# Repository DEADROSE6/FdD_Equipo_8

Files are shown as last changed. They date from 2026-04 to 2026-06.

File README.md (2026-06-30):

# Equipo 8 - SafeWalk AI (Zonas de Construcción)
### Carrera de Ingeniería Ambiental / Informática / Industrial  
**Universidad Peruana Cayetano Heredia**

---

## Descripción del Equipo 

Somos el Equipo 8 del curso Fundamentos de Diseño 2026-1, conformado por estudiantes de la carrera de Ingeniería Ambiental / Informática / Industrial.  

Nuestro objetivo es aplicar la metodología de diseño para generar soluciones innovadoras con impacto social, tecnológico y ambiental.

---

# DESCRIPCIÓN DEL PROYECTO

El equipo 8 desarrollará SafeWalk AI, este sistema emplea un módulo de captura visual conectado a una plataforma de procesamiento embebido para la adquisición y análisis de imágenes en tiempo real, sin conexión a internet. Estas imágenes son procesadas mediante un modelo de visión artificial encargado de detectar la presencia de personas con discapacidad visual a partir de elementos característicos como el bastón blanco y las gafas oscuras. Al identificar estos elementos, el sistema activa automáticamente una alerta sonora mediante un altavoz, con el fin de advertir sobre la proximidad de una zona de obra o peligro.

Este proyecto surge como respuesta a la vulnerabilidad de las personas con discapacidad visual en entornos urbanos dinámicos como las zonas de construcción, y contribuye a los Objetivos de Desarrollo Sostenible 3, 9, 10 y 11, promoviendo la seguridad, la innovación tecnológica y la construcción de ciudades más inclusivas.

---

# CONTEXTO

El crecimiento de las ciudades peruanas conlleva una ejecución constante de obras de construcción, mantenimiento vial e instalación de servicios públicos que modifican de forma temporal el espacio urbano.En el Perú, la Contraloría General de la República ha identificado que a diciembre de 2025 existen 2,416 obras públicas paralizadas a nivel nacional, siendo Lima uno de los departamentos con mayor número de obras detenidas con 167 proyectos paralizados [1].

Esta situación representa un riesgo especialmente grave para las personas con discapacidad visual. A diferencia del resto de peatones, estas personas se orientan en la ciudad mediante rutas memorizadas, apoyándose en referencias como la cantidad de pasos, la textura del suelo y los sonidos del entorno. Cuando una obra clausura o modifica una vereda, esa ruta memorizada deja de coincidir con la realidad, exponiéndose a caídas. Un estudio del Banco Interamericano de Desarrollo concluyó que las personas con discapacidad visual son las más afectadas por las barreras presentes en el entorno urbano, especialmente en espacios donde la infraestructura cambia de forma temporal e imprevista [2]. 

---

# EVIDENCIA DEL PROBLEMA

En el Perú, las obras de construcción en espacios urbanos representan un riesgo concreto para los peatones. Según la Organización Internacional del Trabajo, el sector construcción concentra un alto porcentaje de accidentes a nivel mundial, en parte por las condiciones dinámicas y cambiantes de las obras, y por la señalización frecuentemente insuficiente o inadecuada en estos espacios [3].

Esta problemática se vuelve crítica para las personas con discapacidad visual. Los Censos Nacionales 2017 del INEI revelaron que aproximadamente 1,966,766 personas en el Perú experimentan limitaciones permanentes en la visión, de las cuales el 52.6% reside en zonas urbanas [4]. Estas personas se desplazan guiándose por referencias espaciales memorizadas (cantidad de pasos, texturas del suelo, sonidos del entorno) que les permiten construir rutas mentales conocidas. Cuando una obra clausura o modifica temporalmente una vereda, esa ruta memorizada deja de coincidir con la realidad física, exponiéndolas a caídas, colisiones con materiales de construcción o desvíos involuntarios hacia la calzada vehicular.  

Esta realidad no es abstracta. Roxana, una mujer de 56 años con discapacidad visual residente en Arequipa que utiliza el bastón blanco desde hace más de una década, describe con precisión el impacto que tienen las obras en su desplazamiento diario: "Cada vez que se realizan obras en Arequipa, abren el pavimento y lo dejan amontonado: escombros, arena, tierra, ladrillos y cascajos ocupan las veredas. Todo eso representa un obstáculo para desplazarnos. El bastón se nos atasca en esos huecos". Este testimonio refleja una problemática extendida en las ciudades peruanas, donde las intervenciones en la infraestructura urbana no contemplan mecanismos de aviso accesibles para personas invidentes [5]. 

# JUSTIFICACIÓN DEL PROYECTO

Frente a esta problemática, surge la necesidad de desarrollar soluciones tecnológicas que protejan a las personas con discapacidad visual en zonas de obra. En el Perú, la Norma Técnica A.120 de Accesibilidad Universal del Reglamento Nacional de Edificaciones establece la obligatoriedad de señalización accesible en espacios de construcción, incluyendo señalización podotáctil y auditiva en zonas de riesgo [6]. Sin embargo, su implementación es deficiente: en 2026, el 85% de las inspecciones de CONADIS reportaron incumplimientos en señalética, evidenciando que las normas existentes no se traducen en acciones concretas en los espacios de obra [6]. 

Las medidas tradicionales de seguridad en zonas de obra  (cintas de advertencia, conos de señalización, carteles informativos y barreras físicas) dependen exclusivamente de la percepción visual y no ofrecen ningún tipo de alerta para quienes no pueden verlas. Esta brecha evidencia la necesidad de incorporar soluciones complementarias que utilicen el canal auditivo para transmitir información de riesgo de manera efectiva a las personas invidentes que se aproximan a una zona de obra.

---

# ¿Cómo funciona el proyecto?

## Captura de imágenes
El sistema utiliza un módulo de captura visual integrado en la plataforma de procesamiento embebido, el cual adquiere imágenes del entorno en tiempo real para su análisis inmediato.

## Procesamiento e inferencia
La plataforma embebida recibe y procesa las imágenes mediante un modelo de visión artificial ligero, capaz de detectar elementos característicos de personas con discapacidad visual como el bastón blanco, operando de forma local sin depender de conexión a internet.

## Control del sistema
Una vez procesada la imagen, la plataforma envía señales a una unidad de control que gestiona los dispositivos de salida del sistema, garantizando una respuesta rápida y coordinada.

## Activación de alerta
Al confirmar la detección, se activa automáticamente una alerta sonora que advierte sobre la proximidad de zonas de riesgo.

## Función del sistema
SafeWalk AI busca prevenir accidentes y mejorar la seguridad del peatón con discapacidad visual mediante alertas oportunas, contribuyendo a entornos urbanos más inclusivos y accesibles.

---

# OBJETIVOS DE DESARROLLO SOSTENIBLE

Los Objetivos de Desarrollo Sostenible (ODS) son un conjunto de metas globales establecidas por la Organización de las Naciones Unidas como parte de la Agenda 2030 para el Desarrollo Sostenible, adoptada en el año 2015 por los Estados miembros [7]. Estos objetivos buscan orientar los esfuerzos de los países hacia un desarrollo que permita mejorar la calidad de vida de las personas, reducir las desigualdades y proteger el planeta.

# Nos interesa trabajar en los siguientes Objetivos de Desarrollo Sostenible (ODS):

**ODS 3: Salud y bienestar**

Una de las metas de este objetivo, específicamente la meta 3.6, establece la necesidad de reducir el número de muertes y lesiones causadas por accidentes en entornos de riesgo para el año 2030 [7]. En el contexto urbano, esto implica desarrollar medidas que protejan a los grupos más vulnerables, especialmente en espacios como zonas de construcción, donde existen múltiples peligros asociados a maquinaria, excavaciones y cambios constantes en la infraestructura [8].

Nuestro proyecto se relaciona con este objetivo porque busca reducir el riesgo de accidentes en zonas de construcción para personas con discapacidad visual, contribuyendo a preservar su integridad física y promover su bienestar. 

---

**ODS 9: Industria, innovación e infraestructura**

Una de las metas de este objetivo plantea la necesidad de modernizar la infraestructura e incorporar tecnologías que permitan hacerla más segura, eficiente e inclusiva (9). En el contexto urbano, esto incluye la implementación de sistemas inteligentes capaces de adaptarse a entornos dinámicos como las zonas de construcción.

Nuestro proyecto se vincula con este objetivo porque propone el uso de herramientas tecnológicas como cámaras, inteligencia artificial y algoritmos de detección de objetos en tiempo real para mejorar la seguridad en estos espacios.

---

**ODS 10: Reducción de las desigualdades**

En muchos casos, las personas con discapacidad enfrentan dificultades para desplazarse en el entorno urbano debido a la falta de infraestructura accesible, especialmente en espacios temporales como zonas de obra. Estas limitaciones generan una brecha en el acceso seguro al espacio público.

De acuerdo con la Organización Mundial de la Salud, una gran proporción de la población mundial presenta algún tipo de discapacidad, lo que evidencia la necesidad de desarrollar soluciones inclusivas que mejoren su calidad de vida [7].
Nuestro proyecto se relaciona con este objetivo porque busca reducir estas barreras mediante el uso de tecnología. A través de la detección en tiempo real de personas con discapacidad visual y la generación de alertas auditivas en zonas de construcción.

---

**ODS 11: Ciudades y comunidades sostenibles**

Una de las metas de este objetivo está relacionada con mejorar la seguridad y accesibilidad de los espacios urbanos, garantizando que estos sean inclusivos para todos los ciudadanos, especialmente los grupos más vulnerables [7].

El proyecto propuesto se relaciona con este objetivo porque busca contribuir al desarrollo de ciudades más seguras mediante la incorporación de tecnología en infraestructura temporal. Al implementar un sistema que detecte en tiempo real a personas con discapacidad visual y emita alertas sonoras en zonas de construcción, se promueve una mayor accesibilidad y seguridad en el entorno urbano.

---

## Fotografía del Equipo 
<p align="center">
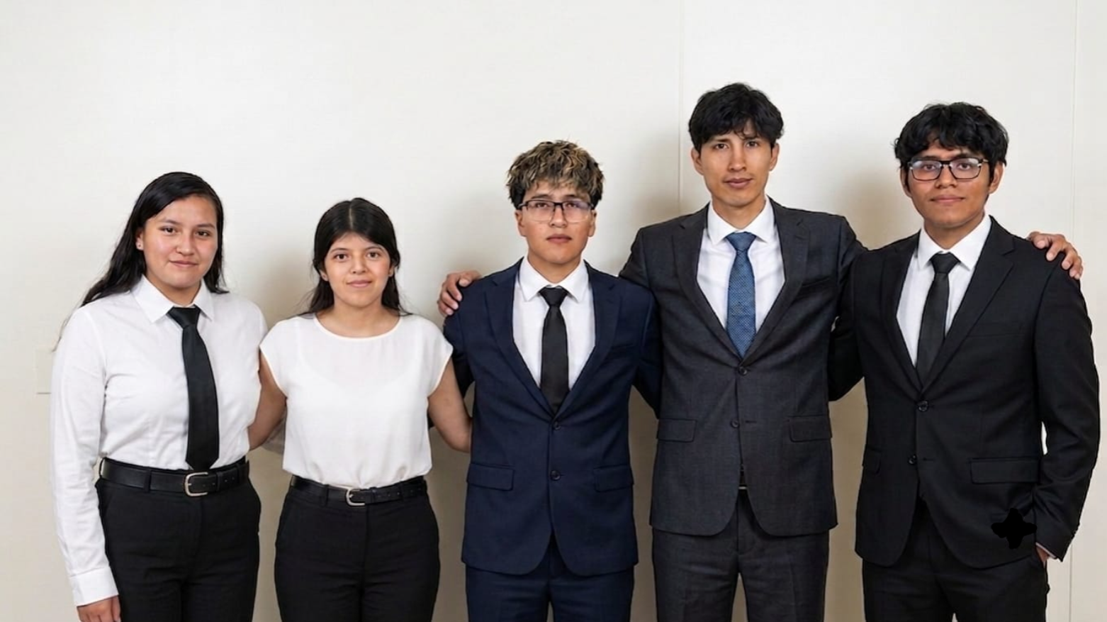
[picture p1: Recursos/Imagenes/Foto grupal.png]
imagen_alumnos_IA

  <em>Figura 1. Fotografía del equipo 8</em>
</p>

---

## Integrantes del Equipo  

| Foto | Nombre | Rol | Intereses |
|---|---|-----|---|
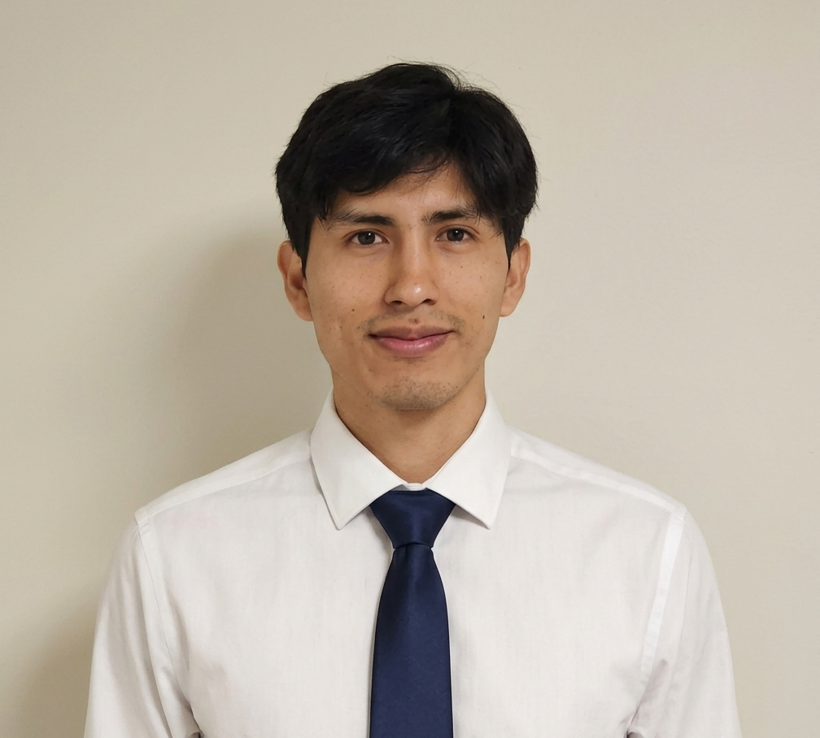
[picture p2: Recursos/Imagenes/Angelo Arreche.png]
|  | **Angello Areche Espeza** | Técnico de Hardware y Prototipos | Diseña, integra y ensambla el prototipo físico del sistema. Se encarga de la selección, conexión y validación de los componentes electrónicos, realizando pruebas de funcionamiento para garantizar la correcta operación del dispositivo. |
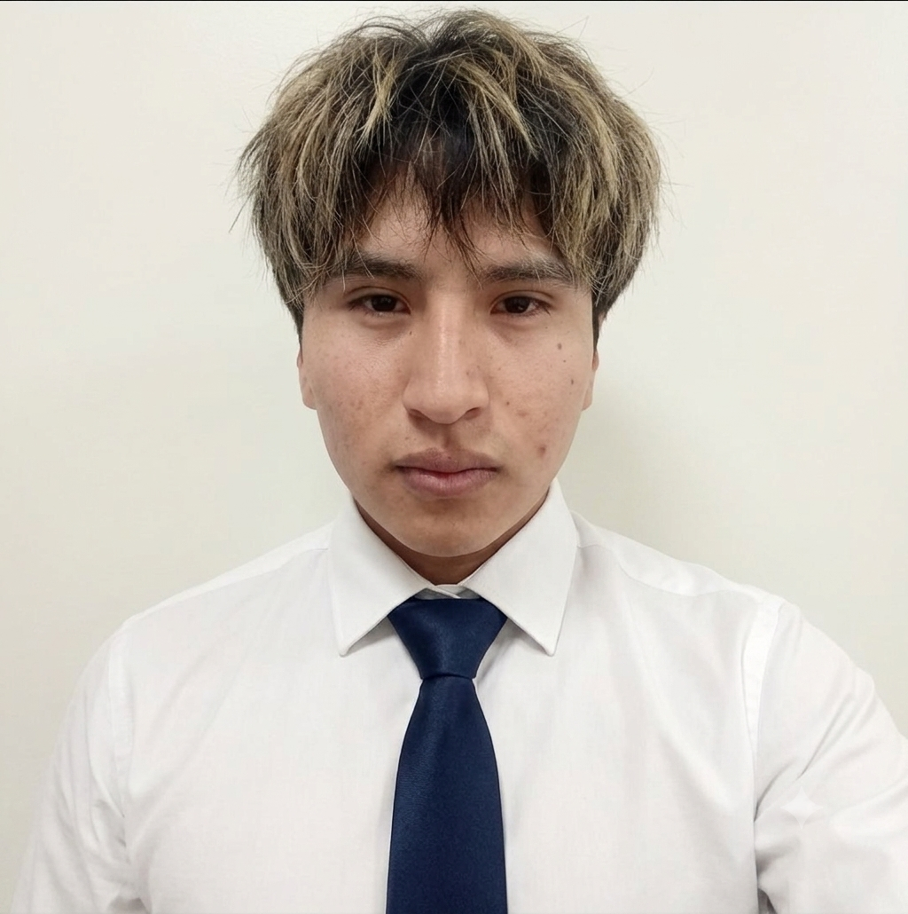
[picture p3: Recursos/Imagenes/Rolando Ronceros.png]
|  | **Rolando Ronceros Huaynapomas** | Diseñador de Arquitectura del Sistema | Define la arquitectura general del proyecto, estableciendo la interacción entre los módulos de hardware y software. Diseña el flujo de funcionamiento del sistema y asegura una integración eficiente entre todos los componentes. |
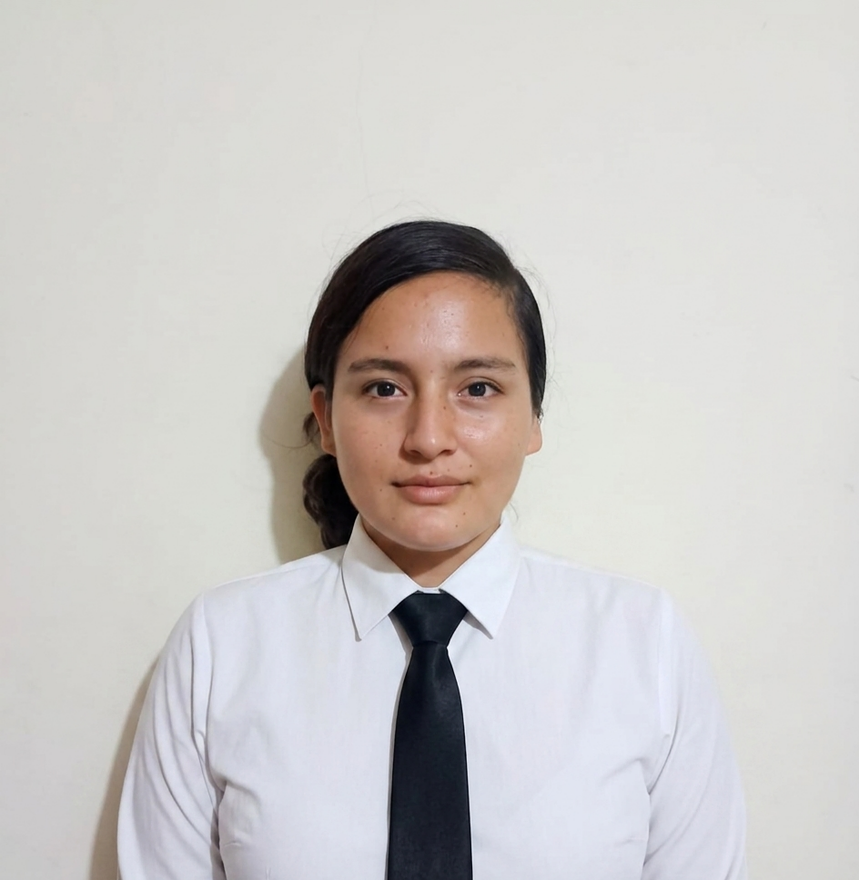
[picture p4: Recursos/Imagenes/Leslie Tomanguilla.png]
|  | **Leslie Stephany Tomanguilla Huaman** | Analista Funcional del Sistema | Analiza la problemática y define los requerimientos funcionales del sistema. Establece las funcionalidades principales y verifica que la solución propuesta responda a las necesidades de las personas con discapacidad visual. |
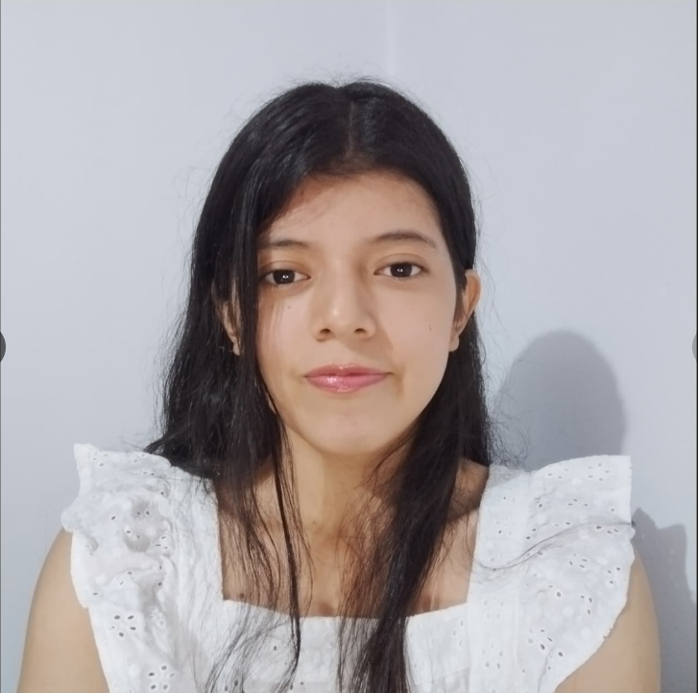
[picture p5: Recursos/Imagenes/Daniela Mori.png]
|  | **Daniela Mori Mendoza** |  Gestora de Documentación | Organiza, redacta y mantiene actualizada toda la documentación del proyecto. Gestiona los informes, la documentación técnica, el repositorio GitHub y el registro de avances para garantizar claridad y organización de la información. |
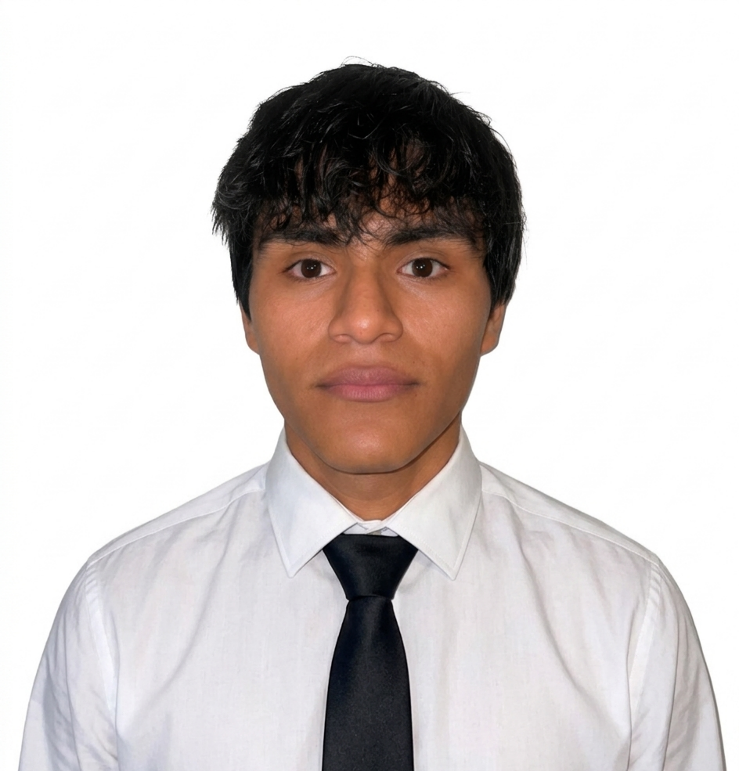
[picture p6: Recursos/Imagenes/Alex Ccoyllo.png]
|  | **Alex Jhosep Ccoyllo Sotelo** | Desarrollador de Sistemas Embebidos | Implementa la lógica de funcionamiento del sistema, integrando el procesamiento de datos provenientes de los sensores y la cámara. Desarrolla las funciones necesarias para la detección del entorno y la generación de alertas por voz, asegurando la comunicación entre los módulos del sistema. |

---

## Resumen Final  
El Equipo 8 está conformado por estudiantes comprometidos con generar un impacto positivo en la sociedad mediante soluciones tecnológicas innovadoras. En esta nueva propuesta, se ha decidido trabajar con los ODS 3, 9, 10 y 11 ,los cuales abordan problemáticas relacionadas con la seguridad ciudadana, el desarrollo de ciudades seguras y la implementación de tecnología para mejorar la calidad de vida.

---

# Referencias Bibliográficas

**1.** Contraloría General de la República del Perú. Informe de obras públicas paralizadas en el territorio nacional a diciembre 2025. https://cdn.www.gob.pe/uploads/document/file/9416533/7715417-informe-de-obras-publicas-paralizadas-en-el-territorio-nacional-a-diciembre-2025f.PDF  

**2.** Rodríguez Porcel M, Lee S, Sandoval D, Tascón Valencia J, Jaramillo PJ, Pedraza L. Auditoría georreferenciada y diagnóstico de accesibilidad peatonal de personas con discapacidad en la primera y última milla de un viaje. https://publications.iadb.org/es/auditoria-georreferenciada-y-diagnostico-de-accesibilidad-peatonal-de-personas-con-discapacidad-en  

**3.** Organización Internacional del Trabajo. Seguridad y salud en la construcción. https://www.ilo.org/es/resource/otros/seguridad-y-salud-en-la-construccion-edicion-revisada  

**4.** Instituto Nacional de Estadística e Informática. Perfiles sociodemográficos de la población con discapacidad https://www.inei.gob.pe/media/MenuRecursivo/publicaciones_digitales/Est/Lib1675/libro.pdf  

**5.** Radio Yaráví Arequipa. Personas con discapacidad visual enfrentan desafíos en calles de Arequipa. https://radioyaravi.org.pe/noticia/informes-especiales/personas-con-discapacidad-visual-enfrentan-desafios-en-calles-de-arequipa/  

**6.** Seminario-Hurtado N, Alfaro Torres HM. Accesibilidad en entornos urbanos para personas con discapacidad visual en el Perú: un análisis normativo. https://revistas.javeriana.edu.co/index.php/cvyu/article/view/41190/ 

**7.** World Health Organization. World Report on Disability. 2011. https://www.who.int/publications/i/item/9789241564182 

**8.** International Labour Organization. Safety and Health in Construction. 2022. https://www.ilo.org/global/publications/books/WCMS_159358/lang--en/index.htm 

**9.** OSHA. Construction Industry Standards. 2024. https://www.osha.gov/laws-regs/regulations/standardnumber/1926

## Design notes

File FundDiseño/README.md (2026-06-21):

# Fundamentos de Diseño

Esta carpeta debe contener todo lo relacionado al avance del proyecto, incluyendo:

* Documentación técnica y de entregables
* Presentaciones
* Informes de Talleres

Aquí se centraliza la información y los archivos necesarios para el desarrollo, seguimiento y presentación del proyecto, facilitando la organización y el acceso a los materiales relevantes.

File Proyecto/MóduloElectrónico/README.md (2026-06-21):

# Esquemáticos

Contiene los esquemáticos electrónicos del proyecto SafeWalk AI, elaborados por el Grupo 08 de Fundamentos de Diseño (UPCH).

* **Esquematico\_VFinal\_DISEÑO.pdf** — Esquemático versión final. Incluye todos los módulos del sistema: sensor de distancia (VL53L1X), módulo principal (XIAO ESP32-S3), sensor de presencia (LD2410C), alerta sonora (PAM8403 + altavoz), reproductor de audio (DFPlayer Mini), LED indicador y módulo de carga (TP4056 + LiPo + XL6009 boost converter).
* **Esquema\_electronico\_E08.pdf** — Esquemático versión E08. Contiene los mismos módulos funcionales que la versión final, sin el módulo de carga ni el reproductor de audio.

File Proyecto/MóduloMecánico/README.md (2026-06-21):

Este apartado contiene los archivos de diseño y modelado 3D (en formato `.stl`) necesarios para la fabricación, impresión y ensamblaje de la estructura física de la estación meteorológica.

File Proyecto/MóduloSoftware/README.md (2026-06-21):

El sistema recopila variables ambientales en tiempo real, procesa los datos localmente y los transmite para su visualización remota.

\---

\## 🛠️ Hardware y Pinout

\### Componentes Principales

\* \*\*Microcontrolador\*\* compatible con Arduino IoT Cloud.

\* \*\*SparkFun Weather Meter Kit\*\* (Anemómetro, Veleta y Pluviómetro).

\* \*\*Sensor BME280\*\* (Temperatura, Humedad y Presión).

\* \*\*Sensor VEML6075\*\* (Luz UVA, UVB e Índice UV).

\* \*\*Sensor AS3935\*\* (Detección de Rayos y Tormentas).

\* \*\*Sensor Higrómetro\*\* (Humedad del Suelo).

\### Asignación de Pines

| Componente / Función | Pin Digital/Analógico |

| :--- | :--- |

| \*\*Dirección del Viento (Veleta)\*\* | Pin 35 |

| \*\*Velocidad del Viento (Anemómetro)\*\* | Pin 14 |

| \*\*Pluviómetro (Lluvia)\*\* | Pin 27 |

| \*\*Interrupción AS3935 (Rayos)\*\* | Pin 17 |

| \*\*Chip Select (CS) AS3935\*\* | Pin 25 |

| \*\*Señal de Humedad de Suelo\*\* | Pin 34 |

| \*\*Alimentación Humedad de Suelo\*\* | Pin 15 |

\---

\## 💻 Configuración del Software

\### Librerías Requeridas

\* `Wire.h` y `SPI.h` (Comunicación nativa).

\* `SparkFun\_Weather\_Meter\_Kit\_Arduino\_Library.h`.

\* `SparkFunBME280.h`.

\* `SparkFun\_VEML6075\_Arduino\_Library.h`.

\* `SparkFun\_AS3935.h`.

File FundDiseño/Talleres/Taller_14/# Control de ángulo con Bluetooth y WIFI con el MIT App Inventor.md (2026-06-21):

# Informe Técnico de Proyecto: Control de Servomotor mediante Bluetooth con ESP32

---

## 1. Introducción
El presente informe detalla el procedimiento de diseño, configuración e implementación de un sistema de control inalámbrico para un servomotor de rango extendido (0° a 270°) utilizando el microcontrolador ESP32 y una aplicación móvil personalizada desarrollada en la plataforma MIT App Inventor. La comunicación entre ambos dispositivos se realiza mediante el protocolo Bluetooth Clásico.

---

## 2. Componentes Utilizados
* **Microcontrolador:** ESP32 (NodeMCU-32S o equivalente).
* **Actuador:** Servomotor de rango extendido (0° - 270°).
* **Software de Desarrollo:** Arduino IDE.
* **Plataforma de Aplicación Móvil:** MIT App Inventor.
* **Conectividad:** Bluetooth Clásico integrado en el chip ESP32.
* **Cableado:** Cables jumper (Macho-Hembra / Macho-Macho) y cable de datos Micro-USB.

---

## 3. Conexiones Físicas (Hardware)
El circuito se estructuró conectando el servomotor directamente a la placa ESP32, alimentándose a través del voltaje provisto por el puerto USB (5V) de la siguiente manera:

| Cable del Servomotor | Función | Pin en el ESP32 |
| :--- | :--- | :--- |
| **Negro** | Tierra (GND) | GND |
| **Rojo** | Alimentación (VCC) | VIN / 5V |
| **Blanco** | Señal de Control (PWM) | GPIO 18 (D18) |

---

## 4. Desarrollo de la Aplicación Móvil (MIT App Inventor)

### 4.1 Componentes de la Interfaz
Se dispuso una interfaz minimalista y funcional compuesta por:
1.  **ListPicker (Selector de Lista):** Renombrado como `Conectar_Bluetooth`. Filtra y muestra los dispositivos Bluetooth vinculados en el smartphone.
2.  **Label (Etiqueta):** Renombrada como `Ángulo`. Muestra en pantalla el valor entero del ángulo actual seleccionado.
3.  **Slider (Deslizador):** Configurado con un valor mínimo (`MinValue`) de **0** y un valor máximo (`MaxValue`) de **270** para ajustarse al límite físico del motor.
4.  **BluetoothClient1:** Componente no visible encargado de la gestión del canal de comunicación inalámbrica.

### 4.2 Lógica de Bloques Utilizada
* **Antes de la Selección (`BeforePicking`):** Se cargan en el `ListPicker` las direcciones y nombres de los dispositivos emparejados en el sistema del celular.
* **Después de la Selección (`AfterPicking`):** Se efectúa la llamada de conexión hacia la dirección MAC del dispositivo seleccionado a través de un bloque puente `evaluate but ignore result` para mitigar restricciones de tipo de datos de algunas versiones de la plataforma.
* **Cambio de Posición del Slider (`PositionChanged`):** Al desplazar el control, el valor flotante se procesa mediante la función matemática `round` para obtener un número entero. Este entero es visualizado en la etiqueta de texto y se envía mediante `.SendText` concatenado con un caracter de escape de nueva línea (`\n`) para actuar como delimitador de mensajes.

---

## 5. Código Fuente Definitivo (Firmware ESP32)

El código implementado en el lenguaje de Arduino utiliza la librería nativa para la emulación del puerto serie por Bluetooth y la librería especializada `ESP32Servo` para la gestión precisa de los pulsos PWM sobre la arquitectura del procesador.

```cpp
#include "BluetoothSerial.h"
#include <ESP32Servo.h>

// Instancia para el control del Bluetooth y del Servomotor
BluetoothSerial ESP_BT;
Servo miServo;

// Definición de constantes del hardware
const int pinServo = 18; 

void setup() {
  // Inicialización del puerto serie físico para depuración técnica
  Serial.begin(115200);
  
  // Inicialización del módulo Bluetooth con el identificador de red
  ESP_BT.begin("Prueba_ESP32"); 
  Serial.println("Dispositivo listo con control de Servo (Rango: 0-270).");

  // Configuración de temporizadores internos de la librería ESP32Servo
  ESP32PWM::allocateTimer(0);          
  miServo.setPeriodHertz(50); // Frecuencia de actualización estándar para servos (50Hz)
  
  // Acoplamiento del pin con los anchos de pulso en microsegundos mínimos y máximos
  // Ajustados para cubrir el espectro angular completo de 270 grados
  miServo.attach(pinServo, 500, 2500); 
  
  // Posicionamiento inicial de seguridad
  miServo.write(0); 
}

void loop() {
  // Verificación de bytes disponibles en el buffer del módulo Bluetooth
  if (ESP_BT.available()) {
    
    // Lectura de la cadena de texto entrante hasta encontrar el delimitador '\n'
    String datosRecibidos = ESP_BT.readStringUntil('\n');
    datosRecibidos.trim(); // Eliminación de espacios en blanco o caracteres basura

    // Validación de consistencia del dato extraído
    if (datosRecibidos.length() > 0) {
      int angulo = datosRecibidos.toInt(); // Conversión de la cadena de texto a entero

      // Control de límites lógicos para proteger los engranajes del motor
      if (angulo >= 0 && angulo <= 270) {
        miServo.write(angulo); // Escritura de la posición angular en el actuador
        
        // Retroalimentación visual en el terminal de la computadora
        Serial.print("Moviendo servo a: ");
        Serial.print(angulo);
        Serial.println(" grados.");
      }
    }
  }
  delay(10); // Retraso de cortesía para estabilizar las tareas de fondo del procesador
}
```
---

## 6. Procedimiento de Carga y Pruebas
1. **Instalación de Librerías:** Desde el gestor de tarjetas del Arduino IDE se integró la librería `ESP32Servo` de Kevin Harrington, solventando el error de compilación por falta de dependencias.
2. **Carga del Firmware (Bootloader):** Durante el proceso de compilación y subida, ante la secuencia de conexión (`Connecting......`), se hizo uso del bypass de hardware presionando el botón físico **BOOT** integrado en el ESP32 para permitir la escritura en la memoria Flash.
3. **Sincronización:** Se habilitó el servicio de Bluetooth y Localización en el terminal Android, vinculando exitosamente el dispositivo bajo el nombre de `Prueba_ESP32`.
4. **Prueba de la Aplicación:** Se desplegó la interfaz mediante *MIT AI2 Companion*, efectuando la conexión y verificando la transmisión asíncrona de datos tanto en la pantalla del móvil (actualización del Label) como en el Monitor Serie a una tasa de transferencia de `115200` baudios.

---

## 7. Conclusiones
El proyecto cumple exitosamente con los objetivos planteados. El uso del delimitador `\n` garantiza que el ESP32 segmente de manera asíncrona y exacta las cadenas de caracteres entrantes por el flujo serie inalámbrico, evitando el encolamiento de datos erróneos. El ajuste de los tiempos de ancho de pulso en microsegundos (`500` a `2500` µs) en la función `attach` permitió aprovechar el torque y el recorrido completo de los 270° del servomotor de manera lineal y fluida con respecto al deslizador de la aplicación móvil.

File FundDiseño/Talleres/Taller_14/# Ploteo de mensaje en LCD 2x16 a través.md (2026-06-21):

# Informe de desarrollo: Comunicación Bluetooth entre ESP32 y pantalla LCD I2C mediante MIT App Inventor

## 1. Título del proyecto

**Visualización de mensajes en una pantalla LCD I2C mediante comunicación Bluetooth con ESP32 y MIT App Inventor**

---

## 2. Objetivo

El objetivo de la actividad fue implementar un sistema que permita enviar un mensaje escrito desde una aplicación móvil creada en MIT App Inventor hacia un microcontrolador ESP32 mediante comunicación Bluetooth.

El mensaje recibido por el ESP32 debía mostrarse en una pantalla LCD 16x2 con módulo I2C.

---

## 3. Materiales utilizados

Para el desarrollo de la actividad se utilizaron los siguientes materiales:

- ESP32 DevKit V1.
- Pantalla LCD 16x2 con módulo I2C.
- Cables Dupont.
- Cable USB para programar el ESP32.
- Celular Android.
- Plataforma MIT App Inventor.
- Arduino IDE.

### Librerías

- BluetoothSerial
- Wire
- LiquidCrystal_I2C

---

## 4. Descripción general del funcionamiento

El sistema funciona de la siguiente manera:

1. El usuario escribe un mensaje en una aplicación móvil creada en MIT App Inventor.
2. Al presionar un botón, la aplicación envía el mensaje por Bluetooth al ESP32.
3. El ESP32 recibe el texto enviado desde el celular.
4. Finalmente, el mensaje se muestra en la pantalla LCD I2C.

La pantalla LCD utilizada cuenta con un módulo I2C en la parte posterior, por lo que solo se emplearon cuatro pines de conexión:

- GND
- VCC
- SDA
- SCL

No fue necesario utilizar potenciómetro externo ni resistencia, ya que el módulo I2C de la pantalla incluye un potenciómetro integrado para regular el contraste.

---

## 5. Conexiones realizadas

Las conexiones entre el ESP32 y la pantalla LCD I2C fueron las siguientes:

| Pantalla LCD I2C | ESP32 DevKit V1 |
|---|---|
| GND | GND |
| VCC | 5V / VIN |
| SDA | GPIO 21 |
| SCL | GPIO 22 |

Se utilizó el pin GPIO 21 del ESP32 para la línea SDA y el pin GPIO 22 para la línea SCL, que son los pines comúnmente usados para comunicación I2C en el ESP32.

---

## 6. Programación del ESP32

Para programar el ESP32 se utilizó Arduino IDE. Primero se instalaron las librerías necesarias para controlar la pantalla LCD I2C y utilizar la comunicación Bluetooth.

La librería principal para la pantalla fue:

```cpp
#include <LiquidCrystal_I2C.h>
```

También se utilizaron las librerías:

```cpp
#include <BluetoothSerial.h>
#include <Wire.h>
```

El código cargado en el ESP32 permite:

- Iniciar el Bluetooth con el nombre `ESP32_LCD_BT`.
- Inicializar la pantalla LCD.
- Esperar mensajes enviados desde la aplicación móvil.
- Mostrar el mensaje recibido en la pantalla LCD.
- Dividir el mensaje en dos líneas si supera los 16 caracteres.

---

## 7. Código utilizado en el ESP32

```cpp
#include <BluetoothSerial.h>
#include <Wire.h>
#include <LiquidCrystal_I2C.h>

// Bluetooth del ESP32
BluetoothSerial SerialBT;

// LCD I2C 16x2
// Direccion comun: 0x27
// Si no funciona, cambiar 0x27 por 0x3F
LiquidCrystal_I2C lcd(0x27, 16, 2);

String mensaje = "";

void setup() {

  Serial.begin(115200);

  // Iniciar I2C en ESP32
  // SDA = GPIO 21, SCL = GPIO 22
  Wire.begin(21, 22);

  // Iniciar LCD
  lcd.init();
  lcd.backlight();
  lcd.clear();

  lcd.setCursor(0, 0);
  lcd.print("Esperando BT");

  lcd.setCursor(0, 1);
  lcd.print("ESP32_LCD_BT");

  // Iniciar Bluetooth
  SerialBT.begin("ESP32_LCD_BT");

  Serial.println("Bluetooth iniciado");
  Serial.println("Nombre: ESP32_LCD_BT");
}

void loop() {

  // Si llega un mensaje desde App Inventor por Bluetooth
  if (SerialBT.available()) {

    mensaje = SerialBT.readStringUntil('\n');
    mensaje.trim();

    Serial.print("Mensaje recibido: ");
    Serial.println(mensaje);

    lcd.clear();

    // Si el mensaje tiene 16 caracteres o menos
    if (mensaje.length() <= 16) {
      lcd.setCursor(0, 0);
      lcd.print(mensaje);
    }

    // Si el mensaje tiene más de 16 caracteres
    else {
      lcd.setCursor(0, 0);
      lcd.print(mensaje.substring(0, 16));

      lcd.setCursor(0, 1);
      lcd.print(mensaje.substring(16, 32));
    }
  }
}
```

---

## 8. Desarrollo de la aplicación en MIT App Inventor

En MIT App Inventor se creó una aplicación sencilla con los siguientes componentes:

| Componente | Función |
|---|---|
| Label | Mostrar el título de la aplicación |
| ListPicker | Seleccionar el dispositivo Bluetooth |
| TextBox | Escribir el mensaje que se desea enviar |
| Button | Enviar el mensaje al ESP32 |
| Label | Mostrar el estado de conexión |
| BluetoothClient | Permitir la comunicación Bluetooth |

La aplicación permite seleccionar el dispositivo Bluetooth previamente emparejado, conectarse al ESP32 y enviar el texto escrito en el cuadro de texto.

---

## 9. Componentes usados en MIT App Inventor

Los componentes usados fueron:

- Label1: título de la aplicación.
- ListPicker1: botón para seleccionar el Bluetooth.
- TextBox1: cuadro donde se escribe el mensaje.
- Button1: botón para enviar el mensaje.
- Label2: muestra el estado de la conexión.
- BluetoothClient1: componente no visible para la comunicación Bluetooth.

---

## 10. Bloques implementados en MIT App Inventor

### 10.1. Bloque para mostrar dispositivos Bluetooth

Este bloque permite que, antes de seleccionar un dispositivo, se cargue la lista de dispositivos Bluetooth disponibles y emparejados en el celular.

```text
when ListPicker1.BeforePicking
    set ListPicker1.Elements to BluetoothClient1.AddressesAndNames
```

### 10.2. Bloque para conectar con el ESP32

Este bloque permite conectarse al dispositivo Bluetooth seleccionado. Si la conexión es exitosa, se muestra el mensaje "Estado: conectado". Si no se logra conectar, se muestra un mensaje de error.

```text
when ListPicker1.AfterPicking
    if call BluetoothClient1.Connect address ListPicker1.Selection
    then
        set Label2.Text to "Estado: conectado"
    else
        set Label2.Text to "No se pudo conectar"
```

### 10.3. Bloque para enviar el mensaje

Este bloque permite enviar el texto escrito en el TextBox hacia el ESP32. Se agregó el salto de línea `\n` al final del mensaje, ya que el código del ESP32 lee el texto hasta encontrar ese carácter.

```text
when Button1.Click
    if BluetoothClient1.IsConnected
    then
        call BluetoothClient1.SendText text join TextBox1.Text "\n"
        set Label2.Text to "Mensaje enviado"
    else
        set Label2.Text to "Primero conecta Bluetooth"
```

---

## 11. Pruebas realizadas

Después de cargar el programa en el ESP32, se abrió el Monitor Serial a 115200 baudios.

Se verificó que el ESP32 iniciara correctamente mostrando el mensaje:

```text
Bluetooth iniciado
Nombre: ESP32_LCD_BT
```

Luego se revisó que la pantalla LCD encendiera y mostrara el mensaje inicial:

```text
Esperando BT
ESP32_LCD_BT
```

Después, se probó la aplicación móvil siguiendo estos pasos:

1. Se encendió el ESP32.
2. Se abrió la aplicación creada en MIT App Inventor.
3. Se presionó el botón para conectar Bluetooth.
4. Se seleccionó el dispositivo correspondiente al ESP32.
5. Se escribió un mensaje en el cuadro de texto.
6. Se presionó el botón de enviar.
7. El mensaje enviado se mostró en la pantalla LCD.

---

## 12. Observaciones

Durante el desarrollo se identificó que la pantalla LCD tenía un módulo I2C integrado, por lo que no era necesario realizar la conexión tradicional usando los pines:

- RS
- RW
- E
- D4
- D5
- D6
- D7

Esto permitió simplificar el circuito, utilizando únicamente cuatro cables.

También se observó que el contraste de la pantalla puede regularse usando el pequeño potenciómetro integrado en el módulo I2C de la parte posterior de la pantalla.

En caso de que la pantalla no muestre texto, se puede probar cambiando la dirección I2C de:

```cpp
LiquidCrystal_I2C lcd(0x27, 16, 2);
```

por:

```cpp
LiquidCrystal_I2C lcd(0x3F, 16, 2);
```

---

## 13. Problemas encontrados

Durante las pruebas se observó que el ESP32 mostraba en el Monitor Serial un mensaje relacionado con el arranque del sistema:

```text
Core dump data check failed
```

Sin embargo, el programa continuó ejecutándose correctamente, ya que luego apareció el mensaje:

```text
Bluetooth iniciado
Nombre: ESP32_LCD_BT
```

Por lo tanto, se concluyó que el ESP32 estaba funcionando correctamente y que el Bluetooth se había iniciado.

También se consideró que, si el celular no detecta el dispositivo Bluetooth, se debe verificar lo siguiente:

- Que el ESP32 esté encendido.
- Que el programa esté cargado correctamente.
- Que el celular sea Android.
- Que se esté usando un ESP32 compatible con Bluetooth clásico.
- Que el Bluetooth del celular esté activado.
- Que el ESP32 se busque desde los ajustes Bluetooth del celular antes de usar la app.

---

## 14. Conclusión

Se logró implementar un sistema de comunicación Bluetooth entre una aplicación móvil creada en MIT App Inventor y un ESP32.

El mensaje escrito desde el celular fue enviado correctamente al microcontrolador y mostrado en una pantalla LCD 16x2 con módulo I2C.

Esta actividad permitió comprender el uso de la comunicación Bluetooth en el ESP32, el manejo de pantallas LCD mediante I2C y la integración entre hardware y una aplicación móvil desarrollada de manera visual en MIT App Inventor.

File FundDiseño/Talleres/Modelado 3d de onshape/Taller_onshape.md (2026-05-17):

\[Visitar página](https://cad.onshape.com/documents/761ca72c0d35637bf1310327/w/2c1eae061603c23732c825c3/e/0067304d9aebd7f837c99007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\&uiState=6a09e681478a19db214c9cd3)

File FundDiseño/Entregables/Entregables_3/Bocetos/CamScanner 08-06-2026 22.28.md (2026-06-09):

z Amplificador de audio = (PAM8403) 

| 

. ae Vista lateral derecha Vista isometrica 

| 

**==> picture [565 x 170] intentionally omitted <==**

**----- Start of picture text -----**<br>
mp3 — A<br>or | o— . =-<br>a r Sensor de — (RN ws =<br>P mm | oiistancia «=, NY 7<br>**----- End of picture text -----**<br>

O05 or 

con _ XIAO SEEED 

Escaneado con CamScanner

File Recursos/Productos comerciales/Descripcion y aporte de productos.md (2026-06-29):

# Productos Comerciales

## Descripción general
Esta sección presenta productos comerciales relacionados con la asistencia a personas con discapacidad visual. Estos dispositivos incorporan tecnologías como inteligencia artificial, sensores y sistemas de detección para mejorar la movilidad, orientación y seguridad de los usuarios.

---

## 1. OrCam MyEye

**Descripción:** Dispositivo portátil basado en inteligencia artificial que se acopla a unas gafas y permite reconocer textos, rostros, objetos y productos, proporcionando la información mediante audio en tiempo real.

**Aporte:** Constituye una referencia para el desarrollo de sistemas de asistencia visual, demostrando la aplicación de visión por computadora e inteligencia artificial para mejorar la autonomía de las personas con discapacidad visual.

---

## 2. WeWALK Smart Cane

**Descripción:** Bastón inteligente equipado con sensores para la detección de obstáculos, navegación por voz y funciones de asistencia que facilitan el desplazamiento seguro de personas con discapacidad visual.

**Aporte:** Sirve como referencia en la integración de sensores y tecnologías de asistencia para mejorar la movilidad, la orientación y la seguridad durante el desplazamiento.

---

## 3. Sunu Band

**Descripción:** Pulsera inteligente que utiliza sensores ultrasónicos para detectar obstáculos cercanos y comunicar la información al usuario mediante vibraciones hápticas.

**Aporte:** Demuestra el uso de tecnologías de detección y retroalimentación sensorial como complemento a los sistemas de asistencia, contribuyendo a una navegación más segura para personas con discapacidad visual.

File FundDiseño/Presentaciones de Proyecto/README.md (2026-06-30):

# SafeWalk AI

**Curso:** Fundamentos de Diseño  
**Grupo:** 08

---

> *"Imagina que memorizaste cada paso de tu camino al trabajo. Sabes exactamente cuántos pasos hay hasta la esquina, la textura del piso, los sonidos del entorno. Un día, una obra de construcción cambia todo eso... y nadie te avisa."*

---

## Problema

En el Perú, más de 1.9 millones de personas tienen limitaciones permanentes en la visión, y más de la mitad vive en zonas urbanas [1]. Cuando una obra altera una vereda, sus rutas memorizadas dejan de coincidir con la realidad, exponiéndolas a accidentes. La señalización actual es insuficiente y poco accesible [2]. Nadie las avisa sobre los riesgos en su camino.

**¿Cómo podemos advertir de manera oportuna a una persona con discapacidad visual cuando se aproxima a una zona de construcción que representa un riesgo para su seguridad?**

---

## Solución

SafeWalk AI detecta en tiempo real a personas con bastón blanco en zonas de construcción y les emite una alerta sonora automática antes de que lleguen al peligro.

| Característica | Descripción |
|---|---|
| **Accesible** | Utiliza alertas sonoras, un medio de comunicación adecuado para usuarios con limitaciones visuales. |
| **Autónomo** | Funciona de manera automática sin requerir intervención de operadores o personal de la obra. |
| **Eficiente** | Detecta en tiempo real la presencia de personas con discapacidad visual y genera alertas oportunas. |
| **Asequible** | Emplea hardware embebido de bajo costo, facilitando su implementación en diferentes zonas de construcción. |

---

## Propuesta de Valor

### ¿Por qué SafeWalk AI es mejor que los competidores existentes?

No existe un sistema equivalente en el mercado peruano para obras urbanas.

Los sistemas de asistencia para invidentes que existen (apps como BlindSquare, bastones inteligentes) están orientados al usuario individual, no al entorno.

**¿Cómo se está abordando el problema ahora?**
- Conos y cachacos
- Cintas de advertencia
- Vigilantes humanos

**¿Qué ofrecemos nosotros?**

SafeWalk AI les da a las empresas constructoras una herramienta concreta, portátil y de bajo costo para cumplir con su obligación legal de garantizar entornos accesibles [5], protegiendo al mismo tiempo al más de un millón de personas con discapacidad visual que viven en zonas urbanas del Perú.

### Análisis de la competencia

| Competidor | Geografía | Orientado al público | Precios | Usabilidad |
|---|---|---|---|---|
| *(Competidor 1)* | Países de Asia, Medio Oriente y Europa | Alto | — | 4/5 |
| *(Competidor 2)* | Nivel mundial | Medio | — | 4.5/5 |

---

## Modelo de Negocio

### ¿Cómo generamos ingresos?

Nuestro modelo se basa en el **alquiler por obra**. SafeWalk AI se instala directamente sobre el cachaco existente y se cobra por el tiempo que dura la construcción. Esto lo hace accesible para cualquier obra, grande o pequeña, y nos permite escalar rápidamente.

### Monetización, precio y canales

- **Precio:** S/. 300 a S/. 500 mensuales por dispositivo, incluyendo inversión, mano de obra, traslado y mantenimiento.
- **Validación:** Buscaremos el respaldo de CONADIS para abrir puertas con empresas constructoras.
- **Sostenibilidad:** El dispositivo se reutilizará en cada obra, haciendo el modelo sostenible y escalable.

---

## Estrategia

### ¿Quiénes son nuestros clientes?

- **Corto plazo:** Empresas constructoras
- **Largo plazo:** Municipalidades / Empresas de señalización vial

### ¿Cómo llegaríamos a ellos?

1. Llegamos a la empresa constructora mediante una **prueba piloto gratuita** en una obra real de Lima a cambio de retroalimentación, validando el sistema en el campo.
2. Presentamos SafeWalk AI a **CONADIS** para obtener su aval como herramienta de accesibilidad.

---

## Tracción

### ¿Qué hemos logrado?

- **Carcasa en PLA** diseñada e impresa en 3D con sistema de montaje para cachacos.
- **Modelo entrenado** con 500 imágenes con 2 clases de detección.
- **Prototipo funcional** del sistema de detección con XIAO ESP32S3 y Roboflow.

---

## Equipo

Un equipo con habilidades complementarias: desde el componente físico hasta el software, pasando por el análisis y la documentación. Todo cubierto internamente.

| Integrante | Rol |
|---|---|
| Areche Espeza, Angello | Construye y ensambla el hardware del sistema |
| Ronceros Huaynapomas, Rolando | Diseña cómo se conecta todo: hardware, software y flujo de datos |
| Tomanguilla Huaman, Leslie | Asegura que las soluciones respondan al problema real |
| Mori Mendoza, Daniela | Mantiene toda la documentación clara y organizada |
| Ccoyllo Sotelo, Alex | Programa la lógica e inteligencia del sistema |

---

## Pedido

### ¿Qué necesitamos para dar el siguiente paso?

1. **Acceso a una obra real en Lima** para validar el sistema en el campo.
2. **Apoyo para ampliar nuestro dataset** a 2,000 imágenes y superar el 80% de precisión.
3. **Alianzas con empresas de señalización vial o municipalidades** para una prueba piloto oficial.

---

## Referencias

1. Instituto Nacional de Estadística e Informática. Perfiles sociodemográficos de la población con discapacidad [Internet]. Lima: INEI; 2019 [citado 2026]. Disponible en: https://www.inei.gob.pe/media/MenuRecursivo/publicaciones_digitales/Est/Lib1675/libro.pdf

2. Organización Internacional del Trabajo. Seguridad y salud en la construcción. Edición revisada [Internet]. Ginebra: OIT; 2022 [citado 2026]. Disponible en: https://www.ilo.org/es/resource/otros/seguridad-y-salud-en-la-construccion-edicion-revisada

3. Congreso de la República del Perú. Ley N° 29973: Ley General de la Persona con Discapacidad [Internet]. Lima: Congreso de la República; 2012 [citado 2026 jun 26]. Disponible en: https://www.gob.pe/institucion/conadis/informes-publicaciones/223512-ley-general-de-la-persona-con-discapacidad-y-su-reglamento

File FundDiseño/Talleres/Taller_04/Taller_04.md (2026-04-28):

# PATENTES RELACIONADAS CON NUESTRO PROYECTO

---

## PATENTE 1

| CAMPO | INFORMACIÓN |
|---|---|
| **TÍTULO** | MÓDULO ÓPTICO PARA SEMÁFOROS PEATONALES CON INDICACIÓN ACÚSTICA PARA PERSONAS CON DISCAPACIDAD VISUAL |
| **N° PUBLICACIÓN** | [ES1073627U](https://worldwide.espacenet.com/patent/search?q=pn%3DES1073627U) |
| **CIP** | G08G1/005 |

| RESUMEN | IMÁGENES |
|---|---|
| La patente describe un módulo óptico para semáforos peatonales que incorpora iluminación LED y señales acústicas para ayudar a personas con discapacidad visual. El sistema integra un módulo electrónico que controla simultáneamente las luces y el sonido, permitiendo indicar de forma clara cuándo es seguro cruzar. Incluye una carcasa compatible con semáforos convencionales y un altavoz integrado para emitir las alertas. Su objetivo es mejorar la accesibilidad en cruces peatonales. | <br> |

🔗 [Ver patente](https://worldwide.espacenet.com/patent/search/family/043447627/publication/ES1073627U?q=pn%3DES1073627U)

---

## PATENTE 2

| CAMPO | INFORMACIÓN |
|---|---|
| **TÍTULO** | SISTEMA Y MÉTODO PARA LA DETECCIÓN DE PEATONES MEDIANTE PROCESAMIENTO DE IMÁGENES |
| **N° PUBLICACIÓN** | [US10719707B2](https://worldwide.espacenet.com/patent/search?q=pn%3DUS2021369545A1) |
| **CIP** | A61H3/06 ; G01S15/08 ; G01S15/52 ; G01S15/89 ; G01S7/292 ; G06K9/62 ; G10L13/027 |

| RESUMEN | IMÁGENES |
|---|---|
| La patente describe un dispositivo portátil de navegación que guía al usuario mediante vibraciones (sistema háptico) en lugar de señales visuales o auditivas. Utiliza GPS para determinar la posición y genera patrones táctiles que indican la dirección. Incluye placa electrónica, batería y actuadores en formato pulsera, y puede conectarse a un móvil. | <br> |

🔗 [Ver patente](https://worldwide.espacenet.com/patent/search/family/078706485/publication/US2021369545A1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)

---

## PATENTE 3

| CAMPO | INFORMACIÓN |
|---|---|
| **TÍTULO** | DISPOSITIVO HÁPTICO VIBRATORIO PARA CIEGOS |
| **N° PUBLICACIÓN** | [US10371544B2](https://patents.google.com/patent/US10719707B2/en) |
| **CIP** | A61H3/06 ; G01C21/36 ; G06F3/01 ; A61F9/08 ; G09B21/00 |

| RESUMEN | IMÁGENES |
|---|---|
| La patente describe un sistema de detección de peatones mediante procesamiento de imágenes en tiempo real. Analiza el entorno, identifica la presencia de personas y valida la detección con características del cuerpo humano, logrando alta precisión incluso en condiciones complejas. | <br> |

🔗 [Ver patente](https://patents.google.com/patent/US10719707B2/en)

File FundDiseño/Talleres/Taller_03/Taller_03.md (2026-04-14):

**UNIVERSIDAD PERUANA CAYETANO HEREDIA**

**FACULTAD DE CIENCIAS E INGENIERÍA**

                	

**Proyecto de Fundamentos de Diseño**

**SafeWalk IA**

**Docentes:**

●       Mugaburu Celi, Marco Antonio  
●       Chan Rios, Renzo Jose  
●       Jacinto Calderon, Cristhian Gustavo  
●       Rivera Tito, Harry Anderson

**Nombres y apellidos del estudiante:**

●  	Areche Espeza, Angello  
●  	Mori Mendoza, Daniela  
●  	Tomanguilla Huaman, Leslie Stephany  
●  	Ronceros Huaynapomas, Rolando Smith  
●  	Ccoyllo Sotelo, Alex

2026

## **Planteamiento del problema**

### **Contexto**

La movilidad urbana es un aspecto fundamental para el desarrollo de las ciudades, ya que permite el desplazamiento seguro de las personas dentro del espacio público. Sin embargo, en muchos países, incluyendo el Perú, la seguridad vial continúa siendo un desafío importante, especialmente para los peatones, quienes representan uno de los grupos más vulnerables dentro del sistema de tránsito. La interacción constante entre vehículos y peatones en las vías urbanas, sumada a factores como el alto flujo vehicular, la falta de infraestructura adecuada y el incumplimiento de normas de tránsito, incrementa el riesgo de accidentes. Estudios realizados en Lima evidencian que los peatones tienden a elegir rutas más cortas para cruzar, influenciados por la ubicación de elementos urbanos, y que la congestión vehicular puede inducir comportamientos más arriesgados que aumentan el riesgo de accidentes (1).

Esta situación se vuelve aún más crítica para las personas con discapacidad visual, quienes enfrentan mayores dificultades al momento de desplazarse de forma autónoma por el espacio público. Un estudio del Banco Interamericano de Desarrollo que evaluó la accesibilidad peatonal en rutas urbanas con participación de personas con distintos tipos de discapacidad concluyó que las personas con discapacidad visual son las más afectadas por las barreras presentes en el entorno urbano, especialmente en los recorridos asociados a cruces peatonales y paradas de transporte público (2). En muchos casos, los sistemas de señalización existentes no están diseñados considerando plenamente las necesidades de accesibilidad de estas personas, lo que limita su capacidad de desplazarse con seguridad ante situaciones de riesgo vial.

### **Evidencia del problema**

En el Perú, los accidentes de tránsito representan un problema significativo de seguridad pública. De acuerdo con información del Ministerio de Transportes y Comunicaciones del Perú, entre enero y julio de 2022 se registraron más de 47,000 siniestros de tránsito, los cuales ocasionaron 1,853 fallecidos y más de 30,000 personas lesionadas (3). Dentro de estas cifras, los peatones constituyen uno de los grupos más afectados, representando aproximadamente el 25.7% de las personas fallecidas en accidentes de tránsito. A nivel local, según el Observatorio Nacional de Seguridad Vial, solo en el departamento de Lima se registraron aproximadamente 1,303 accidentes de tránsito en 2023, atribuidos principalmente a las malas condiciones de las carreteras y la inadecuada señalización vial (3).

Esta situación se agrava para las personas con discapacidad visual. Los Censos Nacionales 2017 del INEI revelaron que aproximadamente 1,966,766 personas en el Perú experimentan dificultades o limitaciones permanentes en la visión, siendo Lima Metropolitana la zona con mayor concentración de esta población, representando el 65.8% del total (4). Estas personas enfrentan barreras concretas al desplazarse por la ciudad: la ausencia de semáforos sonoros, la falta de pisos podotáctiles y la inadecuada señalización en los cruces peatonales limitan su capacidad de circular de forma segura e independiente (5).

Estos datos evidencian que el entorno vial presenta riesgos importantes para quienes se desplazan a pie, especialmente en intersecciones y cruces peatonales. Para las personas con discapacidad visual, este riesgo es aún mayor. Como señalan Seminario-Hurtado y Alfaro Torres (5), las barreras físicas en el entorno urbano no solo limitan la movilidad de estas personas, sino que también restringen su acceso a servicios esenciales, afectando directamente su calidad de vida y autonomía.

La magnitud de esta población contrasta con la precariedad de las condiciones de accesibilidad que enfrentan en el espacio público. Según el BID, las rutas peatonales asociadas al transporte urbano presentan deficiencias críticas para las personas con discapacidad visual, siendo este grupo el más perjudicado por la falta de infraestructura adaptada (2). Esta brecha entre las necesidades reales de la población y la oferta de infraestructura urbana refleja una problemática sistémica que afecta directamente la seguridad y autonomía de las personas con discapacidad visual en los espacios públicos.

### **Justificación del proyecto**

Frente a esta problemática, surge la necesidad de desarrollar soluciones que contribuyan a mejorar la seguridad de los peatones en los espacios urbanos. Si bien el Estado peruano ha establecido un marco legal orientado a garantizar la accesibilidad, la implementación de estas normativas no ha sido efectiva, ya que persisten barreras físicas, sociales e institucionales, entre ellas la falta de asignación de un presupuesto público razonable y la ausencia de mecanismos de fiscalización adecuados (5).

En este sentido, entre las medidas recomendadas para mejorar la accesibilidad en entornos urbanos para personas con discapacidad visual se encuentran los semáforos sonoros, los pisos podotáctiles y los carteles con información en braille; sin embargo, su aplicación no es generalizada ni adecuada en el Perú (5). Esto evidencia que las soluciones tradicionales son insuficientes y que se requiere innovar en la forma en que las alertas de riesgo llegan específicamente a las personas invidentes en los cruces peatonales.

Por ello, nuestro proyecto propone el desarrollo de SafeWalk AI, un sistema inteligente que, mediante el uso de visión artificial con YOLO implementado en un NVIDIA Jetson Nano y una cámara, detecta en tiempo real objetos asociados a personas con discapacidad visual —específicamente el bastón blanco y las gafas oscuras— en cruces peatonales, y genera una alerta sonora a través de un altavoz instalado en el semáforo. Este aviso busca beneficiar tanto a la persona invidente como a los demás peatones presentes, quienes al escuchar la alerta pueden brindar apoyo. Investigaciones previas han demostrado la viabilidad de sistemas similares basados en Raspberry Pi con redes neuronales convolucionales para la detección de objetos en tiempo real (6, 7, 8). Dado que la brecha de accesibilidad peatonal para personas con discapacidad visual en espacios urbanos persiste pese a la normativa existente (2), este sistema busca contribuir a una movilidad urbana más segura e inclusiva, alineándose con los Objetivos de Desarrollo Sostenible, especialmente los ODS 3, 9, 10 y 11 (9).

**Estado del arte**

**Sistemas de asistencia personal para personas con discapacidad visual**

La línea de investigación más desarrollada en la literatura propone soluciones que el propio usuario porta consigo. 

Leong y Kanesaraj Ramasamy (7) propusieron un sistema de detección de obstáculos y estimación de distancia para personas con discapacidad visual implementado en gafas inteligentes con Raspberry Pi, cámara y algoritmos de machine learning, que genera retroalimentación auditiva o háptica en tiempo real según la proximidad de los objetos detectados. Este sistema está diseñado para identificar objetos y estimar sus distancias, proporcionando retroalimentación auditiva o háptica en tiempo real al usuario. 

Ferreira et al. (8) diseñaron un sistema modular de gafas inteligentes para detección de obstáculos en navegación de personas invidentes, validando la viabilidad de integrar procesamiento de visión artificial en objetos cotidianos del usuario con alertas sonoras como salida principal.

Okolo et al. propusieron un sistema de navegación asistida inteligente que combina YOLOv8 implementado sobre Raspberry Pi con sensores ultrasónicos, cámara, altavoz y sensor de humedad, alcanzando una precisión promedio del 91.70% en la detección de nueve tipos de obstáculos en entornos interiores y exteriores, con tiempos de detección de apenas 0.001 segundos para personas y vehículos.Este resultado confirma que YOLO es un algoritmo maduro y eficiente para aplicaciones de detección en tiempo real orientadas a personas con discapacidad visual.

Sin embargo, todas estas propuestas comparten una limitación estructural: dependen de que el usuario adquiera, configure y porte un dispositivo adicional, lo que representa una barrera de acceso económico y tecnológico que excluye precisamente a quienes más necesitan la solución.

**Sistemas de detección en cruces peatonales para personas con discapacidad visual**

Una segunda línea de investigación se enfoca específicamente en el desafío del cruce de calles, que representa uno de los mayores riesgos para las personas invidentes en el espacio urbano. 

Chang et al. propusieron un sistema wearable basado en edge computing con inteligencia artificial que combina gafas inteligentes, un dispositivo de cintura y un bastón inteligente para asistir a personas con discapacidad visual en el uso seguro de cruces cebra, adoptando deep learning para el reconocimiento en tiempo real de la señalización peatonal y alcanzando una precisión del 90% en la detección del cruce cebra. Este trabajo evidencia que la combinación de bastón y gafas como objetos de referencia es un enfoque válido para identificar al usuario invidente en el contexto del cruce peatonal, lo que directamente sustenta la estrategia de detección de SafeWalk AI.

Ji H et al. (6) desarrollaron un dataset multi-escena y un detector de objetos específicamente diseñado para identificar a personas invidentes en espacios públicos exteriores, demostrando que los sistemas de videovigilancia existentes pueden adaptarse para reconocer a este grupo de usuarios mediante visión artificial. Su trabajo es especialmente relevante para SafeWalk AI porque establece la viabilidad técnica de detectar personas invidentes desde cámaras fijas instaladas en infraestructura pública, no desde dispositivos portados por el usuario.

Investigaciones de IEEE señalan que más de 250 millones de personas con discapacidad visual enfrentan el cruce de calles como uno de sus mayores desafíos de movilidad autónoma, y que la mayoría de semáforos peatonales en países en desarrollo no ofrecen ayudas sonoras, constituyendo un problema abierto con muy escasos estudios que lo aborden desde la infraestructura mediante redes neuronales profundas.

**Modelos de detección de objetos para personas con discapacidad visual**

Investigaciones recientes en IEEE Access han realizado evaluaciones comparativas entre YOLOv8, Faster R-CNN y DETR para sistemas de detección de obstáculos orientados a personas con discapacidad visual, encontrando que DETR logra una puntuación de confianza del 99%, precisión del 98% y velocidad de procesamiento de 40 ms por fotograma, mientras que YOLOv8 ofrece resultados competitivos con mayor eficiencia computacional, representando un balance adecuado entre precisión y velocidad para dispositivos de borde. Estos resultados son directamente aplicables a SafeWalk AI, donde la velocidad de inferencia en la Jetson Nano es un factor crítico.

**Sistema de navegación guiada desde la infraestructura**

La línea más cercana al enfoque de SafeWalk AI es la que propone colaborar con infraestructura existente en lugar de depender exclusivamente del dispositivo personal del usuario. Investigaciones recientes en IEEE Transactions on Intelligent Transportation Systems han presentado sistemas de navegación asistida que colaboran con infraestructura para mejorar la localización y orientación de personas con discapacidad visual en exteriores, usando cámaras RGB-D, sensores GPS y plataformas de procesamiento embebido como Jetson, logrando 50 fotogramas por segundo en dispositivos de bajo consumo.Este trabajo valida que la Jetson Nano es una plataforma adecuada para ejecutar modelos de visión artificial orientados a accesibilidad urbana en tiempo real.

**Brecha que justifica SafeWalk AI**

Del análisis del estado del arte se identifican claramente dos grupos de soluciones: las que asisten al usuario desde un dispositivo personal que él porta, y las que procesan información desde la infraestructura urbana. SafeWalk AI se ubica en el segundo grupo, que es el menos desarrollado. Su aporte diferencial es que, en lugar de ayudar al usuario a detectar el entorno, **detecta al usuario para alertar al entorno**. Al identificar simultáneamente el bastón blanco y las gafas oscuras mediante YOLO en una Jetson Nano instalada en el semáforo, el sistema emite una alerta sonora que beneficia tanto a la persona invidente como a los demás peatones y conductores presentes. Esta aproximación no requiere que el usuario porte ningún dispositivo adicional, eliminando la principal barrera de acceso identificada en todas las soluciones existentes.

## **Qué son los Objetivos de Desarrollo Sostenible**

Los Objetivos de Desarrollo Sostenible (ODS) son un conjunto de metas globales establecidas por la Organización de las Naciones Unidas como parte de la Agenda 2030 para el Desarrollo Sostenible, adoptada en el año 2015 por los Estados miembros (9). Estos objetivos buscan orientar los esfuerzos de los países hacia un desarrollo que permita mejorar la calidad de vida de las personas, reducir las desigualdades y proteger el planeta.

En total existen 17 objetivos, cada uno acompañado de metas específicas que abordan distintos problemas que afectan a la sociedad a nivel mundial, como la pobreza, el acceso a la salud, la educación, la innovación, el desarrollo de ciudades más seguras y la protección del medio ambiente. La idea principal de los ODS es promover un desarrollo que no solo considere el crecimiento económico, sino también el bienestar social y la sostenibilidad ambiental. Además, estos objetivos están interrelacionados, lo que significa que el avance en uno de ellos puede contribuir al progreso de otros. Por ello, su cumplimiento requiere la participación de distintos actores, como gobiernos, instituciones, empresas y la sociedad en general (9).

En el caso de nuestro proyecto, se pueden identificar tres ODS que se relacionan directamente con la propuesta planteada.

### **Objetivos de Desarrollo Sostenible relacionados con nuestro de proyecto**

**ODS 3: Salud y bienestar**

Una de las metas de este objetivo, específicamente la meta 3.6, establece la necesidad de reducir a la mitad el número de muertes y lesiones causadas por accidentes de tráfico en el mundo para el año 2030 (10). En el contexto urbano, esto implica desarrollar medidas que protejan a los grupos más expuestos a estos riesgos, entre ellos los peatones con discapacidad, cuya seguridad física al desplazarse por la vía pública está directamente vinculada con su bienestar y su capacidad de acceder a servicios de salud y rehabilitación.

En el Perú, esta problemática tiene una dimensión concreta. Entre enero y julio de 2022, los accidentes de tránsito ocasionaron 1,853 fallecidos y más de 30,000 personas lesionadas (3), cifras que evidencian el impacto que la inseguridad vial tiene sobre la salud pública. Para las personas con discapacidad visual, este riesgo se agrava debido a la ausencia de infraestructura accesible en los cruces peatonales. Como señalan Seminario-Hurtado y Alfaro Torres (5), las barreras físicas en el entorno urbano no solo limitan la movilidad de estas personas, sino que también restringen su acceso a servicios esenciales, afectando directamente su calidad de vida.

Nuestro proyecto se relaciona con este objetivo porque busca reducir el riesgo de accidentes en cruces peatonales para personas con discapacidad visual, contribuyendo así a preservar su integridad física y promover su bienestar. A través de un sistema que detecta objetos asociados a peatones invidentes —el bastón blanco y las gafas oscuras— mediante YOLO en una NVIDIA Jetson Nano instalada en semáforos, y emite una alerta sonora para avisar a los demás peatones presentes, se busca que estas personas puedan desplazarse con mayor seguridad y autonomía, lo cual representa una mejora directa en su salud y calidad de vida.

**ODS 9: Industria, innovación e infraestructura**

Una de las metas de este objetivo plantea la necesidad de modernizar la infraestructura existente e incorporar nuevas tecnologías que permitan hacerla más eficiente y segura (9). En el caso de las ciudades, esto se relaciona con el desarrollo de sistemas inteligentes que ayuden a mejorar la movilidad urbana y la seguridad vial.

Nuestro proyecto se vincula con este objetivo porque propone el uso de herramientas tecnológicas como cámaras, inteligencia artificial y algoritmos de detección de objetos en tiempo real para mejorar la seguridad de las personas invidentes en los cruces peatonales. La implementación de un sistema que detecte el bastón blanco y las gafas oscuras mediante YOLO en una NVIDIA Jetson Nano, y que emita una alerta sonora desde el semáforo, representa una forma concreta de innovación aplicada a la infraestructura urbana (6, 7, 8).

**ODS 10: Reducción de las desigualdades**

En muchos casos, las personas con discapacidad enfrentan dificultades para desplazarse en el entorno urbano debido a la falta de infraestructura accesible o a la ausencia de sistemas que les brinden apoyo en situaciones de riesgo. De acuerdo con datos del Instituto Nacional de Estadística e Informática, en el Perú más de tres millones de personas presentan algún tipo de discapacidad (10), lo que representa una parte importante de la población. Esto evidencia la necesidad de desarrollar soluciones que contribuyan a mejorar su acceso y movilidad en los espacios públicos.

Nuestro proyecto se relaciona con este objetivo porque busca contribuir a la reducción de estas barreras mediante el uso de tecnología. A través del desarrollo de un sistema que pueda detectar en tiempo real objetos asociados a personas invidentes en cruces peatonales y emitir alertas sonoras, se busca brindar una herramienta que facilite el desplazamiento de estas personas y mejore su seguridad al momento de cruzar la vía pública. En ese sentido, investigaciones recientes demuestran que la detección automática del bastón blanco mediante sistemas de visión artificial instalados en infraestructura pública constituye una solución viable y escalable para identificar a personas invidentes en espacios exteriores (6), lo que refuerza la urgencia de propuestas tecnológicas que cierren esta brecha.

**ODS 11: Ciudades y comunidades sostenibles**

Una de las metas de este objetivo está relacionada con mejorar la seguridad de los sistemas de transporte y garantizar que estos sean accesibles, especialmente para los grupos más vulnerables de la población, como niños, adultos mayores y personas con discapacidad (9).

En el Perú, los accidentes de tránsito continúan siendo un problema importante. Según información del Ministerio de Transportes y Comunicaciones del Perú, entre enero y julio del año 2022 se registraron más de 47,000 siniestros de tránsito en el país, lo que ocasionó miles de personas fallecidas y lesionadas (3). Dentro de estas cifras, los peatones se encuentran entre los grupos más afectados.

El proyecto propuesto se relaciona con este objetivo porque busca aportar a la construcción de ciudades más seguras mediante el uso de tecnología. Al desarrollar un sistema que permita detectar en tiempo real a personas con discapacidad visual a través de sus objetos distintivos —el bastón blanco y las gafas oscuras— y emitir una alerta sonora en el semáforo, se busca contribuir a mejorar la seguridad vial y la accesibilidad en los espacios urbanos, con especial énfasis en los cruces peatonales.

**Viabilidad de implementación: marco institucional y camino hacia la integración en semáforos**

**Gestión de semáforos en Lima: autoridades responsables**

Para que el sistema SafeWalk AI pueda ser instalado en los semáforos de Lima, es indispensable identificar qué entidades tienen competencia sobre la infraestructura semáforica. En Lima Metropolitana, la gestión de los semáforos recae principalmente en PROTRÁNSITO, el Proyecto Especial para la Gestión de Tránsito de la Municipalidad Metropolitana de Lima, creado en 2016 y adscrito a la Gerencia Municipal. Esta entidad administra y planifica integralmente la red semáforica centralizada de la capital a través del Centro de Control y Gestión de Tránsito (CCGT), desde donde se monitorea, programa y sincroniza en tiempo real más de 800 intersecciones semáforicas interconectadas mediante fibra óptica (10).

Sin embargo, la gestión semáforica en Lima no es centralizada en una sola entidad. Existen competencias distribuidas entre la Municipalidad Metropolitana de Lima a través de PROTRÁNSITO y la Gerencia de Transporte Urbano (GTU), los municipios distritales, y PROTRANSPORTE, que opera los semáforos asociados al sistema del Metropolitano. Según ITS Perú  (Inspection & Testing Services), el ritmo de los semáforos en Lima está determinado por las autoridades municipales en coordinación con ingenieros de tráfico, quienes utilizan análisis de datos y tecnología para optimizar la circulación vehicular, aunque este proceso ha estado afectado históricamente por la selección de personal por criterios políticos antes que técnicos (11). En ciudades distintas a Lima, la competencia recae en las municipalidades provinciales, que son las entidades responsables de la infraestructura vial y semáforica dentro de su jurisdicción, de acuerdo con la Ley Orgánica de Municipalidades.

### **Ruta de implementación del sistema**

Dado que SafeWalk AI propone integrar una cámara y un altavoz en la infraestructura de los semáforos existentes, la ruta de implementación requiere necesariamente pasar por las entidades competentes. En el caso de Lima Metropolitana, la entidad a la que se debería presentar la propuesta es PROTRÁNSITO, que cuenta con el CCGT como plataforma centralizada capaz de integrar nuevos dispositivos a la red semáforica. Es importante destacar que la propia Municipalidad de Lima ha contemplado en proyectos anteriores la instalación de elementos de accesibilidad en los semáforos, como placas con sistema braille y repetidores acústicos para personas invidentes, lo que indica que existe un precedente institucional favorable para este tipo de propuestas (10).

Para avanzar hacia la implementación real del sistema, se pueden identificar los siguientes pasos. En primer lugar, desarrollar y validar un prototipo funcional con NVIDIA Jetson Nano, cámara y modelo YOLO entrenado para detectar el bastón blanco y las gafas oscuras en condiciones urbanas reales. En segundo lugar, documentar los resultados del prototipo en un informe técnico que demuestre la precisión de detección y la latencia del sistema. En tercer lugar, presentar la propuesta formalmente ante PROTRÁNSITO en Lima, o ante la municipalidad provincial correspondiente en otras ciudades, adjuntando el informe técnico y una evaluación del impacto social para personas con discapacidad visual. En cuarto lugar, coordinar con la entidad competente una prueba piloto en dos o tres intersecciones peatonales de alta concurrencia con población invidente, para evaluar la respuesta del sistema en condiciones reales y recoger retroalimentación de los usuarios. Finalmente, en función de los resultados del piloto, escalar la implementación a más intersecciones en coordinación con la red semáforica centralizada.

En el caso de provincias fuera de Lima, la interlocución institucional es más directa, dado que no existe una entidad especializada equivalente a PROTRÁNSITO. En esos casos, la propuesta debería ser presentada directamente ante la Subgerencia de Transporte o Gestión Vial de la municipalidad provincial correspondiente, que es la entidad técnicamente competente para autorizar cualquier modificación o adición a la infraestructura semáforica dentro de su jurisdicción. Esta descentralización de la gestión semáforica en provincias representa, paradojalmente, una ventaja para un proyecto piloto, ya que los procesos de aprobación suelen ser más ágiles y la escala de las redes semáforicas es menor y más manejable para una primera implementación real.

## **Referencias Bibliográficas**

1. Huamaní Meza A, et al. Seguridad vial y peatones en Lima Metropolitana \[Internet\]. Lima: Editorial Innova; 2023 \[citado 2025\]. Disponible en: [https://www.editorialinnova.com/index.php/nrj/article/view/323](https://www.editorialinnova.com/index.php/nrj/article/view/323)

2. Rodríguez Porcel M, Lee S, Sandoval D, Tascón Valencia J, Jaramillo PJ, Pedraza L. Auditoría georreferenciada y diagnóstico de accesibilidad peatonal de personas con discapacidad en la primera y última milla de un viaje \[Internet\]. Washington D.C.: Banco Interamericano de Desarrollo; 2023 \[citado 2025\]. Disponible en: [https://publications.iadb.org/es/auditoria-georreferenciada-y-diagnostico-de-accesibilidad-peatonal-de-personas-con-discapacidad-en](https://publications.iadb.org/es/auditoria-georreferenciada-y-diagnostico-de-accesibilidad-peatonal-de-personas-con-discapacidad-en)

3. Ministerio de Transportes y Comunicaciones del Perú. De enero a julio del 2022 ocurrieron más de 47 mil siniestros de tránsito en el Perú \[Internet\]. Lima: MTC; 2022 \[citado 2025\]. Disponible en: [https://www.gob.pe/institucion/mtc/noticias/647689-de-enero-a-julio-del-2022-ocurrieron-mas-de-47-mil-siniestros-de-transito-en-el-peru/](https://www.gob.pe/institucion/mtc/noticias/647689-de-enero-a-julio-del-2022-ocurrieron-mas-de-47-mil-siniestros-de-transito-en-el-peru/)

4. Instituto Nacional de Estadística e Informática. Perfiles sociodemográficos de la población con discapacidad \[Internet\]. Lima: INEI; 2019 \[citado 2025\]. Disponible en: [https://www.inei.gob.pe/media/MenuRecursivo/publicaciones\_digitales/Est/Lib1675/libro.pdf](https://www.inei.gob.pe/media/MenuRecursivo/publicaciones_digitales/Est/Lib1675/libro.pdf)

5. Seminario-Hurtado N, Alfaro Torres HM. Accesibilidad en entornos urbanos para personas con discapacidad visual en el Perú: un análisis normativo. Cuadernos de Vivienda y Urbanismo \[Internet\]. 2025 \[citado 2025\]; 18\. Disponible en: [https://revistas.javeriana.edu.co/index.php/cvyu/article/view/41190/](https://revistas.javeriana.edu.co/index.php/cvyu/article/view/41190/)

6. Ji H, Mendonça I, Aritsugi M. Multi-Scene Dataset and Object Detector for Outside Blind Individual Identification. IEEE Access \[Internet\]. 2026 \[citado 2026\]; 14: 1423-1438. Disponible en: [https://ieeexplore.ieee.org/document/11317963](https://ieeexplore.ieee.org/document/11317963)      

7. Leong X, Kanesaraj Ramasamy R. Obstacle Detection and Distance Estimation for Visually Impaired People. IEEE Access \[Internet\]. 2023 \[citado 2025\]; 11: 136609-136629. Disponible en: [https://ieeexplore.ieee.org/document/10336791](https://ieeexplore.ieee.org/document/10336791)

8. Ferreira AA, Barros CAL, Pereira TEB, Santana MFA, Silva IDS, Oliveira FS. Modular Smart Glasses for Real-Time Obstacle Detection in Blind Navigation. IEEE \[Internet\]. 2025 \[citado 2025\]. Disponible en: [https://ieeexplore.ieee.org/document/11334173](https://ieeexplore.ieee.org/document/11334173)

9. Organización de las Naciones Unidas. Objetivos de Desarrollo Sostenible \[Internet\]. Nueva York: ONU; 2015 \[citado 2025\]. Disponible en: [https://www.un.org/sustainabledevelopment/es/sustainable-development-goals/](https://www.un.org/sustainabledevelopment/es/sustainable-development-goals/)

10. PROTRÁNSITO – Municipalidad Metropolitana de Lima. Centro de Control y Gestión de Tránsito (CCGT) \[Internet\]. Lima: PROTRÁNSITO; s.f. \[citado 2025\]. Disponible en: [http://protransito.munlima.gob.pe/index.php/es-es/monitoreo/ccgt](http://protransito.munlima.gob.pe/index.php/es-es/monitoreo/ccgt) 

11. ITS Perú. ¿Quién o qué decide el ritmo de los semáforos en Lima? \[Internet\]. Lima: ITS Perú; 2024 \[citado 2025\]. Disponible en: [https://itsperu.org/articulos/quien-o-que-decide-el-ritmo-de-los-semaforos-en-lima/](https://itsperu.org/articulos/quien-o-que-decide-el-ritmo-de-los-semaforos-en-lima/) 

12. Ji H, Mendonça I, Aritsugi M. Multi-Scene Dataset and Object Detector for Outside Blind Individual Identification. IEEE Access \[Internet\]. 2026 \[citado 2026 abr 10\]; 14: 1423-1438. Disponible en: [https://ieeexplore.ieee.org/document/11317963](https://ieeexplore.ieee.org/document/11317963)

13.  Okolo GI, Althobaiti T, Ramzan N. Smart Assistive Navigation System for Visually Impaired People. Journal of Disability Research \[Internet\]. 2025 \[citado 2026 abr 10\]; 4(1). Disponible en: [https://www.scienceopen.com/hosted-document?doi=10.57197/JDR-2024-0086](https://www.scienceopen.com/hosted-document?doi=10.57197/JDR-2024-0086)

14.  Ghilardi MC, et al. Real-Time Detection of Pedestrian Traffic Lights for Visually-Impaired People. IEEE \[Internet\]. 2018 \[citado 2026 abr 10\]. Disponible en: [https://ieeexplore.ieee.org/document/8489516](https://ieeexplore.ieee.org/document/8489516)

15. Chang WJ, Chen LB, Sie CY, Yang CH. An Artificial Intelligence Edge Computing-Based Assistive System for Visually Impaired Pedestrian Safety at Zebra Crossings. IEEE Transactions on Consumer Electronics \[Internet\]. 2021 \[citado 2026 abr 10\]; 67: 3-11. Disponible en: [https://ieeexplore.ieee.org/document/9253595](https://ieeexplore.ieee.org/document/9253595) 

16.  Calandri IL, et al. Embedded Real-Time Vehicle and Pedestrian Detection Using a Compressed Tiny YOLO v3 Architecture. IEEE Transactions on Intelligent Transportation Systems \[Internet\]. 2024 \[citado 2026 abr 10\]. Disponible en: [https://ieeexplore.ieee.org/document/10664928](https://ieeexplore.ieee.org/document/10664928)

17. Li X, et al. Enhancing Object Detection in Assistive Technology for the Visually Impaired: A DETR-Based Approach. IEEE Access \[Internet\]. 2025 \[citado 2026 abr 10\]. Disponible en: [https://ieeexplore.ieee.org/document/10950139](https://ieeexplore.ieee.org/document/10950139)

18. Zhao J, et al. Infrastructure Enabled Guided Navigation for Visually Impaired. IEEE Transactions on Intelligent Transportation Systems \[Internet\]. 2025 \[citado 2026 abr 10\]. Disponible en: [https://ieeexplore.ieee.org/document/10899381](https://ieeexplore.ieee.org/document/10899381) 

Presentacion de las Patentes: [https://canva.link/v273706ij0yled3](https://canva.link/v273706ij0yled3) 

[image1]: <>

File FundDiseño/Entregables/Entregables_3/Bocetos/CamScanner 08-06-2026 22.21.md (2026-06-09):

| : 

**==> picture [732 x 318] intentionally omitted <==**

**----- Start of picture text -----**<br>
; “ Ordo<br>| ! } S oe<br>io er de player iis vas A O \woun<br>L ae —=- Uy S\ AR \<br>' iN oO S=<br>See | Sensor de Al GP)<br>| . hislancé< ie ne<br>a sane (vi.551.4%) ,<br>genset Of PEgErcO<br>ae AlIavoz<br>|<br>(2024100)<br>**----- End of picture text -----**<br>

| 

**==> picture [2 x 13] intentionally omitted <==**

**----- Start of picture text -----**<br>
|<br>**----- End of picture text -----**<br>

Escaneado con CamScanner

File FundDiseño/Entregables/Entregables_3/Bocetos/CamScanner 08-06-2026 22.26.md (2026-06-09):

**==> picture [797 x 358] intentionally omitted <==**

**----- Start of picture text -----**<br>
Amplificador de audio<br>( PAM8403) Vista lateral derecho Vista ssométrica<br>KO A<br>é<br>PT = de exe<br>i  ; df. player —_ N camaro (0v3660)<br>|<br>ai f= _ — . Oo. SE\ \. xiao seed<br>| | Sel a ‘iil — Y)Yj yeoN KY\\ |<br>i | ~ \G.<br>| yf ere |<br>ry “ distancia = ey<br>PEN MSS)<br>**----- End of picture text -----**<br>

snrum ae presencia (LD2410C) 

Altavos 

Escaneado con CamScanner

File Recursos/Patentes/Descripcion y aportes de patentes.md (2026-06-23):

#  Patentes Relacionadas

##  Descripción general
Esta sección reúne patentes relacionadas con sistemas de asistencia para personas con discapacidad visual, incluyendo dispositivos ópticos, hápticos y sistemas de detección de peatones mediante visión por computadora. Estas tecnologías sirven como base para el desarrollo de soluciones de movilidad segura y accesible.

---

## 1. Módulo óptico para semáforos peatonales con indicación acústica
**Descripción:** Dispositivo diseñado para semáforos peatonales que incorpora señales acústicas para asistir a personas con discapacidad visual durante el cruce de calles.  
**Aporte:** Mejora la accesibilidad urbana al integrar señales auditivas que complementan la información visual del semáforo, facilitando la orientación segura de peatones con discapacidad visual.

🔗 https://worldwide.espacenet.com/patent/search/family/043447627/publication/ES1073627U

---

## 2. Sistema y método para la detección de peatones mediante procesamiento de imágenes
**Descripción:** Sistema basado en visión por computadora que detecta peatones en entornos urbanos mediante procesamiento de imágenes.  
**Aporte:** Proporciona una base tecnológica para sistemas inteligentes de asistencia y seguridad vial, permitiendo identificar peatones en tiempo real para evitar accidentes.

🔗 https://worldwide.espacenet.com/patent/search/family/078706485/publication/US2021369545A1

---

## 3. Dispositivo háptico vibratorio para personas con discapacidad visual
**Descripción:** Dispositivo portátil que utiliza vibraciones hápticas para comunicar información al usuario con discapacidad visual.  
**Aporte:** Ofrece una alternativa sensorial no visual para la comunicación de información espacial o de alerta, mejorando la autonomía del usuario en entornos desconocidos.

🔗 https://patents.google.com/patent/US10719707B2/en

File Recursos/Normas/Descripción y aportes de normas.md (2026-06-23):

#  Normas e Informes Institucionales

##  Descripción general
Esta sección incluye normas técnicas, informes oficiales y documentos institucionales relacionados con discapacidad, infraestructura y seguridad.

---

## 1. Seguridad y salud en la construcción - OIT
**Descripción:** Documento sobre estándares de seguridad en construcción.  
**Aporte:** Establece lineamientos aplicables a entornos urbanos seguros y accesibles.

---

## 2. Perfil sociodemográfico de personas con discapacidad - INEI
**Descripción:** Estadísticas sobre población con discapacidad en el Perú.  
**Aporte:** Permite sustentar la problemática con datos reales del país.

---

## 3. Informe de obras públicas paralizadas - Contraloría General de la República del Perú
**Descripción:** Reporte sobre obras públicas paralizadas en el Perú a diciembre de 2025.  
**Aporte:** Permite analizar el estado de la infraestructura pública y su impacto en la accesibilidad urbana.

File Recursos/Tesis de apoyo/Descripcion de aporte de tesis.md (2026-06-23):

#  Tesis de Apoyo

##  Descripción general
Reúne tesis relacionadas con visión por computadora y sistemas de asistencia para personas con discapacidad visual.

---

## 1. Sistema de asistencia basado en visión por computadora
**Descripción:** Desarrollo de un sistema de apoyo visual para personas con discapacidad visual.  
**Aporte:** Referencia directa para diseño de sistemas de asistencia tecnológica.

---

## 2. Aplicaciones de visión artificial para ayuda visual
**Descripción:** Estudia aplicaciones de visión artificial para personas con dificultades visuales.  
**Aporte:** Base teórica y comparativa de soluciones existentes.

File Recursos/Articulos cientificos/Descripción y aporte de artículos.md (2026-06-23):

#  Revisión Bibliográfica

##  Descripción general
Esta sección recopila fuentes académicas, institucionales y técnicas relacionadas con la accesibilidad urbana, discapacidad visual, visión por computadora y seguridad peatonal. Las referencias incluyen artículos científicos, tesis de investigación y reportes de organismos oficiales.

---

##  Artículos científicos

### 1. Accesibilidad urbana y discapacidad visual en Perú
**Descripción:** Analiza la accesibilidad en entornos urbanos para personas con discapacidad visual desde un enfoque normativo.  
**Aporte:** Proporciona bases legales y urbanísticas para comprender las limitaciones de accesibilidad en ciudades peruanas.

---

### 2. Auditoría georreferenciada de accesibilidad peatonal
**Descripción:** Estudia la accesibilidad en la primera y última milla de desplazamiento para personas con discapacidad.  
**Aporte:** Aporta metodologías de análisis espacial que pueden aplicarse a sistemas inteligentes de movilidad.

---

### 3. Detección de peatones mediante IoT y deep learning
**Descripción:** Propone un modelo ligero de detección de peatones en dispositivos edge.  
**Aporte:** Sirve como base tecnológica para sistemas de asistencia en tiempo real para personas con discapacidad visual.

---

### 4. Detección de obstáculos y estimación de distancia
**Descripción:** Desarrolla un sistema para ayudar a personas con discapacidad visual mediante visión por computadora.  
**Aporte:** Aporta algoritmos de detección de objetos útiles para sistemas de asistencia inteligente.

---

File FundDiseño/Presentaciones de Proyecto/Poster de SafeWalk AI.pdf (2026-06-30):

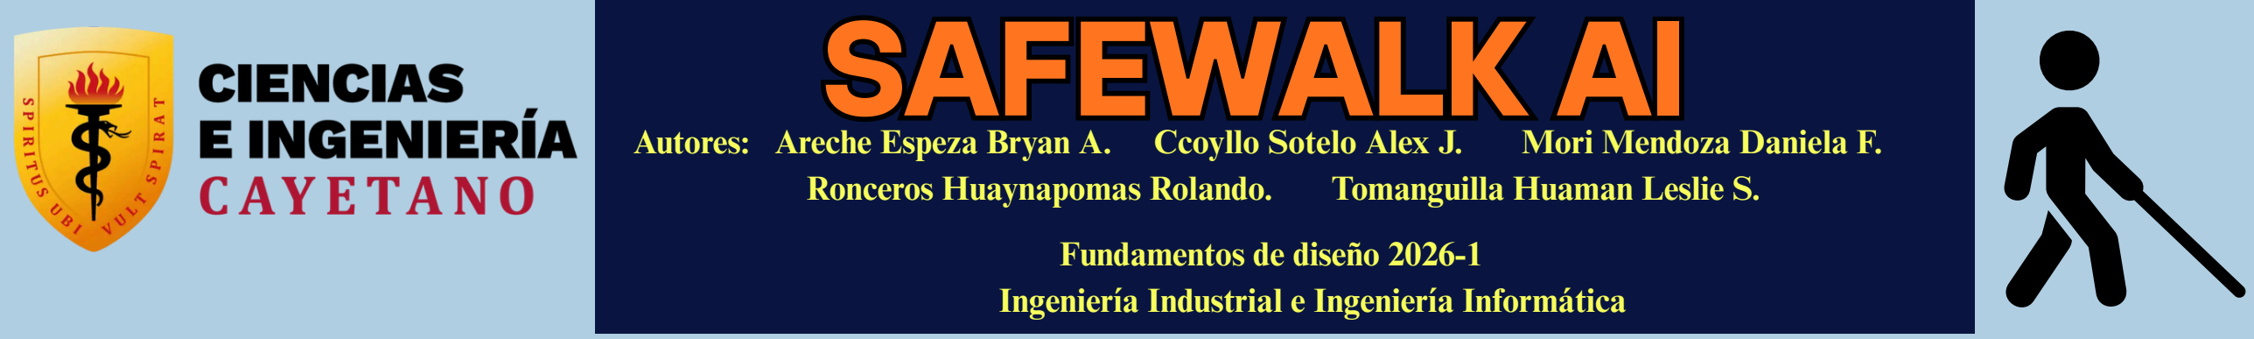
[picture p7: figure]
Autores: Areche Espeza Bryan A.; Ccoyllo Sotelo Alex J.; Mori Mendoza Daniela F.; Ronceros Huaynapomas Rolando.; Tomanguilla Huaman Leslie S.; Fundamentos de diseño 2026-1 Ingeniería Industrial e Ingeniería Informática; SSAAFFEEWWAALLKK AAII

En el 2025, se reportaron 2,416 obras públicas paralizadas en el Perú por la Contraloría General de la República, las cuales bloquean veredas e infraestructura peatonal sin contar con alertas accesibles. Esta condición altera críticamente las rutas espaciales memorizadas de las personas con discapacidad visual.

Figura 1: Obras de construcción que obstruyen la movilidad peatona. Fuente: Elaboración propia (2025)

# 💡Propuesta de innovación:

SafeWalk AI destaca por realizar un procesamiento bifásico local mediante inteligencia artificial de borde sin depender de internet ni de servidores externos, así mismo por su sistema embebido e independiente protegido por una carcasa rígida protectora compacta impresa en 3D (dimensiones: 19 cm alto x 18.5 cm ancho x 8 cm profundidad) apta para el polvo y la intemperie de la obra. Componentes Clave y Conectividad:

Figura 2: Prototipo de SafeWalk. Fuente: Elaboración propia del grupo (2025)

El proyecto tiene un enfoque tecnológico-experimental e implementa y valida un sistema embebido autónomo para la asistencia vial y accesibilidad urbana para personas con discapacidades visuales.
Fase 1: Recopilación y etiquetado en Roboflow de 400 imágenes exteriores mediante 2 pruebas de procesamiento, distribuidas en dos clases:
persona

_

baston y no
_persona

_

baston
Fase 2: Entrenamiento y optimización de una red neuronal de visión artificial ligera en la plataforma Roboflow para su ejecución local e independiente dentro de la placa compacta XIAO ESP32S3.
Fase 3: Pruebas de campo simuladas para evaluar tres variables: precisión diurna (≥80%), latencia de procesamiento (≤500 ms por fotograma) y nivel de presión sonora de la alerta (≥ 95 dB a 1m)

Figura 3: Imagenes de nuestro procesamiento Fuente: Elaboración propia (2025)

## ✅Conclusiones, recomendaciones y lecciones aprendidas:

CONCLUSIONES Y RESULTADOS:
Prototipo SafeWalk AI: Sistema de procesamiento autónomo (sin internet) con 80.00% de precisión, latencia de 500 ms y alerta acústica de 95 dB a 1m.
LECCIÓN APRENDIDA:
El sensor de presencia como interruptor redujo drásticamente el consumo de batería en reposo.
TRABAJOS FUTUROS:
Clasificación de patrones para gafas oscuras y ampliación de base de datos para técnicas de marcha complementarias.

# 📚Referencias:

1.Contraloría General de la República. Informe de obras públicas paralizadas en el territorio nacional a diciembre 2025. Lima: Contraloría General de la República; 2025. 2.Biblioteca Pública del Estado de Jalisco. Técnicas para el uso del bastón [Internet]. Jalisco: Biblioteca Pública del Estado de Jalisco; 2021 [citado 2026 Jun 21]. Disponible en: https://bpej.udg.mx/tecnicas-para-el-uso-del-baston
3.Presidencia del Consejo de Ministros. Decreto Supremo N.
° 085-2003-PCM: Reglamento de Estándares Nacionales de Calidad Ambiental del Ruido. Lima: El Peruano; 2003.

Eficiencia de la IA:
El modelo procesó fotogramas en tiempo real con una latencia máxima controlada de 500 ms y una precisión diurna del 80%. El filtro cinemático bifásico descartó exitosamente elementos distractores (muletas, paraguas) Alerta Sonora:
Las obras activas registran un ruido de fondo promedio de entre 85 dB, por ello SafeWalk AI emite una alerta de 95 dB a 1 metro de distancia, asegurando el umbral requerido de +10 dB para el peatón. Esto garantiza que el peatón reciba el aviso de peligro con total claridad sin violar los límites máximos permitidos para el horario diurno por el D.S. N° 085-2003-PCM.

# 📊Resultados :

OBJETIVO GENERAL:
Desarrollar un sistema embebido de detección automática que identifique en tiempo real la presencia de personas con discapacidad visual en zonas de construcción urbana, mediante visión artificial, y active una alerta sonora para advertir el riesgo.
OBJETIVOS ESPECÍFICOS:
Rango de detección: Cobertura en tiempo real para peatones entre los 2 y 8 metros de distancia.
Autonomía de hardware: Inferencia local continua en el dispositivo, sin internet ni servidores externos.
Precisión de la inferencia: Tasa de acierto mínimo del 80% en el reconocimiento de la técnica de Hoover.
Latencia de procesamiento: Tiempo de respuesta del sistema ≤500 ms por fotograma capturado.
Presión sonora focalizada: Potencia acústica de salida mínima de 95 dB a 1 metro de distancia.

# 🎯OBJETIVOS:

# ⚙️Metodología de investigación:

# 📍INTRODUCCIóN:

Figura 5. Comparación del nivel de presión sonora. Fuente: Elaboración propia IA (2025)

Figura 4. Filtro Cinematico. Fuente: Elaboración propia IA (2025)

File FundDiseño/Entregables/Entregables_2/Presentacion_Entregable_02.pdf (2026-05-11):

# PROYECTO DE FUNDAMENTOS DE DISEÑO ‘‘SAFEWALK AI’’

### SISTEMA DE ALERTA PARA CAMBIOS TEMPORALES EN EL ENTORNO URBANO

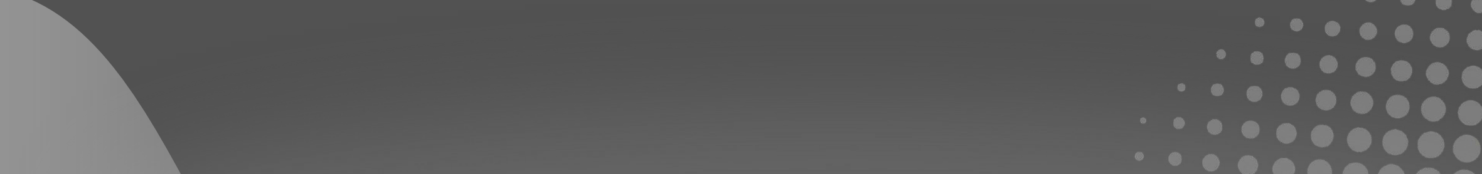
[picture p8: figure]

# INTEGRANTES:

Ronceros,
Rolando

Mori,Daniela

Tomanguilla,
Leslie

Ccoyllo,A
lex

Areche, Angello

# DATOS ESTADÍSTICOS

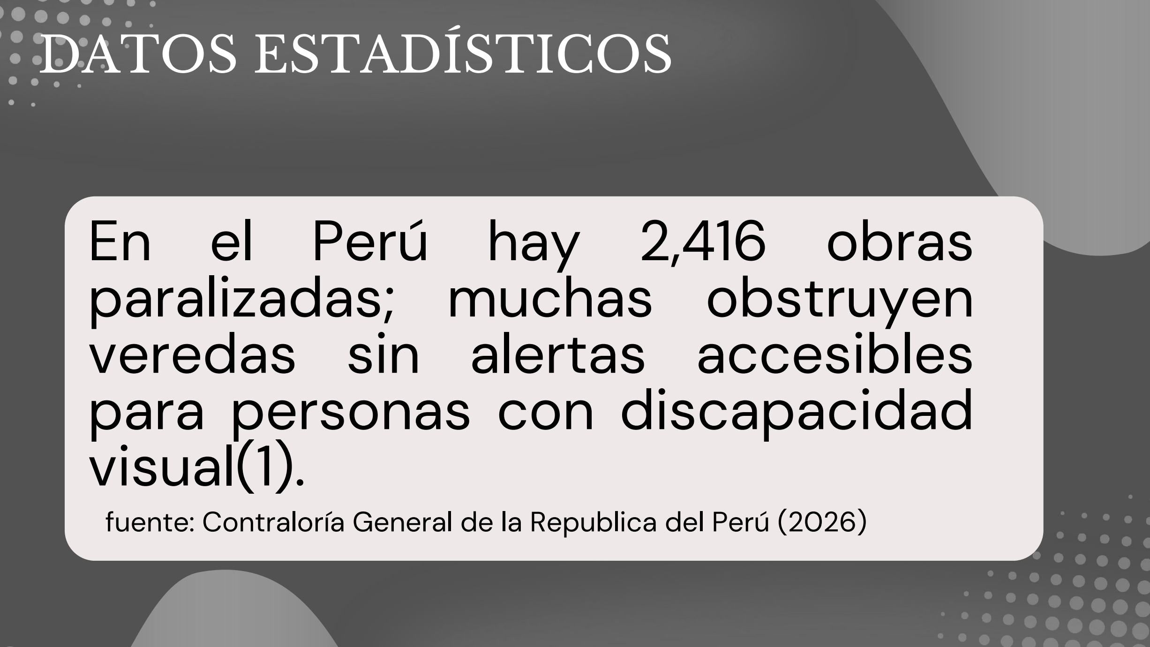
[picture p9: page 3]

# En el Perú hay 2,416 obras paralizadas; muchas obstruyen veredas sin alertas accesibles para personas con discapacidad

visual(1).

fuente: Contraloría General de la Republica del Perú (2026)

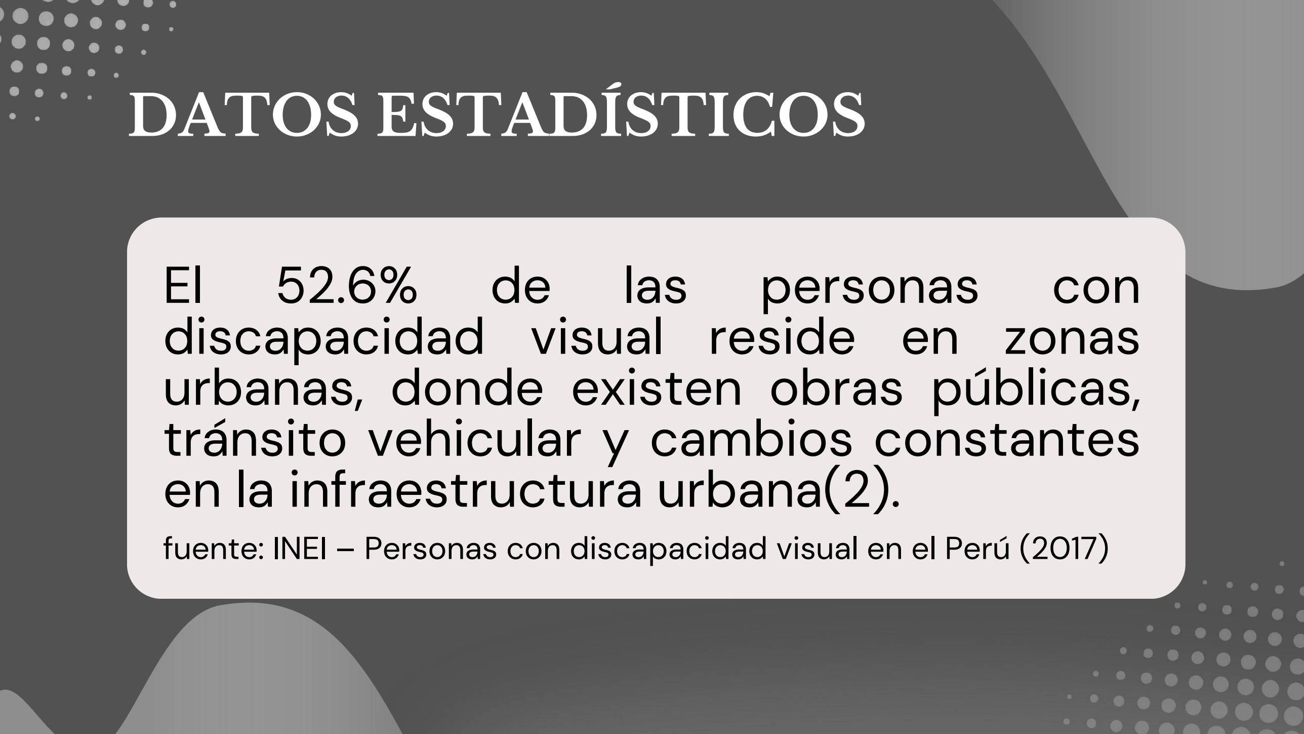
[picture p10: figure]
DATOS ESTADÍSTICOS; El 52.6% de las personas con discapacidad visual reside en zonas urbanas, donde existen obras públicas, tránsito vehicular y cambios constantes en la infraestructura urbana(2).

fuente: INEI – Personas con discapacidad visual en el Perú (2017)

# OBJETIVOS DEL PROYECTO:

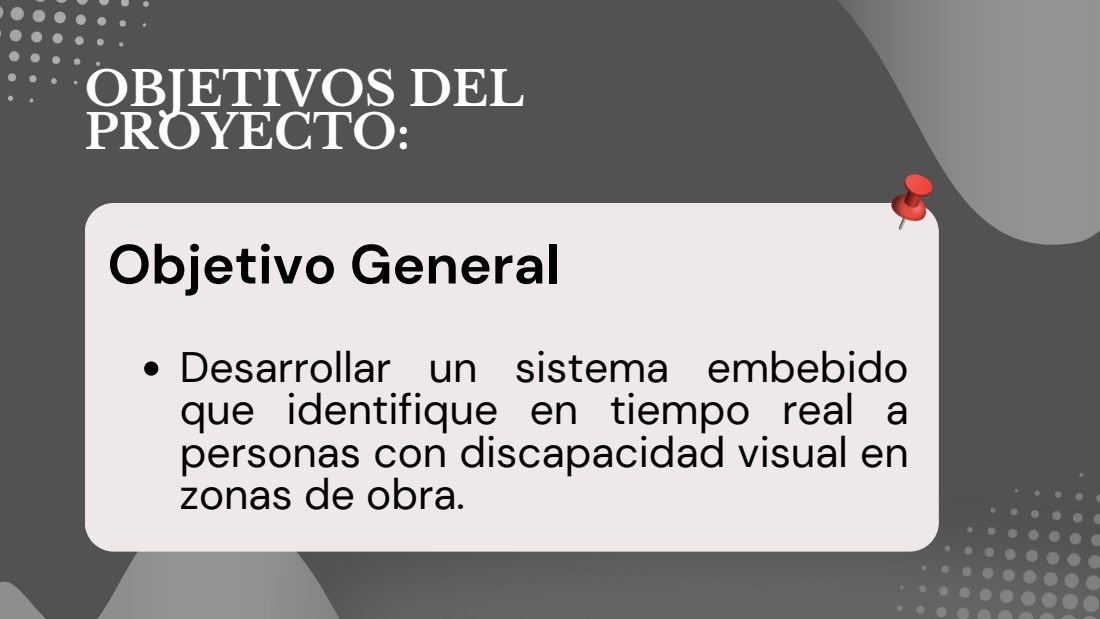
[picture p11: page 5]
Objetivo General

Desarrollar un sistema embebido
que identifique en tiempo real a
personas con discapacidad visual en
zonas de obra.

# ESTADO DE LA TECNOLOGÍA:

OrCam MyEye: Visión Artificial Portable

Tecnología existente en el ámbito comercial

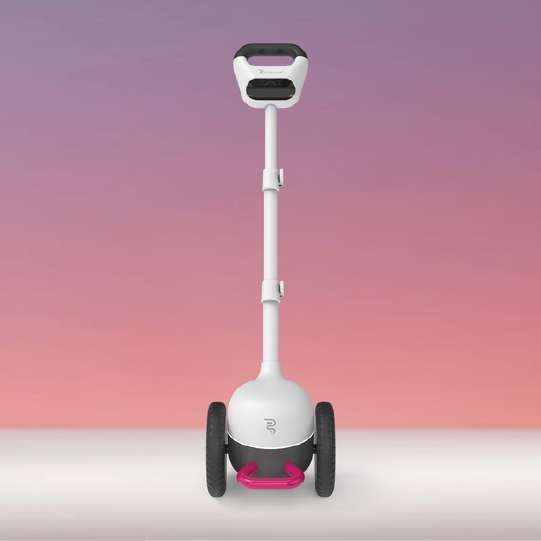
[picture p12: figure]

Glidance Glide | WeWALK: El Bastón Blanco Inteligente

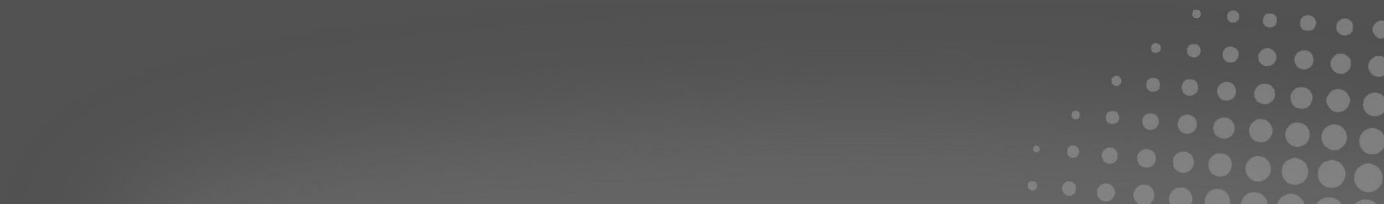
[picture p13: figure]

# PATENTES

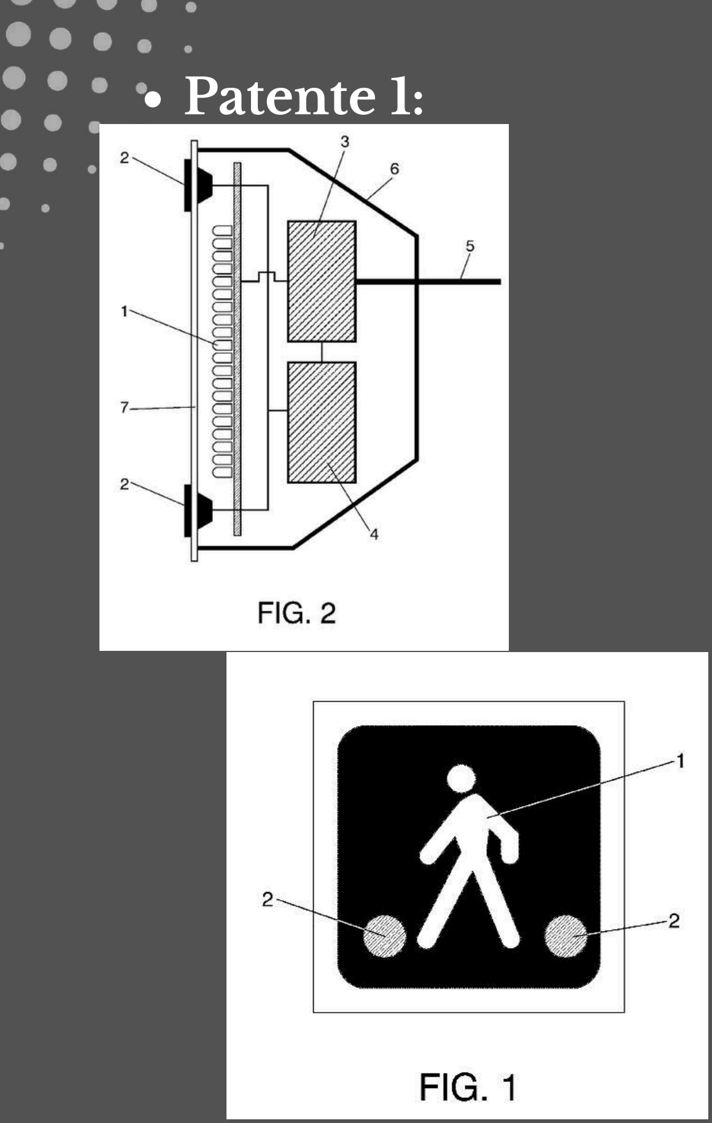
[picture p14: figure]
Patente 1:
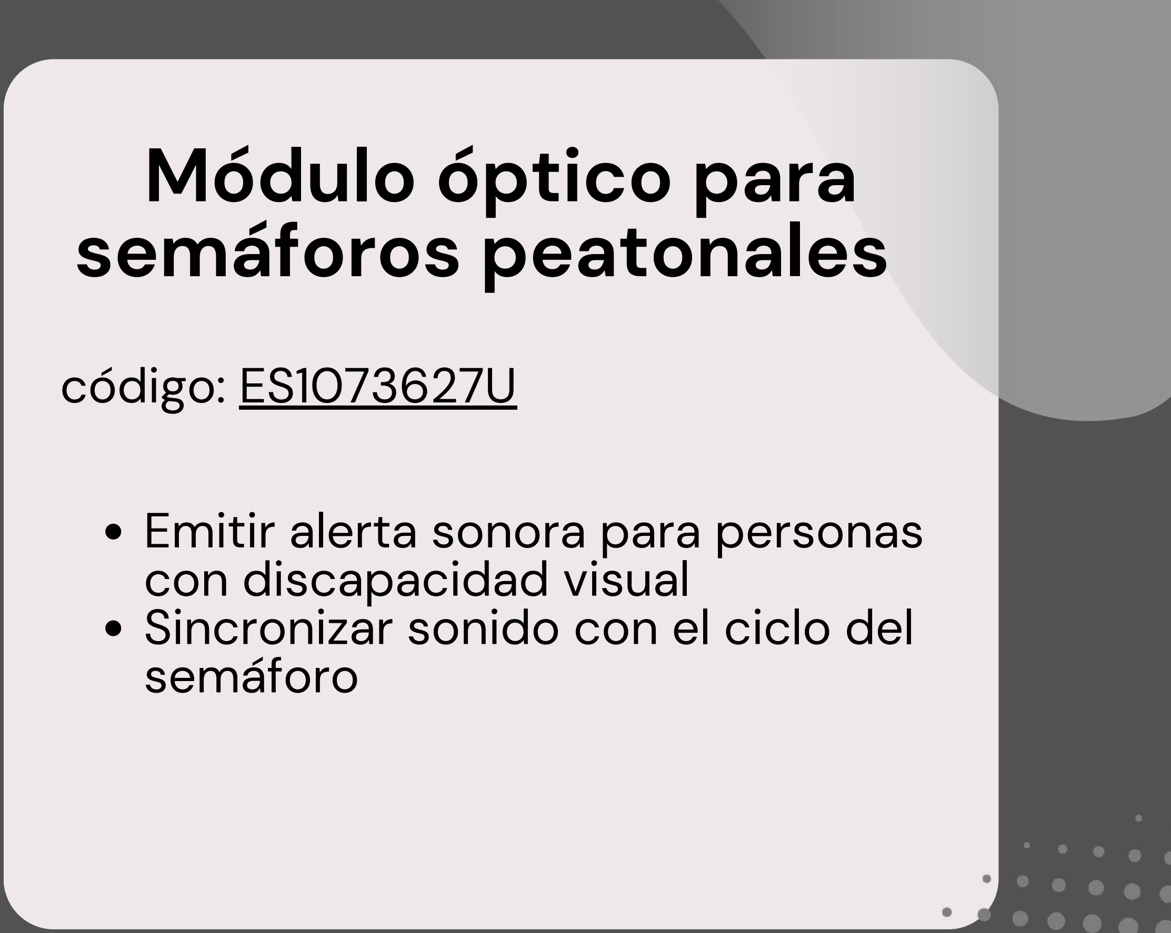
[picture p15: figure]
Módulo óptico para semáforos peatonales; código: ES1073627U; Emitir alerta sonora para personas con discapacidad visual Sincronizar sonido con el ciclo del semáforo

Urs Bal. A, Bravo Rendo JC. Optical module for pedestrian traffic lights with acoustic indication for visually impaired people. ES1073627U, 2011.

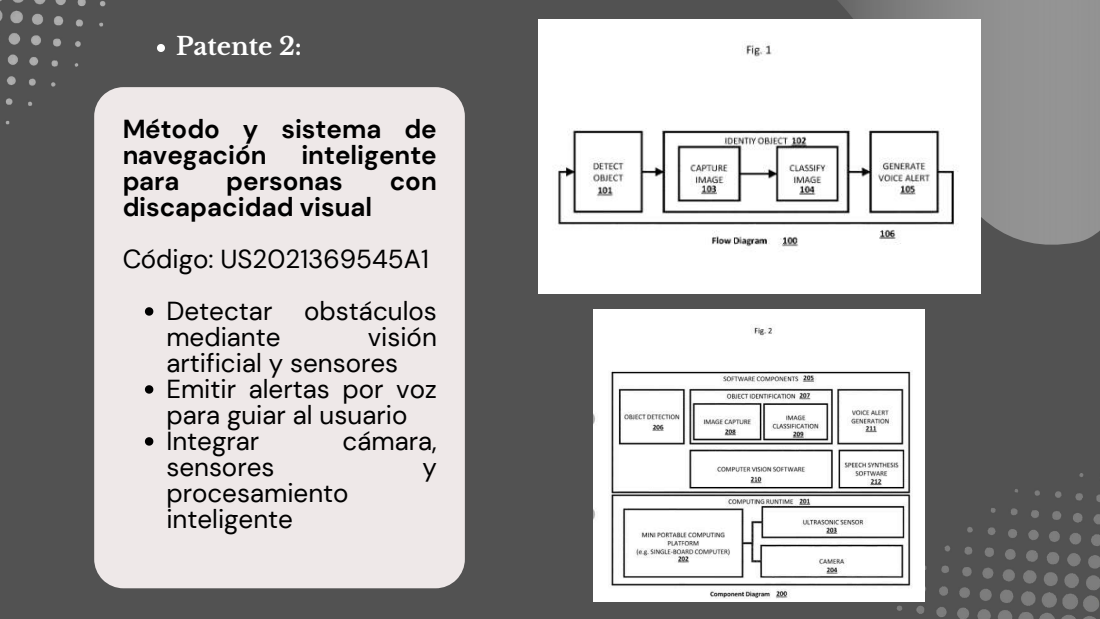
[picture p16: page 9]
Patente 2:; para; personas; con; mediante; visión; Integrar; cámara,; sensores

Método y sistema de
navegación inteligente
discapacidad visual
Código: US2021369545A1
Detectar obstáculos
artificial y sensores
Emitir alertas por voz
para guiar al usuario
procesamiento
inteligente

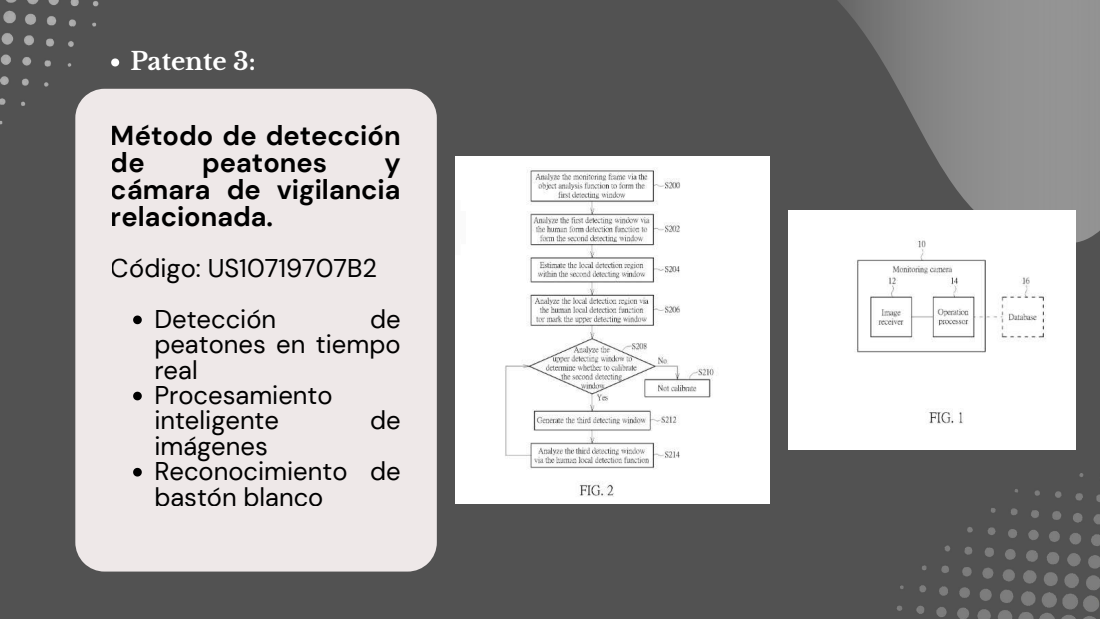
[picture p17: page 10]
peatones; Detección; inteligente; Patente 3:

Método de detección
cámara de vigilancia
relacionada.
Código: US10719707B2
peatones en tiempo
real
Procesamiento
imágenes
Reconocimiento de
bastón blanco

# ARTÍCULOS

# Articulo 1:

Multi-Scene Dataset and Object Detector for Outside Blind Individual Identification

Aporte principal:
Propone un sistema basado en YOLO para detectar personas con discapacidad visual en exteriores, mejorando la precisión incluso en ambientes oscuros y con obstáculos. Limitación
El sistema aún presenta dificultades en escenarios extremos, como oscuridad total, objetos muy pequeños o cuando el bastón está demasiado oculto (>70% de oclusión).

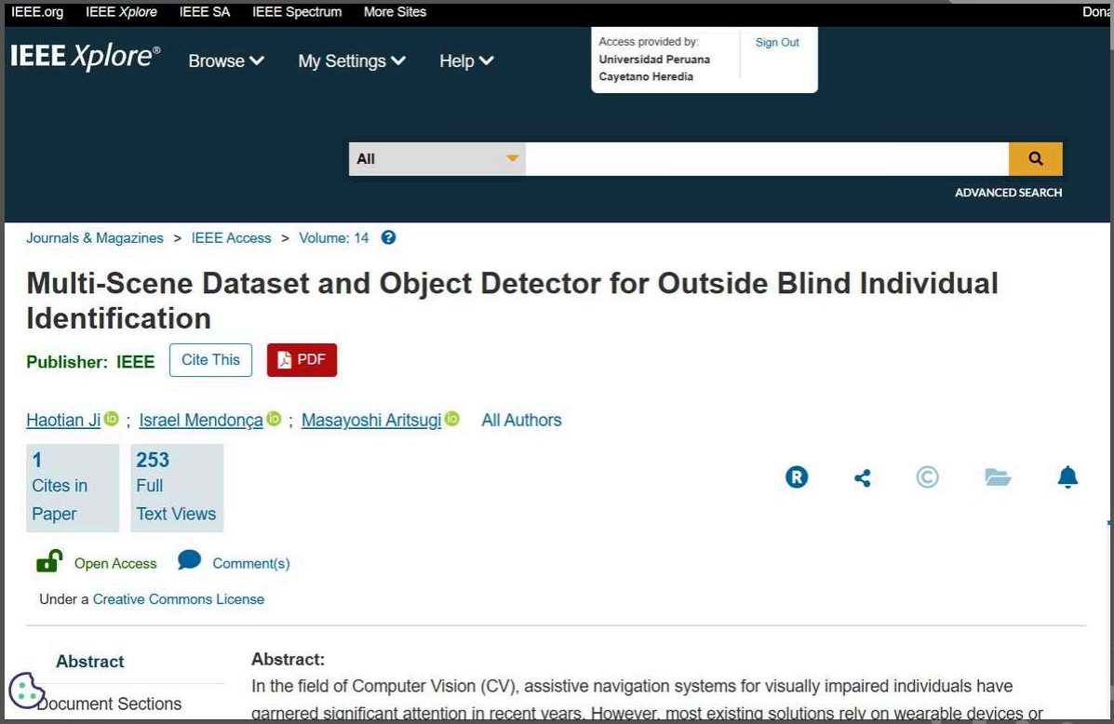
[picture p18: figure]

Ji H, Mendonça I, Aritsugi M. Multi-Scene Dataset and Object Detector for Outside Blind Individual Identification. IEEE Access, 2026.

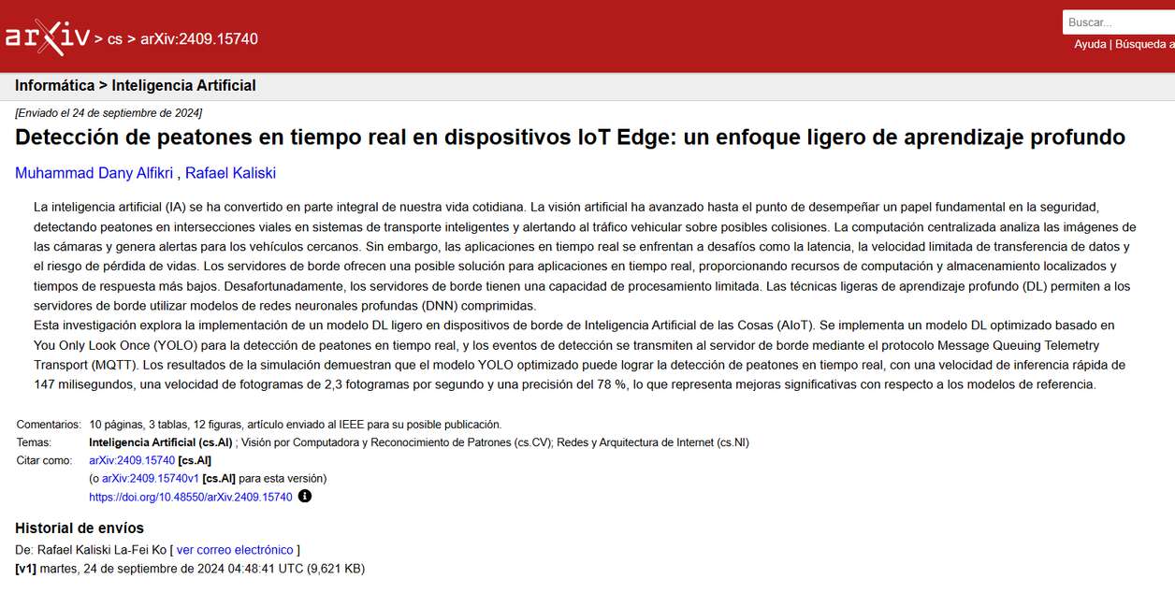
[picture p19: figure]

Aporte principal
Propone un modelo YOLO ligero optimizado para dispositivos IoT Edge, capaz de detectar peatones en tiempo real con bajo consumo de memoria y procesamiento, usando Jetson Nano. Limitación
Aunque | reduce | el | consumo
computacional, el modelo sacrifica parte de la precisión para lograr mayor velocidad de detección en tiempo real.

# Articulo 2:

Real-Time Pedestrian Detection on IoT Edge Devices: A Lightweight Deep Learning Approach

Alfikri MD, Kaliski R. Real-Time Pedestrian Detection on IoT Edge Devices: A Lightweight Deep Learning Approach. arXiv:2409.15740, 2024.

# TESIS

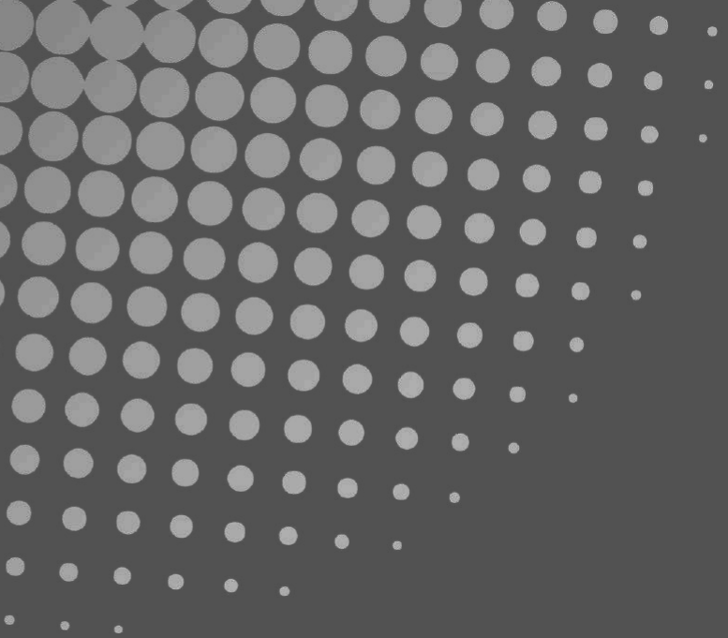
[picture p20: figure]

# Tesis 1:

## Cómputo vestible para asistir a personas con discapacidad visual

Balboa Trigo PA. Sistema de asistencia para personas con discapacidad visual basado en visión por computadora [tesis]. Centro de Investigación Científica y de Educación Superior de Ensenada [Internet]. 2020

# Tesis 1:

## Aplicaciones de visión artificial para ayuda a personas con dificultades visuales

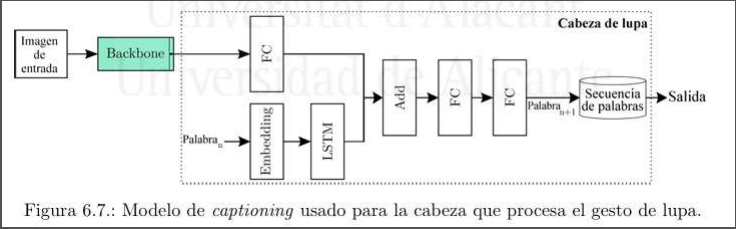
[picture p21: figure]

Hamzeh Alashhab SR. Aplicaciones de visión artificial para ayuda a personas con dificultades visuales [tesis doctoral]. Universidad de Alicante [Internet]. 2022

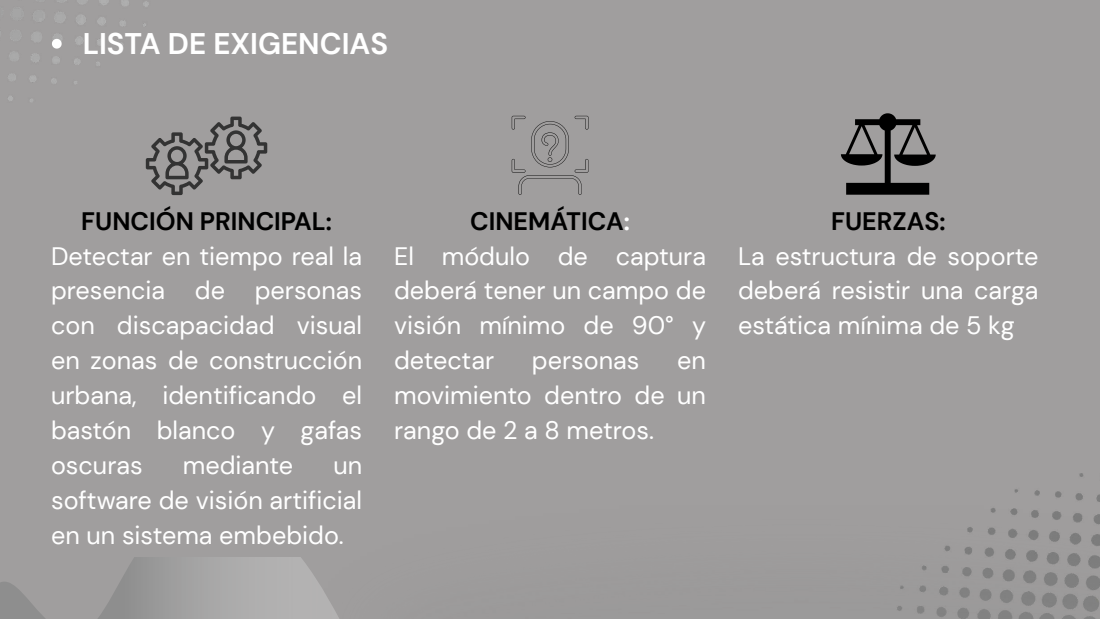
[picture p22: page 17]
oscuras; mediante; detectar; personas; FUERZAS:

LISTA DE EXIGENCIAS

FUNCIÓN PRINCIPAL:
Detectar en tiempo real la
presencia de personas
con discapacidad visual
en zonas de construcción
urbana, identificando el
bastón blanco y gafas
software de visión artificial
en un sistema embebido.

CINEMÁTICA:
El módulo de captura
deberá tener un campo de
visión mínimo de 90° y
movimiento dentro de un
rango de 2 a 8 metros.

La estructura de soporte
deberá resistir una carga
estática mínima de 5 kg

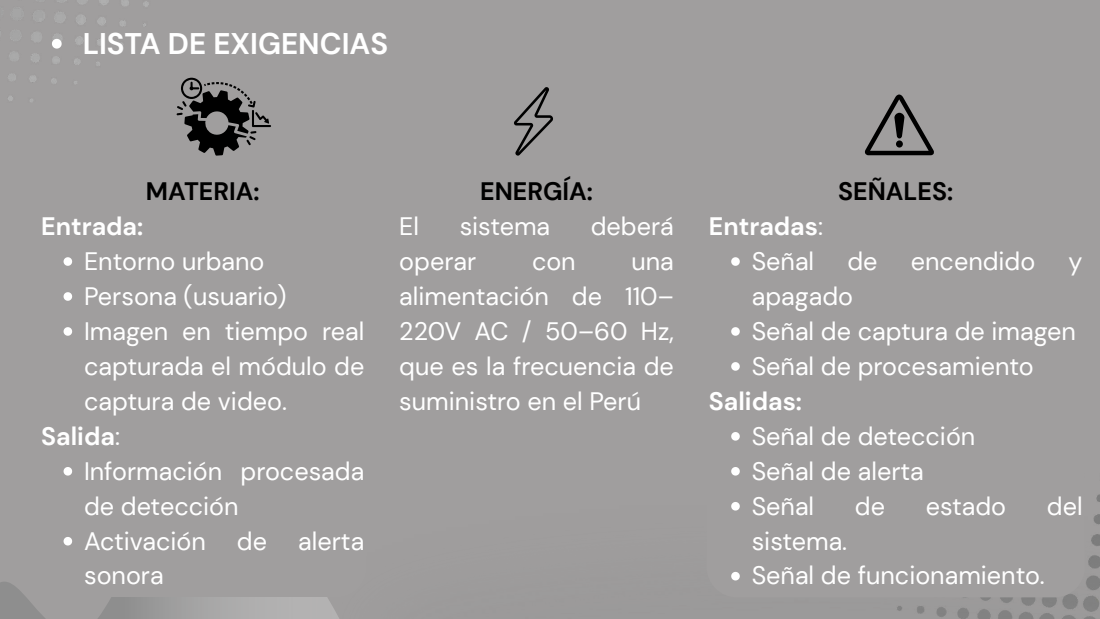
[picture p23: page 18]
MATERIA:; sistema; deberá; operar; con; una; SEÑALES:; Señal; estado; del

LISTA DE EXIGENCIAS

ENERGÍA:
alimentación de 110–
que es la frecuencia de
suministro en el Perú

Entrada:
Entorno urbano
Persona (usuario)
Imagen en tiempo real
capturada el módulo de
captura de video.
Salida:
Información procesada
de detección
Activación de alerta
sonora

Entradas:
Señal de encendido y
apagado
Señal de captura de imagen
Señal de procesamiento
Salidas:
Señal de detección
Señal de alerta
sistema.
Señal de funcionamiento.

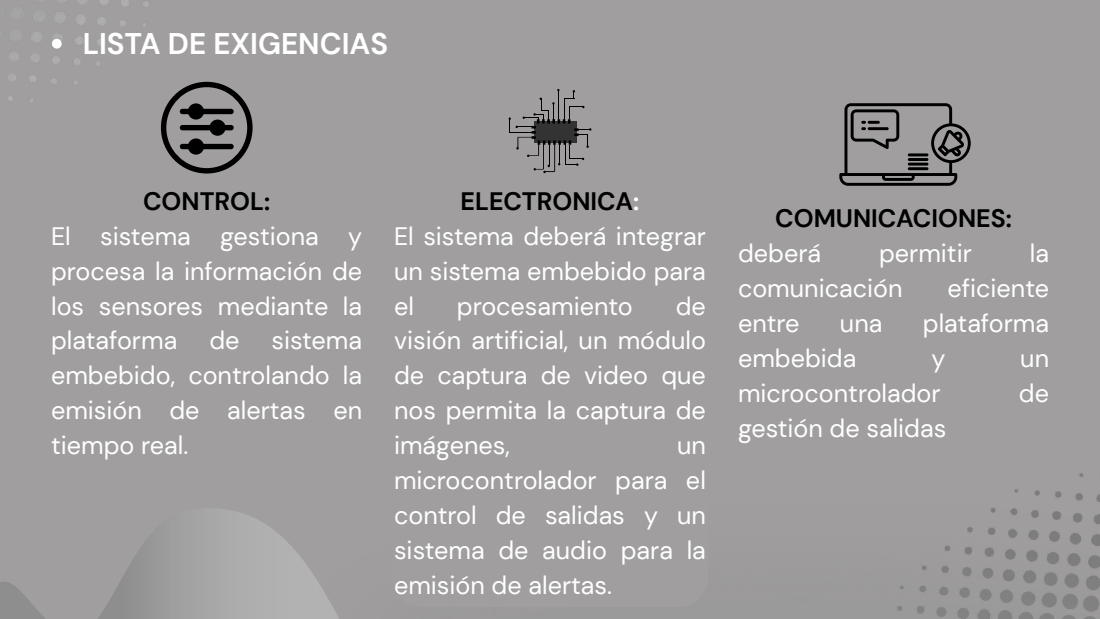
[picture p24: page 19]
procesamiento; imágenes,; deberá; permitir; comunicación; eficiente; entre; una; plataforma; embebida; microcontrolador

LISTA DE EXIGENCIAS

CONTROL:
El sistema gestiona y
procesa la información de
los sensores mediante la
plataforma de sistema
embebido, controlando la
emisión de alertas en
tiempo real.

ELECTRONICA:
El sistema deberá integrar
un sistema embebido para
visión artificial, un módulo
de captura de video que
nos permita la captura de
microcontrolador para el
control de salidas y un
sistema de audio para la
emisión de alertas.

COMUNICACIONES:
gestión de salidas

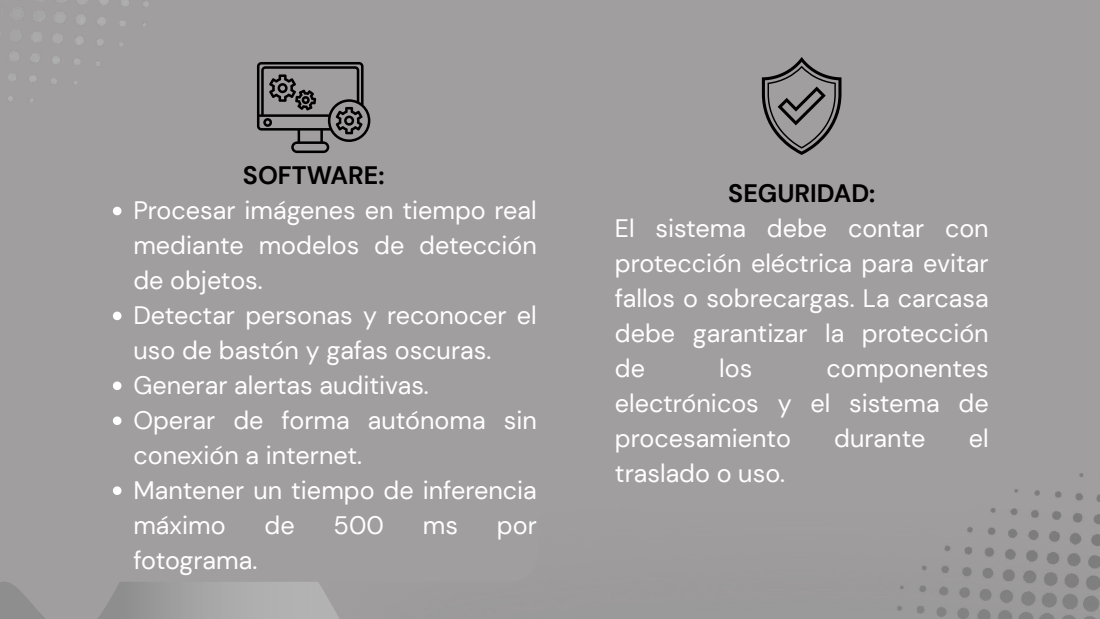
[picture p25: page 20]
SEGURIDAD:; los; componentes; procesamiento; durante; SOFTWARE:; máximo; por

Procesar imágenes en tiempo real
mediante modelos de detección
de objetos.
Detectar personas y reconocer el
uso de bastón y gafas oscuras.
Generar alertas auditivas.
Operar de forma autónoma sin
conexión a internet.
Mantener un tiempo de inferencia
fotograma.

El sistema debe contar con
protección eléctrica para evitar
fallos o sobrecargas. La carcasa
debe garantizar la protección
electrónicos y el sistema de
traslado o uso.

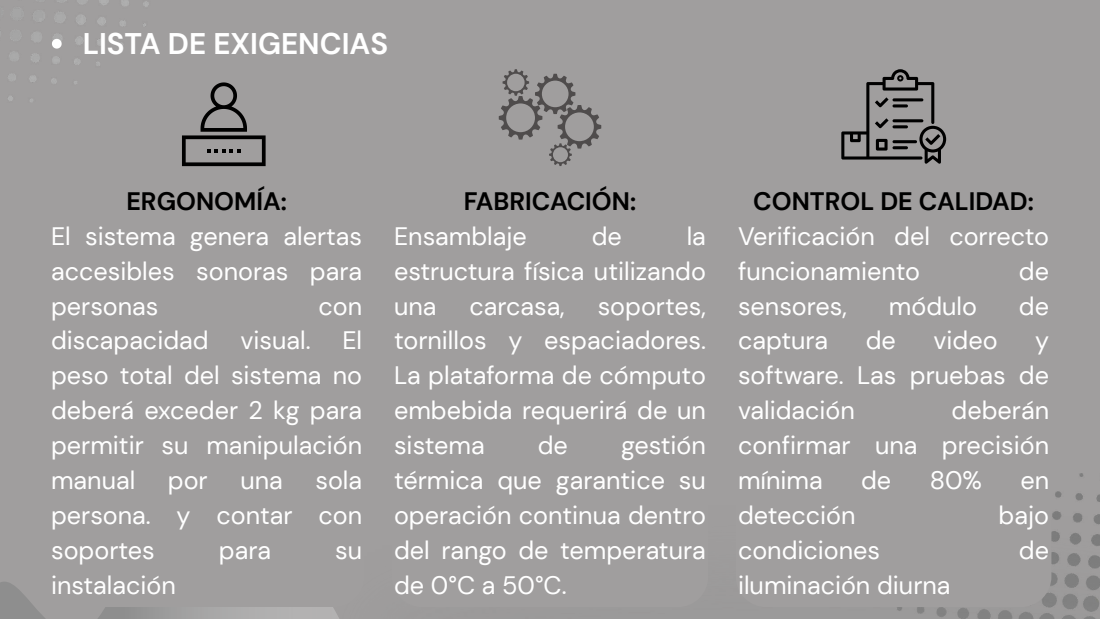
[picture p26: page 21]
personas; con; soportes; para; Ensamblaje; sistema; gestión; funcionamiento; sensores,; módulo; captura; video; validación; deberán; mínima; detección; bajo; condiciones

LISTA DE EXIGENCIAS

ERGONOMÍA:
El sistema genera alertas
accesibles sonoras para
discapacidad visual. El
peso total del sistema no
deberá exceder 2 kg para
permitir su manipulación
manual por una sola
persona. y contar con
instalación

FABRICACIÓN:
estructura física utilizando
una carcasa, soportes,
tornillos y espaciadores.
La plataforma de cómputo
embebida requerirá de un
térmica que garantice su
operación continua dentro
del rango de temperatura

CONTROL DE CALIDAD:
Verificación del correcto
software. Las pruebas de
confirmar una precisión
iluminación diurna

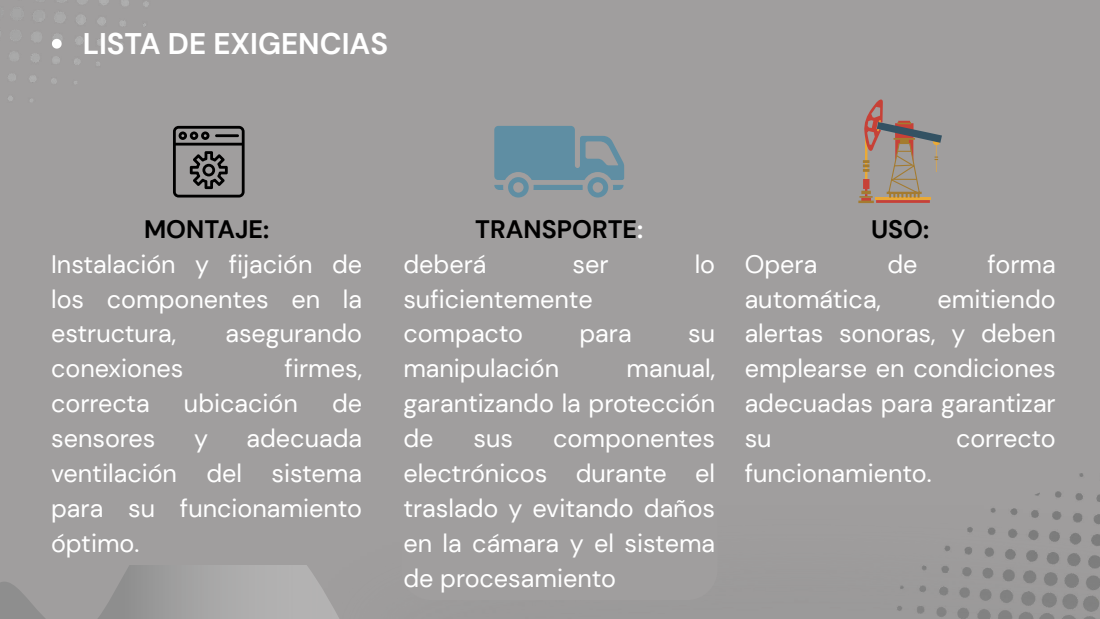
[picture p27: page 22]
MONTAJE:; estructura,; asegurando; conexiones; firmes,; sensores; adecuada; deberá; ser; compacto; para; manipulación; manual,; sus; componentes; traslado; y evitando daños; USO:; Opera; forma; automática,; emitiendo; correcto

LISTA DE EXIGENCIAS

TRANSPORTE:
suficientemente
garantizando la protección
electrónicos durante el
en la cámara y el sistema
de procesamiento

Instalación y fijación de
los componentes en la
correcta ubicación de
ventilación del sistema
para su funcionamiento
óptimo.

alertas sonoras, y deben
emplearse en condiciones
adecuadas para garantizar
funcionamiento.

MANTENIMIENTO:
Dado de que el sistema tiene como fin salvaguardar la vida y salud de las personas,
especialmente | con | discapacidad, | las
revisiones correspondientes al mantenimiento del equipo se darán de manera diaria (verificación de encendido y prueba del altavoz), semanal (limpieza del módulo de captura de video, rejilla y revisión de cables) y mensual (revisión completa de conexiones internas, disipador, sensores y actualización de software). Además, cada vez que culmine

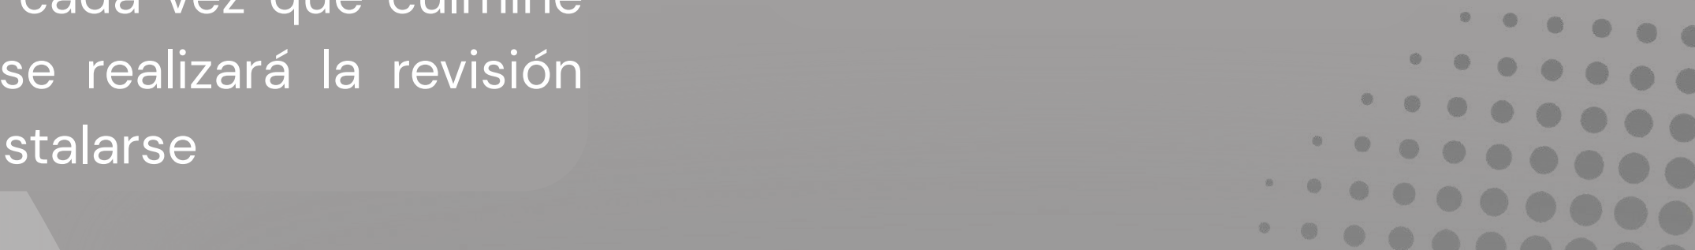
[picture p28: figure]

la obra e inicie otra, se realizará la revisión completa antes de reinstalarse

### LISTA DE EXIGENCIAS

COSTOS:
Costos de fabricación no
debe de exceder los
S/300.

PLAZOS:
El proyecto inició el lunes 16 de marzo y se espera
su finalización durante el fin de mes de junio.

### ESTRUCTURA DE FUNCIONES

Caja negra (Black Box)

### 7.1.1. Entradas

- Energía:
- Energía Eléctrica
- Señales:
- Señal de video en tiempo real
- Señal de control (encendido/ apagado)

### 7.1.2. Salidas

- Energía:
- Alerta sonora (altavoz).
- Señales:
- Señal de detección confirmada

## 7.2. Secuencia de operaciones 7.2.1. Nivel usuario

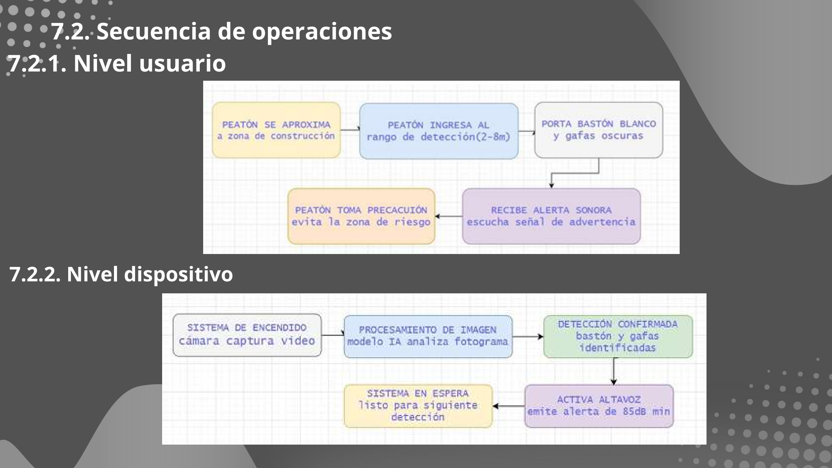
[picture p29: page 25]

### 7.2.2. Nivel dispositivo

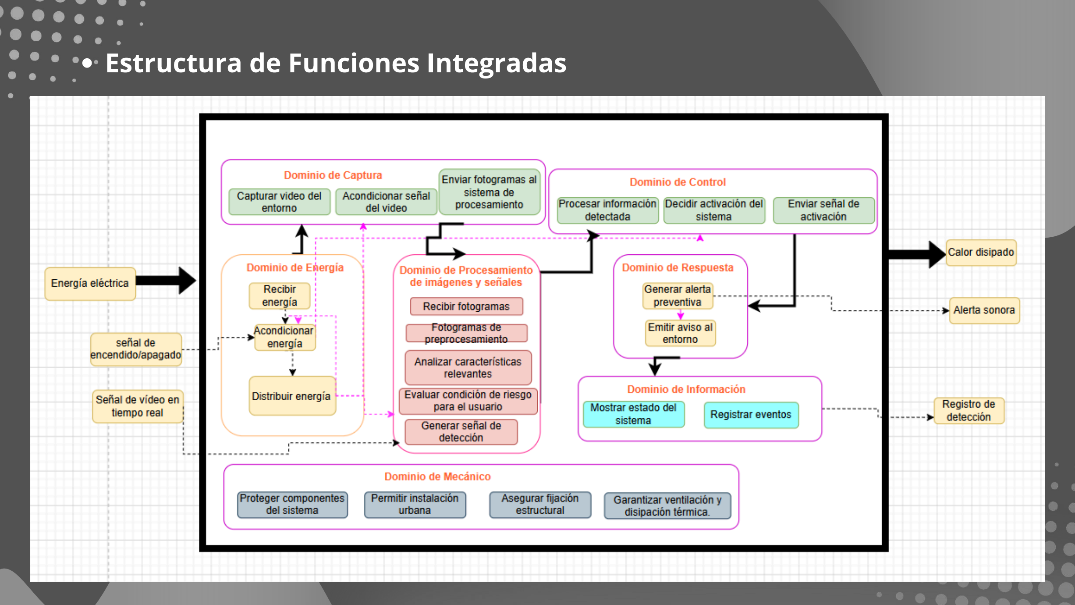
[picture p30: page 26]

Estructura de Funciones Integradas

DOMINIO | FUNCIONES PARCIALES | SOLUCIÓN 1 | SOLUCIÓN 2 | SOLUCIÓN 3
Electrónico | Captura visual · Acondicionamiento · Procesamiento · Gestión de salidas | Cámara RGB + Raspberry Pi + ESP32 | Sensor IR + Jetson Nano + control automático | Sensor ultrasónico + plataforma de bajo consumo
Mecánico | Proteger componentes · Instalación urbana | Carcasa 3D + soporte en poste | Encapsulado metálico + montaje mural | Protección impermeable + fijación estructural

### Matrices morfológicas por dominio

Energía

Alimentar el sistema ·
Regular y distribuir
energía

Fuente AC/DC +
regulador AC/DC

Panel solar + gestión
energética
Control | Tomar decisión de activación · Gestionar señales de salida | Lógica programada con ESP32 | Control automático basado en eventos | Sistema reactivo mediante señales digitales
| Analizar imagen · | Visión artificial + IA + | Procesamiento digital + plataforma IoT | Reconocimiento de patrones + registro microSD
| Software | Detectar riesgo · Registrar eventos
base de datos local

Batería recargable +
protección eléctrica

### Bocetos — Tres conceptos de solución

SOLUCIÓN 1 | SOLUCIÓN 2 | SOLUCIÓN 3

### Evaluación De Matriz PUGH


Referencias:
1.Contraloría General de la República del Perú. Informe de obras públicas paralizadas en el territorio nacional a diciembre 2025. Informe N° 001-2026-CG/SESNC [Internet]. Lima: Contraloría General
de | la | República; | febrero | 2026 | [citado | 2026]. | Disponible | en:
https://cdn.www.gob.pe/uploads/document/file/9416533/7715417-informe-de-obras-publicas-paralizadas-en-el-territorio-nacional-a-diciembre-2025f.PDF (https://cdn.www.gob.pe/uploads/document/file/9416533/7715417-informe-de-obras-publicas-paralizadas-en-el-territorio-nacional-a-diciembre-2025f.PDF)
2.Instituto Nacional de Estadística e Informática (INEI). En el Perú 1 millón 575 mil personas presentan algún tipo de discapacidad [Internet]. Lima: INEI; 2013 [citado el 11 de mayo de 2026].
Disponible | en: | https://m.inei.gob.pe/prensa/noticias/en-el-peru-1-millon-575-mil-personas-
presentan-alg/ (https://m.inei.gob.pe/prensa/noticias/en-el-peru-1-millon-575-mil-personas-presentan-alg/)
3.Organización Internacional del Trabajo. Seguridad y salud en la construcción (Edición revisada)
[Internet]. | Ginebra: | OIT; | 2022 | [citado | 2026]. | Disponible | en:
https://www.ilo.org/es/resource/otros/seguridad-y-salud-en-la-construccion-edicion-revisada 4.Instituto Nacional de Estadística e Informática. Perfiles sociodemográficos de la población con
discapacidad | [Internet]. | Lima: | INEI; | 2019 | [citado | 2025]. | Disponible | en:
https://www.inei.gob.pe/media/MenuRecursivo/publicaciones_digitales/Est/Lib1675/libro.pdf 5.Radio Yaráví Arequipa. Personas con discapacidad visual enfrentan desafíos en calles de Arequipa
[Internet]. | Arequipa: | Radio | Yaráví; | 2024 | [citado | 2025]. | Disponible | en:
https://radioyaravi.org.pe/noticia/informes-especiales/personas-con-discapacidad-visual-enfrentan-desafios-en-calles-de-arequipa/ (https://radioyaravi.org.pe/noticia/informes-especiales/personas-con-discapacidad-visual-enfrentan-desafios-en-calles-de-arequipa/)
6.Seminario-Hurtado N, Alfaro Torres HM. Accesibilidad en entornos urbanos para personas con discapacidad visual en el Perú: un análisis normativo. Cuadernos de Vivienda y Urbanismo
[Internet]. | 2025 | [citado | 2025]; | 18. | Disponible | en:
https://revistas.javeriana.edu.co/index.php/cvyu/article/view/41190/

Referencias:
7.Ji H, Mendonça I, Aritsugi M. Multi-Scene Dataset and Object Detector for Outside Blind Individual Identification. IEEE Access [Internet]. 2026 [citado 2026]; 14: 1423-1438. Disponible en: https://ieeexplore.ieee.org/document/11317963
8. Alfikri MD, Kaliski R. Real-Time Pedestrian Detection on IoT Edge Devices: A Lightweight Deep
Learning | Approach. | arXiv | [Internet]. | 2024 | [citado | 2025]. | Disponible | en:
https://arxiv.org/abs/2409.15740
9.Leong X, Kanesaraj Ramasamy R. Obstacle Detection and Distance Estimation for Visually Impaired People. IEEE Access [Internet]. 2023 [citado 2025]; 11: 136609-136629. Disponible en: https://ieeexplore.ieee.org/document/10336791
10.Balboa Trigo PA. Sistema de asistencia para personas con discapacidad visual basado en visión por computadora [tesis]. Centro de Investigación Científica y de Educación Superior de
Ensenada | [Internet]. | 2020 | [citado | 2026]. | Disponible | en:
https://cicese.repositorioinstitucional.mx/jspui/bitstream/1007/3362/1/Tesis_Pablo%20Alberto%20Balboa%20Trigo_20%20nov%202020.pdf (https://cicese.repositorioinstitucional.mx/jspui/bitstream/1007/3362/1/Tesis_Pablo%20Alberto%20Balboa%20Trigo_20%20nov%202020.pdf)
11.Hamzeh Alashhab SR. Aplicaciones de visión artificial para ayuda a personas con dificultades visuales [tesis doctoral]. Universidad de Alicante [Internet]. 2022 [citado 2026]. Disponible en: https://rua.ua.es/entities/publication/162679e1-c5dd-4986-ba1e-3bfc306f8c11
12.Instituto Nacional de Estadística e Informática (INEI). En el Perú 1 millón 575 mil personas presentan algún tipo de discapacidad [Internet]. Lima: INEI; [citado 2026 May 11]. Disponible en: https://m.inei.gob.pe/prensa/noticias/en-el-peru-1-millon-575-mil-personas-presentan-alg/

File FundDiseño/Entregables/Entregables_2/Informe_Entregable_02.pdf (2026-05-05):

## UNIVERSIDAD PERUANA CAYETANO HEREDIA

FACULTAD DE CIENCIAS E INGENIERÍA


### Proyecto de Fundamentos de Diseño

### SafeWalk AI

Docentes:
- Mugaburu Celi, Marco Antonio
- Chan Rios, Renzo Jose
- Jacinto Calderon, Cristhian Gustavo
- Rivera Tito, Harry Anderson

Nombres y apellidos del estudiante:

- Areche Espeza, Angello
- Mori Mendoza, Daniela
- Tomanguilla Huaman, Leslie Stephany
- Ronceros Huaynapomas, Rolando Smith
- Ccoyllo Sotelo, Alex
2026

## ÍNDICE:

### 1. INTRODUCCIÓN:

El crecimiento de las ciudades peruanas conlleva una ejecución constante de obras de construcción, mantenimiento vial e instalación de servicios públicos que modifican de forma temporal el espacio urbano. Estas intervenciones generan entornos dinámicos y cambiantes que pueden representar un riesgo para los peatones, en particular cuando la señalización de seguridad instalada está basada exclusivamente en elementos visuales como conos, cintas de advertencia y carteles informativos. En el Perú, la Contraloría General de la República ha identificado que a diciembre de 2025 existen 2,416 obras públicas paralizadas a nivel nacional, con una inversión comprometida superior a los S/ 67 mil millones, siendo Lima uno de los departamentos con mayor número de obras detenidas con 167 proyectos paralizados, muchos de los cuales afectan veredas y espacios peatonales sin contar con mecanismos de alerta accesibles para todos los ciudadanos [1].

Esta situación representa un riesgo especialmente grave para las personas con discapacidad visual. A diferencia del resto de peatones, estas personas se orientan en la ciudad mediante rutas memorizadas, apoyándose en referencias como la cantidad de pasos, la textura del suelo y los sonidos del entorno. Cuando una obra clausura o modifica una vereda, esa ruta memorizada deja de coincidir con la realidad, exponiéndose a caídas, colisiones con materiales de construcción o desvíos involuntarios hacia la calzada. Un estudio del Banco Interamericano de Desarrollo concluyó que las personas con discapacidad visual son las más afectadas por las barreras presentes en el entorno urbano, especialmente en espacios donde la infraestructura cambia de forma temporal e imprevista [2]. En estos casos, la ausencia de mecanismos de alerta sonora en las zonas de obra representa una brecha crítica de accesibilidad e inclusión.

### 2. PROBLEMÁTICA:

En el Perú, las obras de construcción en espacios urbanos representan un riesgo concreto para los peatones. Según la Organización Internacional del Trabajo, el sector construcción concentra un alto porcentaje de accidentes a nivel mundial, en parte por las condiciones dinámicas y cambiantes de las obras, y por la señalización frecuentemente insuficiente o inadecuada en estos espacios [3]. En el ámbito local, esta problemática se evidencia con regularidad: la Contraloría General reportó que a diciembre de 2025 existen 167 obras paralizadas en Lima, pertenecientes a un total de 2,416 a nivel nacional, muchas de las cuales ocupan veredas y espacios peatonales sin cumplir con estándares mínimos de señalización accesible [3, 1].

Esta problemática se vuelve crítica para las personas con discapacidad visual. Los Censos Nacionales 2017 del INEI revelaron que aproximadamente 1,966,766 personas en el Perú experimentan limitaciones permanentes en la visión, de las cuales el 52.6% reside en zonas urbanas [4]. Estas personas se desplazan guiándose por referencias espaciales memorizadas -- cantidad de pasos, texturas del suelo, sonidos del entorno-- que les permiten construir rutas mentales conocidas. Cuando una obra clausura o modifica temporalmente una vereda, esa ruta memorizada deja de coincidir con la realidad física, exponiéndolas a caídas, colisiones con materiales de construcción o desvíos involuntarios hacia la calzada vehicular.

Esta realidad no es abstracta. Roxana, una mujer de 56 años con discapacidad visual residente en Arequipa que utiliza el bastón blanco desde hace más de una década, describe con precisión el impacto que tienen las obras en su desplazamiento diario: "Cada vez que se realizan obras en Arequipa, abren el pavimento y lo dejan amontonado: escombros, arena, tierra, ladrillos y cascajos ocupan las veredas. Todo eso representa un obstáculo para desplazarnos. El bastón se nos atasca en esos huecos". Este testimonio refleja una problemática extendida en las ciudades peruanas, donde las intervenciones en la infraestructura urbana no contemplan mecanismos de aviso accesibles para personas invidentes [5].

### 3. JUSTIFICACIÓN DEL PROYECTO:

Frente a esta problemática, surge la necesidad de desarrollar soluciones tecnológicas que protejan a las personas con discapacidad visual en zonas de obra. En el Perú, la Norma Técnica A.120 de Accesibilidad Universal del Reglamento Nacional de Edificaciones establece la obligatoriedad de señalización accesible en espacios de construcción, incluyendo señalización podotáctil y auditiva en zonas de riesgo [6]. Sin embargo, su implementación es deficiente: en 2026, el 85% de las inspecciones de CONADIS reportaron incumplimientos en señalética, evidenciando que las normas existentes no se traducen en acciones concretas en los espacios de obra [6].

Las medidas tradicionales de seguridad en zonas de obra —cintas de advertencia, conos de señalización, carteles informativos y barreras físicas— dependen exclusivamente de la percepción visual y no ofrecen ningún tipo de alerta para quienes no pueden verlas. Esta brecha evidencia la necesidad de incorporar soluciones complementarias que utilicen el canal auditivo para transmitir información de riesgo de manera efectiva a las personas invidentes que se aproximan a una zona de obra.

### 4. OBJETIVOS DEL PROYECTO:

### 4.1. Objetivo general

Desarrollar un sistema embebido de detección automática que identifique en tiempo real la presencia de personas con discapacidad visual en zonas de construcción urbana, mediante visión artificial, y active una alerta sonora para advertir el riesgo.

### 4.2. Objetivos específicos

1. Identificar los requerimientos técnicos del sistema a partir del análisis del estado de la tecnología y las necesidades de accesibilidad en entornos urbanos peruanos.
2. Diseñar la arquitectura del sistema integrando un módulo de captura de video, una plataforma de procesamiento embebido con modelo de detección de objetos, y un subsistema de alerta sonora.
3. Seleccionar los componentes electrónicos y de software adecuados mediante una matriz morfológica y una evaluación técnico-económica (Matriz de Pugh).
4. Implementar un prototipo funcional capaz de detectar el bastón blanco y gafas oscuras como indicadores de discapacidad visual, operando de forma autónoma sin conexión a internet.
5. Verificar el funcionamiento del sistema mediante pruebas de detección en condiciones simuladas de zona de obra urbana.

### 5. ESTADO DE LA TECNOLOGÍA:

### 5.1. Tecnología existente en el ámbito comercial

A continuación, se presentan tecnologías en el ámbito comercial:

5.1.1. OrCam MyEye: Visión Artificial Portable
Soluciones | Descripción | Sensores usados
- Lectura de textos. • Reconocimiento de rostros. • Identificador de objetos/productos. • Reconocimiento de billetes • Apoyo en actividades diarias. | Es un dispositivo portátil de asistencia visual que se acopla a unas gafas y utiliza inteligencia artificial para analizar el entorno en tiempo real. Su función principal es capturar información visual mediante una cámara y transformarla en información auditiva, permitiendo al usuario reconocer textos, objetos y rostros, facilitando su autonomía en actividades cotidianas. | • Sensor óptico (cámara)


5.1.2. WeWALK: El Bastón Blanco Inteligente
Soluciones | Descripción | Sensores usados
- Detección de obstáculos (a nivel superior) • Navegación guiada (tipo GPS) • Información del entorno cercano • Asistencia por voz • Alertas mediante vibración y sonido | Permite al usuario desplazarse con mayor seguridad mediante la detección de obstáculos no percibidos por bastones tradicionales, proporcionando además guía paso a paso e información del entorno. Integra retroalimentación por vibración y audio, junto con funciones de exploración y acceso a servicios, favoreciendo una interacción eficiente y autónoma. | • Sensor ultrasónico

5.1.3. Glidance Glide
Soluciones | Descripción | Sensores usados
- Guiado autónomo • Detección y evasión de obstáculos • Identificación de puntos clave • Navegación asistida • Retroalimentación multimodal (audio y háptica) • Mantenimiento de trayectoria segura | Dispositivo de movilidad asistida que emplea robótica e inteligencia artificial para guiar al usuario en tiempo real, mediante detección de obstáculos y generación de trayectorias seguras, incorporando retroalimentación auditiva y háptica para facilitar la navegación autónoma. | • Cámara estéreo de profundidad (detección espacial y reconocimiento de entorno). • Sensores de proximidad (detección de obstáculos y desniveles). • Conjunto de sensores avanzados para percepción del entorno en tiempo real.


### 5.2. Tecnología existente en el ámbito de patentes

A continuación, se presenta las patentes en orden cronológico.

a) Módulo óptico para semáforos peatonales con indicación acústica para personas con discapacidad visual

Número de
publicación:
ES1073627U

Inventores:
Ursueguia Balbuena,
Andrés; Bravo Rendo,
Juan Carlos

Fecha de publicación:
11/01/2011


b) Método de detección de peatones y cámara de vigilancia relacionada.

Descripción: Consiste en un módulo instalado en semáforos peatonales compuesto por LEDs conectados a un módulo electrónico de gestión de iluminación y al menos un elemento de indicación acústica conectado a un módulo de gestión de sonido. La alerta sonora se activa en función del ciclo del semáforo para facilitar el cruce a personas con deficiencias visuales.

Relevancia:
Esta patente confirma el principio fundamental del proyecto: la alerta sonora sincronizada con una condición detectada es una solución validada técnicamente para asistir a personas con discapacidad visual en espacios urbanos. A diferencia de este módulo que reacciona al ciclo del semáforo, SafeWalk AI reacciona a la detección visual de la persona, lo que lo hace aplicable a cualquier zona de riesgo sin depender de infraestructura semafórica.

Ilustración:

Número de
publicación:
US10719707B2

Inventor:
Chen Sheng-Yuan; Yu
Hsun-Shun; Liu Cheng-Chieh

Fecha de publicación:
21/07/2020

Descripción: Consiste en un método aplicado a cámaras de vigilancia fijas que forma ventanas de detección progresivas sobre fotogramas de video para identificar y rastrear peatones en tiempo real, distinguiendo peatones individuales de grupos solapados mediante comparación de ventanas de detección.

Relevancia: El método de detección progresiva por ventanas sobre fotogramas de video es directamente aplicable al procesamiento de imágenes en SafeWalk AI. La estrategia de distinguir objetos similares (personas individuales vs. grupos) es análoga al reto de distinguir un bastón blanco de otros objetos alargados, problema que el proyecto aborda mediante entrenamiento del modelo con clases de distracción.


c) Método y sistema de navegación inteligente para personas con discapacidad visual.

Ilustración:

Número de
publicación:
US2021369545A1

Inventor:
Ghosh, Arko Ayan

Fecha de publicación:
02/12/2021

Descripción: Consiste en un bastón inteligente (i-Cane) que detecta objetos en el camino de la persona, mide su distancia, los identifica mediante visión artificial y alerta al usuario mediante voz sobre los obstáculos que se aproximan. El sistema integra una mini computadora de placa única, sensor ultrasónico, cámara y síntesis de voz.
Relevancia: Esta patente valida la combinación sensor ultrasónico, cámara y síntesis de voz como arquitectura viable para asistencia a personas invidentes, componentes que SafeWalk AI también integra.


### 5.3. Factores comunes en el estado de arte

A partir del análisis de la tecnología existente en el ámbito comercial y de patentes, en esta sección se presentan los factores comunes identificados a partir de la revisión de artículos científicos y tesis de repositorios institucionales, con el objetivo de caracterizar el estado actual del conocimiento en torno a los sistemas de asistencia para personas con discapacidad visual y la detección de objetos mediante visión artificial.
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

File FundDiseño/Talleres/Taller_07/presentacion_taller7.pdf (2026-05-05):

LISTA DE EXIGENCIAS

Pág … de …

Edición: |

PROYECTO:
SafeWalk AI
Fecha: |
Revisado: |
CLIENTE: | Empresas constructoras que ejecutan obras en espacios públicos urbanos. | Elaborado: A,J,M,R, E
Fecha (cambios) | Deseo o Exigencia | DESCRIPCIÓN. | Responsable
16/04/2026 | E | FUNCIÓN PRINCIPAL: Detectar en tiempo real la presencia de personas con discapacidad visual en zonas de construcción urbana, identificando el bastón blanco y gafas oscuras mediante un software de visión artificial en un sistema embebido, para luego activar automáticamente una alerta sonora a través de un microcontrolador de gestión de salida para advertir el peligro. | Todos
16/04/2026 | E | GEOMETRÍA: El sistema deberá ser compacto para facilitar su instalación en zonas de riesgo urbano. Se estima una dimensión aproximada de 35 cm de alto, 25 cm de ancho y 15 cm de profundidad, considerando la integración de un sistema embebido, microcontrolador de gestión de salida, el sistema de alerta sonora y la fuente de alimentación. | J
16/04/2026 | E | CINEMÁTICA: El sistema deberá contar con un campo de visión adecuado que permita detectar personas en movimiento dentro de un rango definido frente al dispositivo. El módulo de captura el video deberá estar orientada estratégicamente para cubrir la zona de riesgo, garantizando la detección oportuna sin necesidad de partes móviles. | J
16/04/2026 | E | FUERZAS:El sistema deberá contar con una estructura de soporte y fijación capaz de resistir su propio peso, así como las cargas y vibraciones generadas por su instalación en entornos urbanos, garantizando estabilidad y seguridad durante su funcionamiento. | J
16/04/2026 | E | MATERIA: Entrada: Entorno urbano Persona (usuario) Imagen en tiempo real capturada el módulo de captura de video. Salida: Información procesada de detección Activación de alerta sonora | M
19/04/2026 | E | ENERGÍA: El sistema deberá alimentarse desde una fuente de energía eléctrica externa disponible en la zona de obra, contando con protección eléctrica para evitar fallos o sobrecargas | J
19/04/2026 | E

SEÑALES:El sistema deberá contar con señales de entrada y salida para su correcto funcionamiento.

Entradas:Señal de encendido y apagado: Permite iniciar o detener el sistema manualmente. Señal de captura de imagen: Recibe información visual desde el módulo de captura de video para su procesamiento.
Señal de procesamiento: Activa el análisis de imágenes mediante el modelo de inteligencia artificial.

Salidas:Señal de detección: Indica la identificación de objetos relevantes, como personas o bastón.
Señal de alerta: Genera notificaciones auditivas mediante un sistema de alerta sonora ante posibles riesgos.
Señal de estado del sistema: Indica si el sistema se encuentra activo, en procesamiento o en espera.
Señal de funcionamiento: Permite verificar que el sistema está operando correctamente.

J

20/04/2026 | E | CONTROL: El sistema gestiona y procesa la informacion de los sensores mediante la plataforma de sistema embebido, ejecutando los algoritmos de inteligencia artificial y controlando la emisión de alertas en tiempo real. | J
26/04/2026 | E | ELECTRONICA (Hardware): El sistema deberá integrar un sistema embebido para el procesamiento de visión artificial, un módulo de captura de video que nos permita la captura de imagenes, un microcontrolador para el control de salidas y un sistema de audio para la emisión de alertas. | A

SOFTWARE:Se utilizará un sistema basado en inteligencia artificial y visión artificial para el procesamiento de imágenes en tiempo real, ejecutado sobre una plataforma embebida.

19/04/2026 | E
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

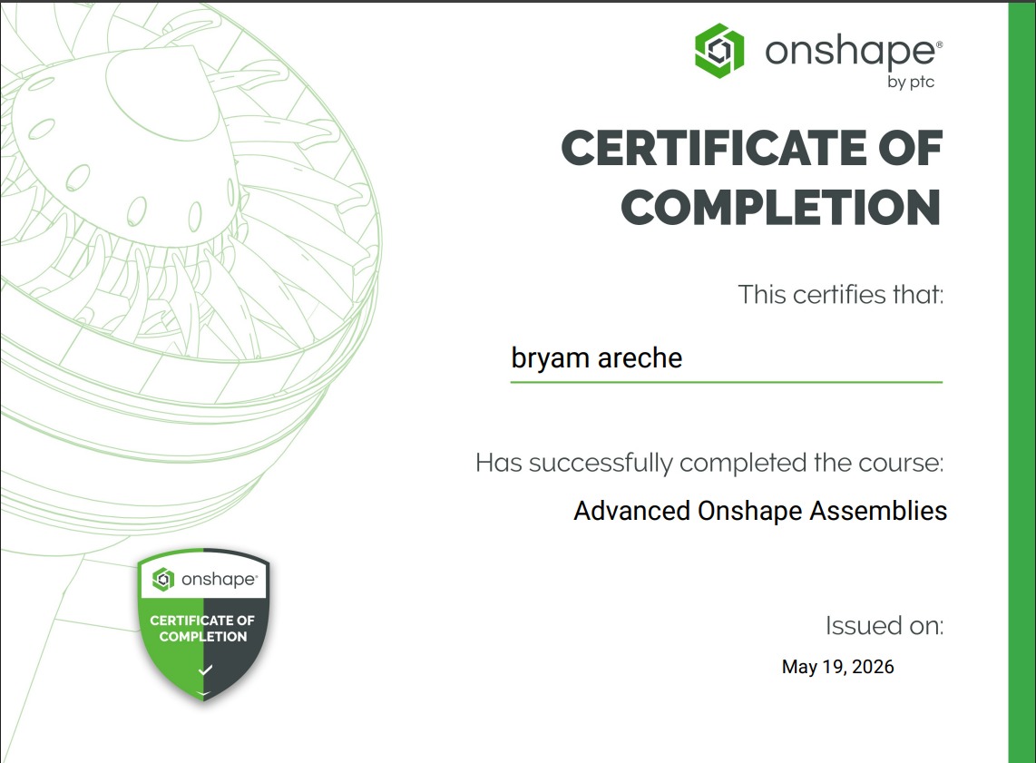
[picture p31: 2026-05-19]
FundDiseño/Talleres/Taller_10/Onshape Areche Angello/WhatsApp Image 2026-05-19 at 3.43.13 PM.jpeg

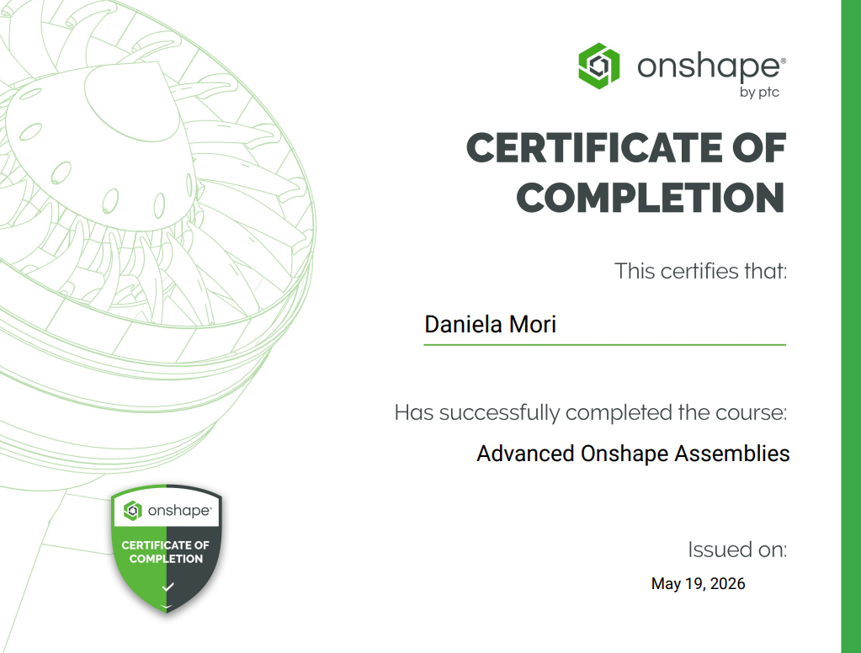
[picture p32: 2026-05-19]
FundDiseño/Talleres/Taller_10/Onshape Mori Daniela/Captura de pantalla 2026-05-19 145930.png

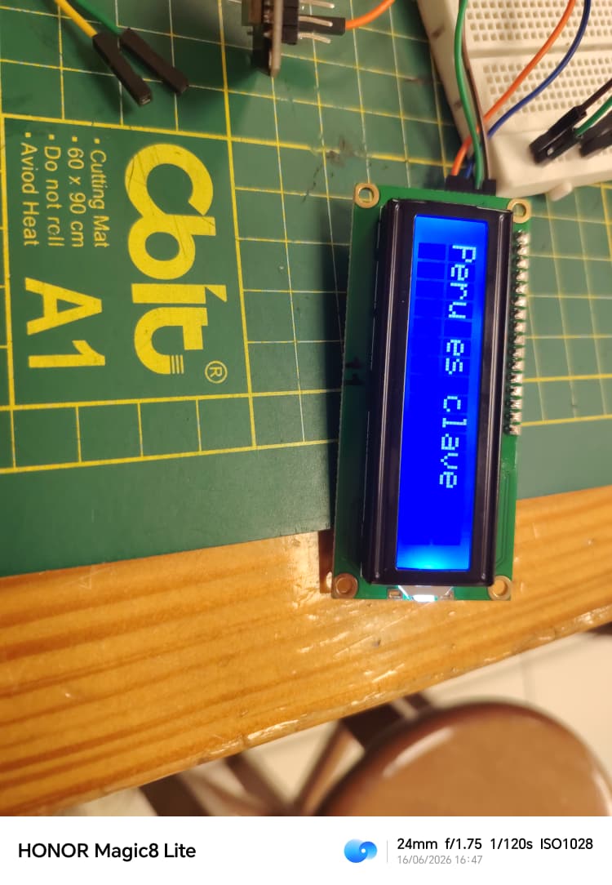
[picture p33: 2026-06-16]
FundDiseño/Talleres/Taller_14/# IMAGEN Ploteo de mensaje en LCD 2x16 a través.jpeg

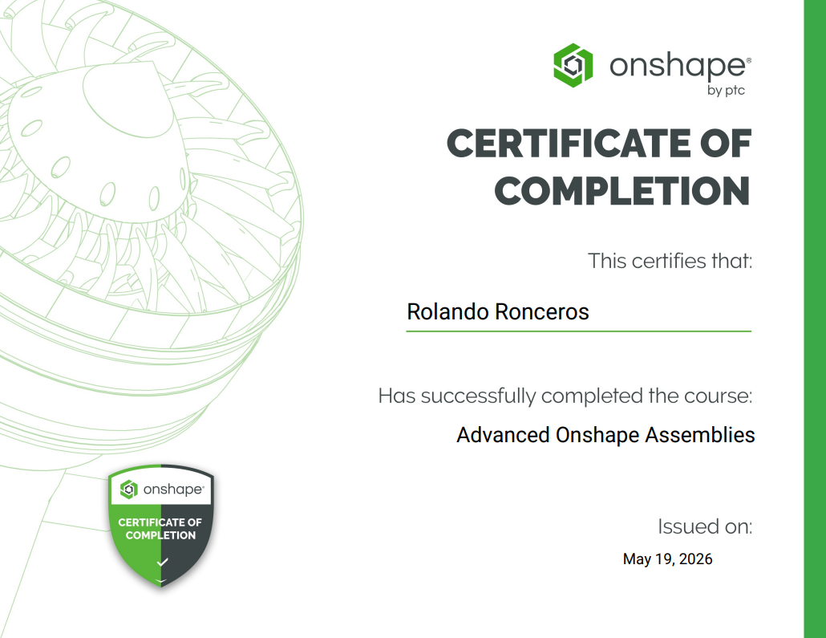
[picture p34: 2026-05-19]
FundDiseño/Talleres/Taller_10/Onshape Ronceros Rolando/Captura de pantalla 2026-05-19 143905.png

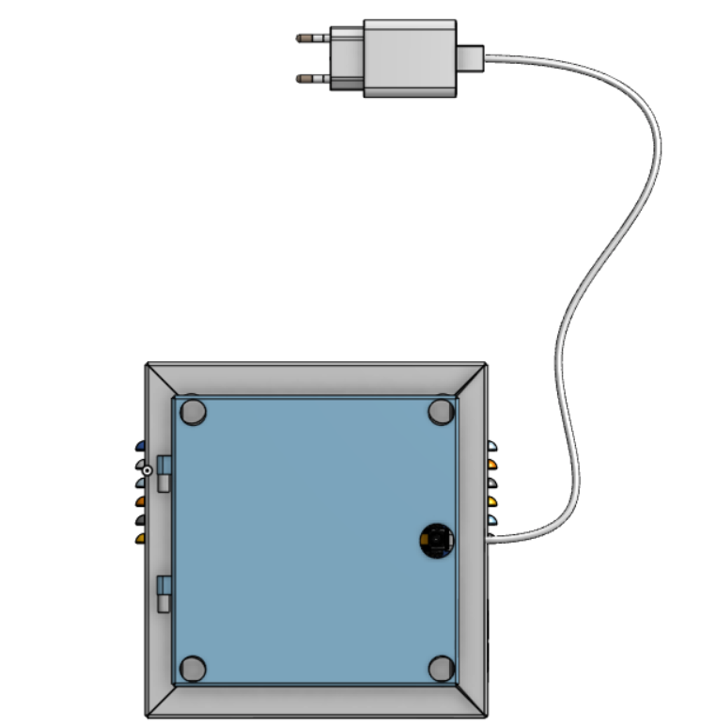
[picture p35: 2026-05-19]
FundDiseño/Talleres/Modelado 3d de onshape/Captura de pantalla 2026-05-18 201144.png

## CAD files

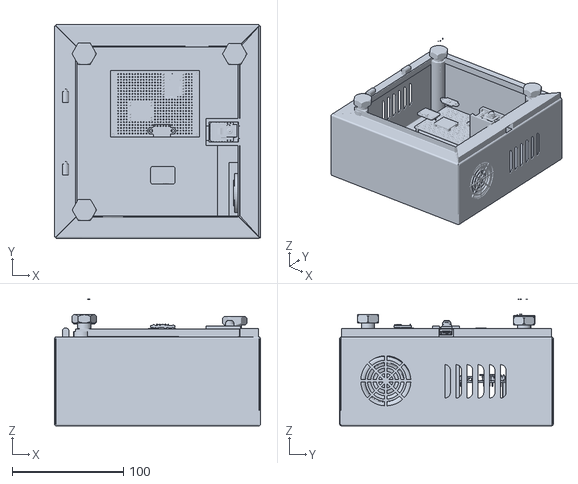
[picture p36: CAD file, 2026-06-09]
FundDiseño/Entregables/Entregables_3/Modelado_3D/Assembly 2 (1).stl
185.0 x 192.0 x 113.9

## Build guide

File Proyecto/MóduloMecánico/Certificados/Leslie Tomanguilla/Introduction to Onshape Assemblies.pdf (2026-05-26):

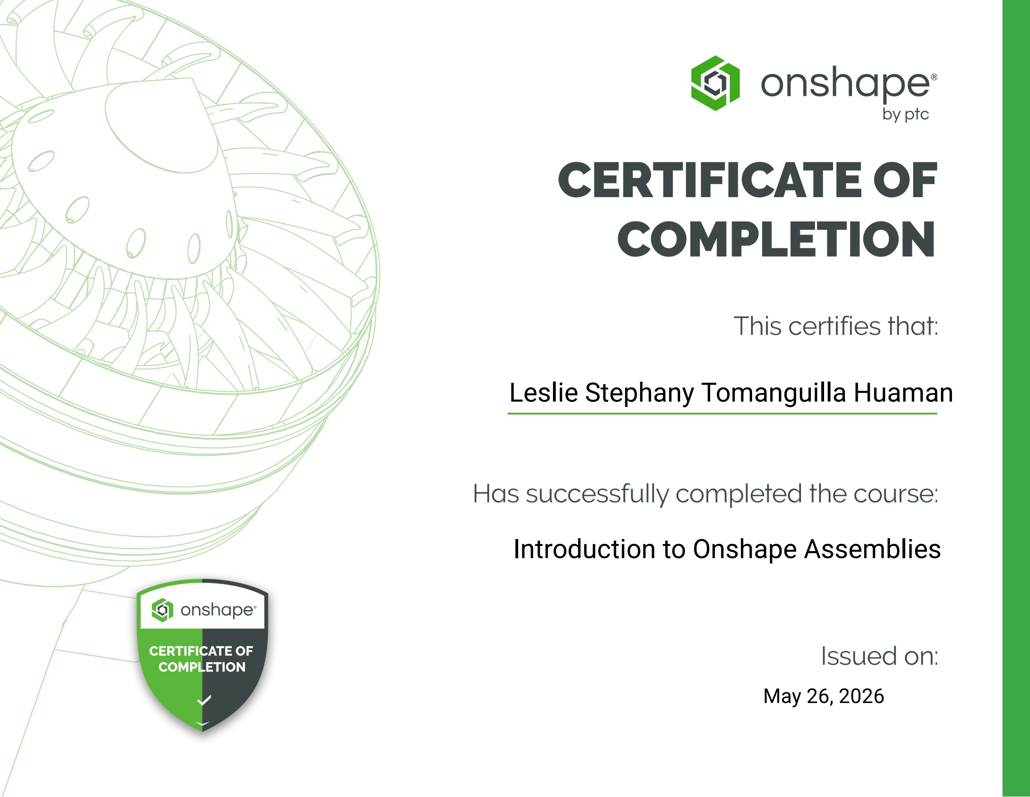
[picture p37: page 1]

Leslie Stephany Tomanguilla Huaman

May 26, 2026

Introduction to Onshape Assemblies

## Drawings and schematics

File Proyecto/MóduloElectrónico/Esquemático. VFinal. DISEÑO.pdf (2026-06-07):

Módulo sensor de distancia | Modulo Principal

# Módulo sensor de presencia

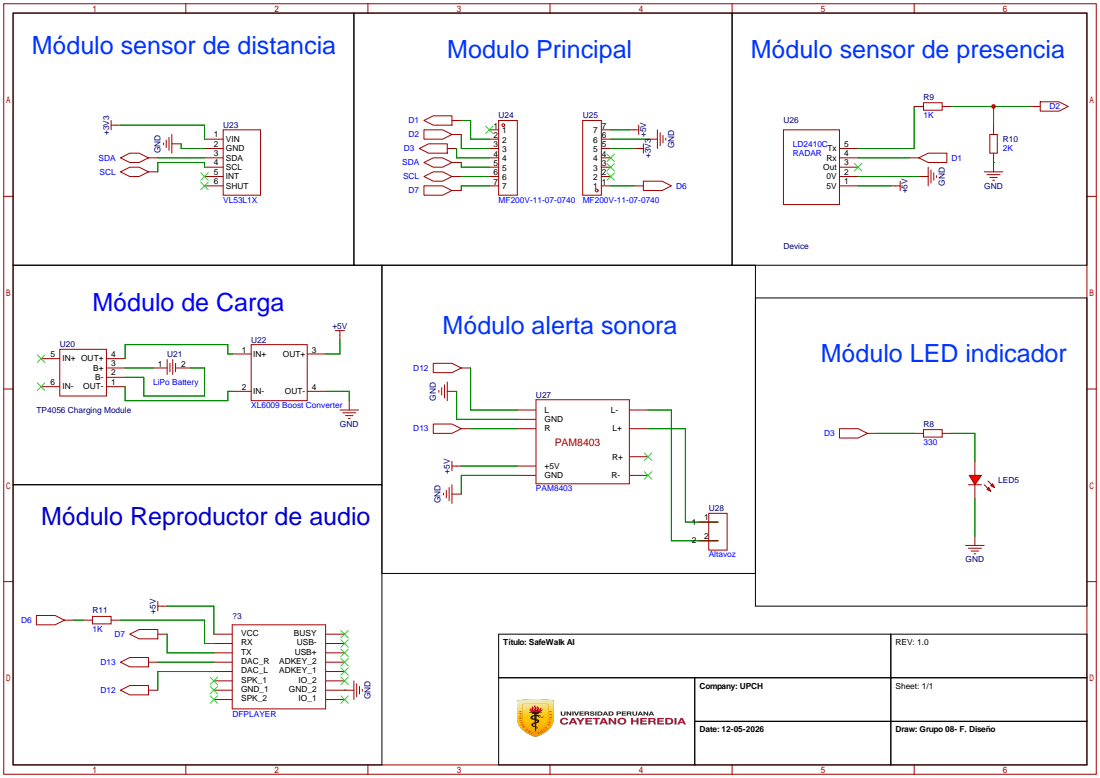
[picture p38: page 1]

Módulo Reproductor de audio

Título: SafeWalk AI | REV: 1.0

Company: UPCH | Sheet: 1/1

Date: 12-05-2026 | Draw: Grupo 08- F. Diseño

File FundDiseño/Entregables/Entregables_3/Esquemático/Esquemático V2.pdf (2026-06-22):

Módulo sensor de distancia | Modulo Principal

# Módulo sensor de presencia

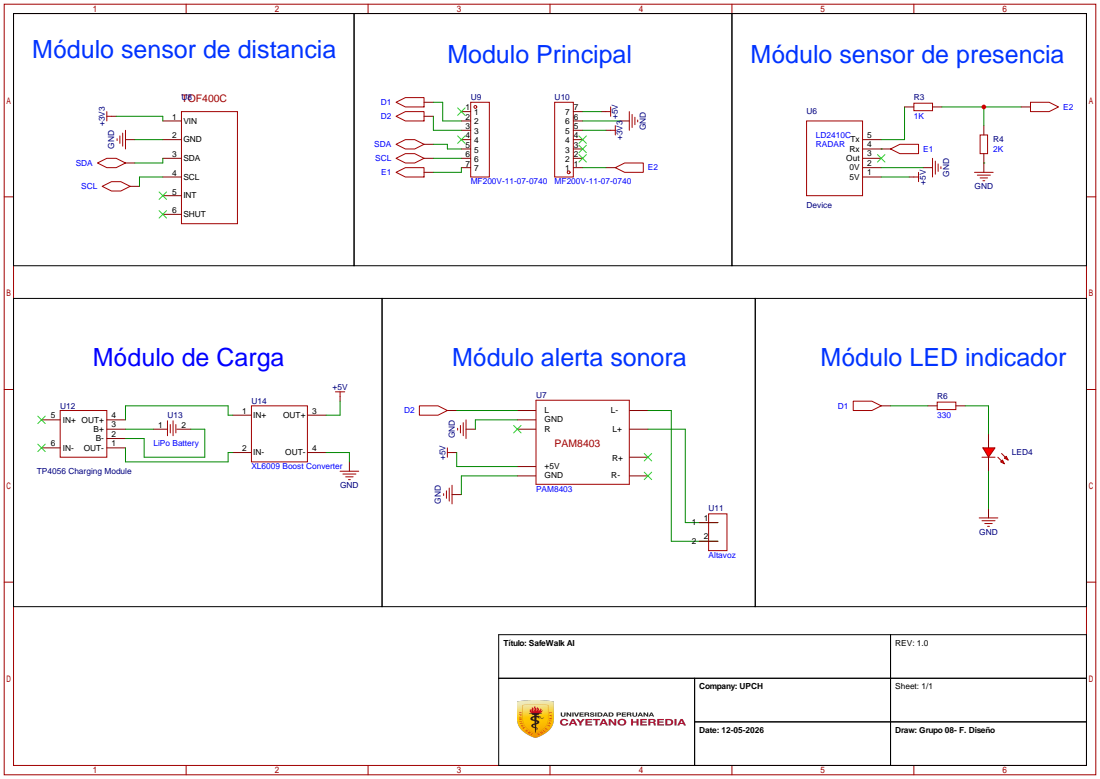
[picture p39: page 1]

Título: SafeWalk AI | REV: 1.0

Company: UPCH | Sheet: 1/1

Date: 12-05-2026 | Draw: Grupo 08- F. Diseño

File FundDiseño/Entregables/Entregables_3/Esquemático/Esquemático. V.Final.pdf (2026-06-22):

Módulo sensor de distancia | Módulo Principal

# Módulo sensor de presencia

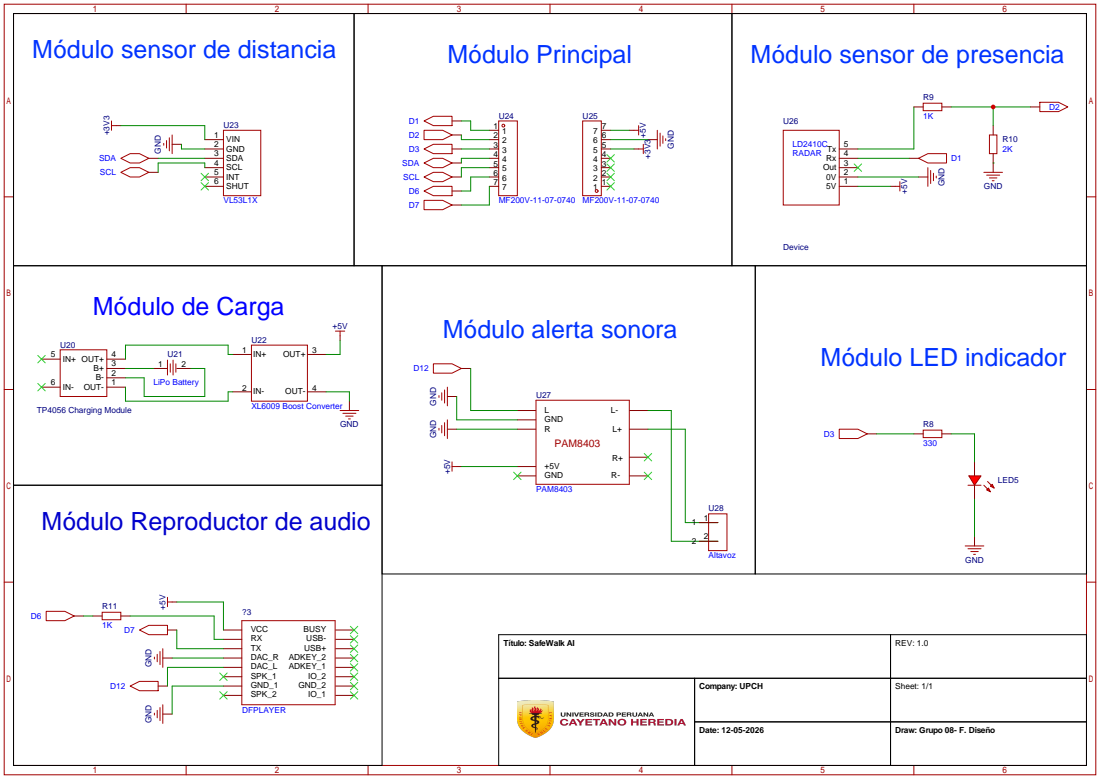
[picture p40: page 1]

Módulo Reproductor de audio GND

Título: SafeWalk AI | REV: 1.0

Company: UPCH | Sheet: 1/1

Date: 12-05-2026 | Draw: Grupo 08- F. Diseño

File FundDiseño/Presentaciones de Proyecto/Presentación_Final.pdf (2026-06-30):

## FUNDAMNETOS DE DISEÑO

# SAFE

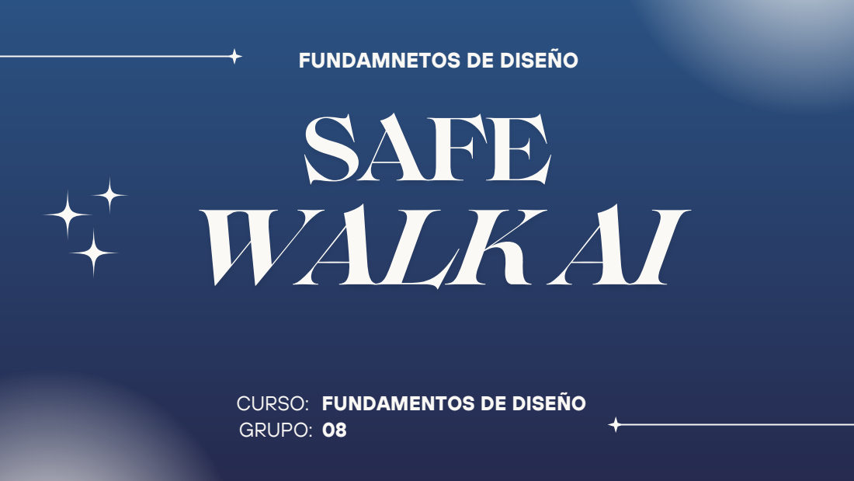
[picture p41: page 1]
WALK AI

CURSO: FUNDAMENTOS DE DISEÑO
GRUPO: 08

# "Imagina que memorizaste cada paso

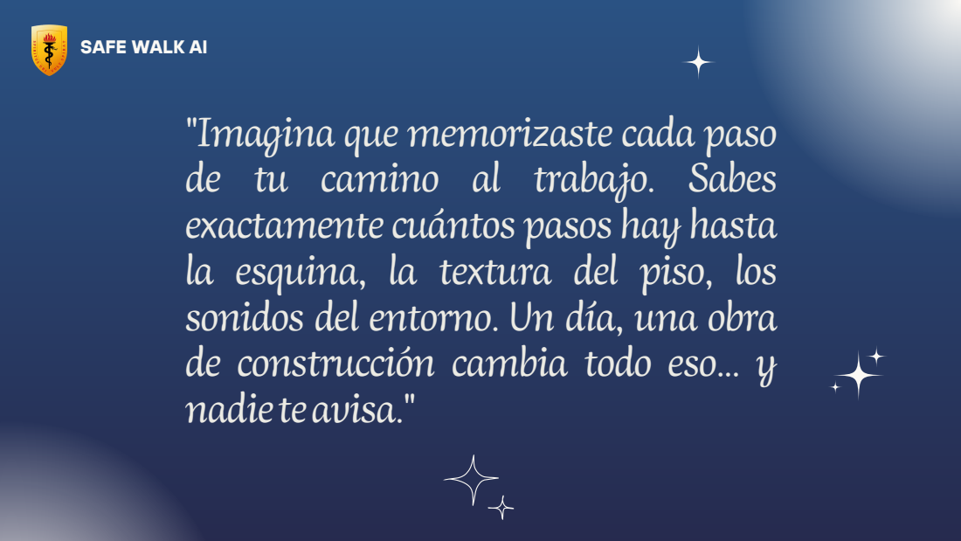
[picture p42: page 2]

SAFE WALK AI

de tu camino al trabajo. Sabes
exactamente cuántos pasos hay hasta
la esquina, la textura del piso, los
sonidos del entorno. Un día, una obra
de construcción cambia todo eso... y
nadieteavisa.

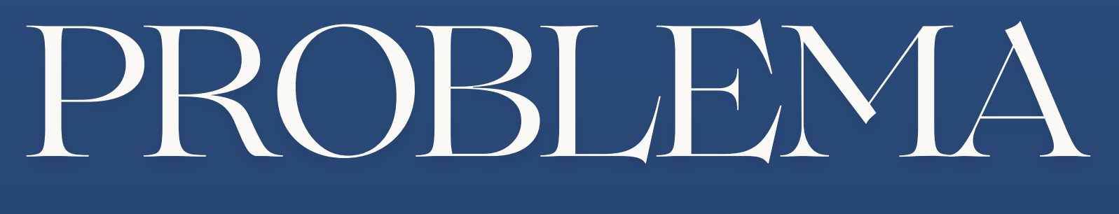
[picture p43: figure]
PROBLEMA

En el Perú, más de 1.9 millones de personas tienen limitaciones permanentes en la visión, y más de la mitad vive en zonas urbanas [1]. Cuando una obra altera una vereda, sus rutas memorizadas dejan de coincidir con la realidad, exponiéndolas a accidentes. La señalización actual es insuficiente y poco accesible [2]. Nadie las avisa sobre los riesgos en su camino.

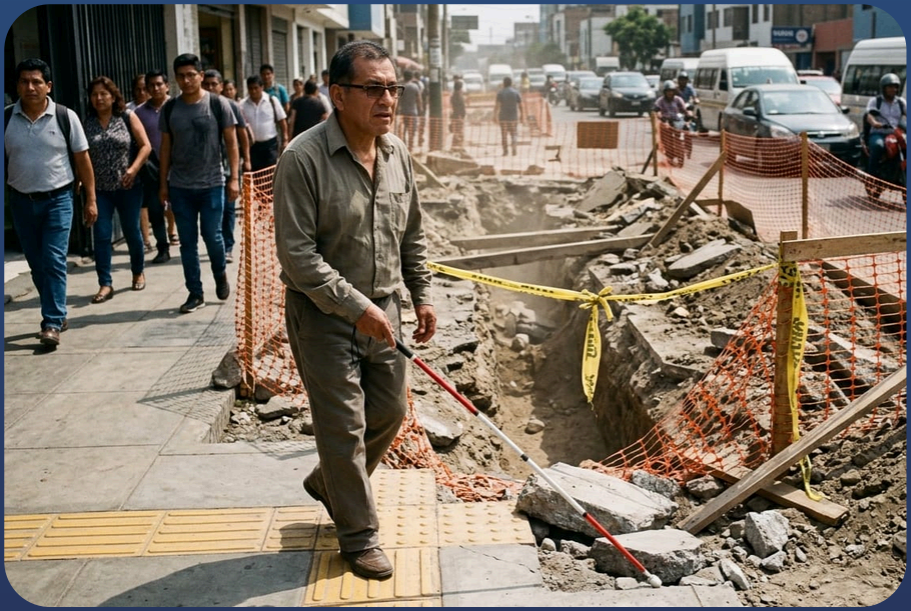
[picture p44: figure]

Imagen recreada con Gemini
¿Cómo podemos advertir de manera oportuna a una persona con discapacidad visual cuando se aproxima a una zona de construcción que representa un riesgo para su seguridad?

SAFE WALK AI

# SOLUCIÓN

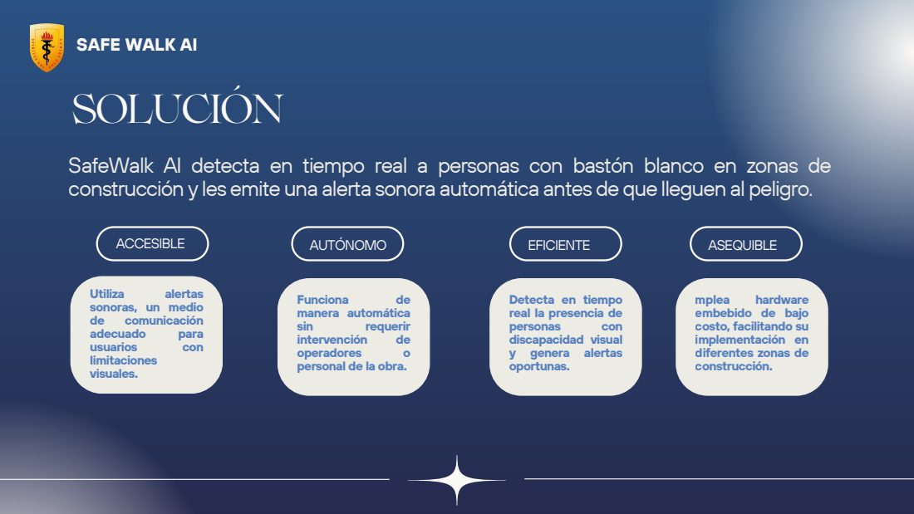
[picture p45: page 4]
SafeWalk AI detecta en tiempo real a personas con bastón blanco; en zonas de; ACCESIBLE; AUTÓNOMO; Utiliza; alertas; comunicación; adecuado; para; usuarios; con; Funciona; sin; requerir; intervención; operadores; EFICIENTE; ASEQUIBLE; personas; mplea; hardware

SAFE WALK AI

construcción y les emite una alerta sonora automática antes de que lleguen al peligro.

sonoras, un medio
limitaciones
visuales.

manera automática
personal de la obra.

Detecta en tiempo
real la presencia de
discapacidad visual
y genera alertas
oportunas.

embebido de bajo
costo, facilitando su
implementación en
diferentes zonas de
construcción.

# PROPUESTADEVALOR

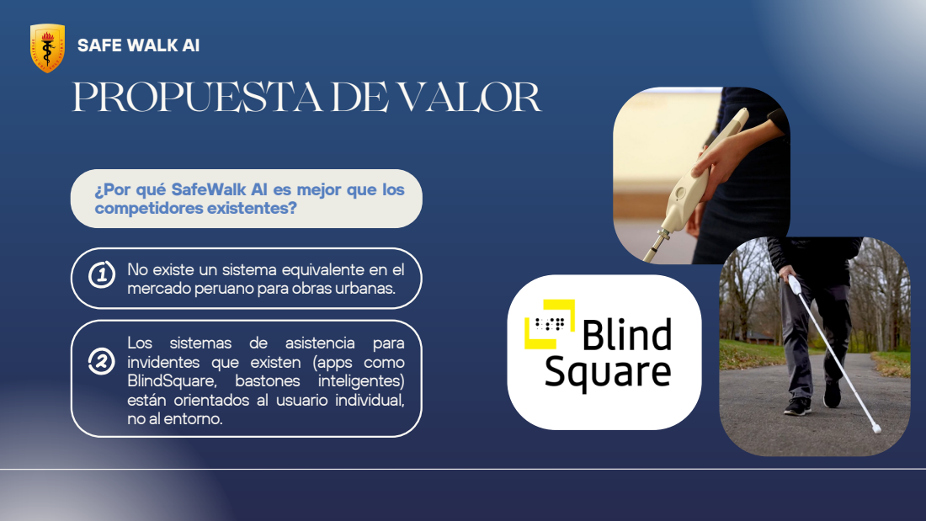
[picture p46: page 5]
están orientados; al usuario individual,

SAFE WALK AI

¿Por qué SafeWalk AI es mejor que los
competidores existentes?

No existe un sistema equivalente en el
mercado peruano para obras urbanas.

Los sistemas de asistencia para BlindSquare, bastones inteligentes)

invidentes que existen (apps como

no al entorno.

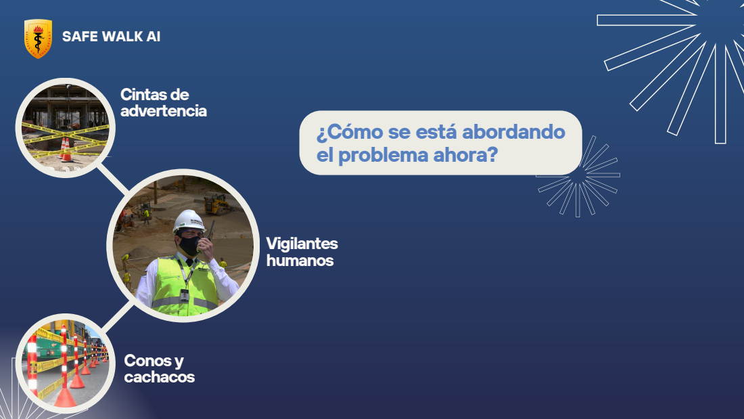
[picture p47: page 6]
Conos y cachacos; Cintasde advertencia; Vigilantes humanos

SAFE WALK AI

¿Cómo se está abordando
el problema ahora?

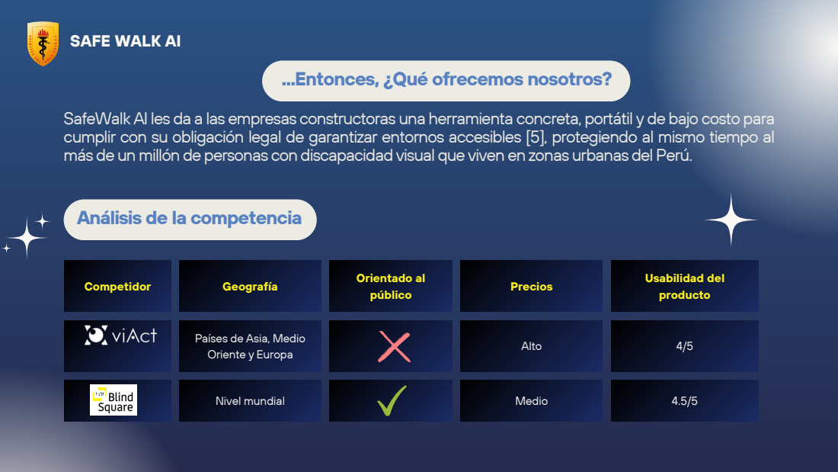
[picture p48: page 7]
Competidor; Geografía; Orientado al público; Precios; Usabilidad del producto; Alto; Nivel mundial; Medio

SAFE WALK AI

...Entonces, ¿Qué ofrecemos nosotros?

SafeWalkAI les da a las empresas constructoras una herramienta concreta, portátil y de bajo costo para
cumplir con su obligación legal de garantizar entornos accesibles [5], protegiendo al mismo tiempo al
más de un millón de personas con discapacidad visual que viven en zonas urbanas delPerú.

Análisis de la competencia

Países de Asia, Medio
Oriente y Europa

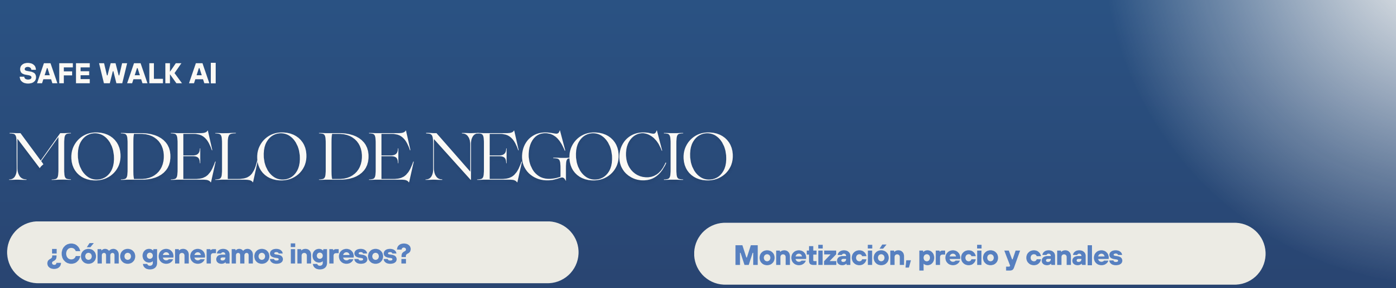
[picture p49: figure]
SAFE WALK AI; ¿Cómo generamos ingresos?; MODELODENEGOCIO; Monetización, precio y canales

Nuestro modelo se basa en el alquiler por obra. SafeWalk AI se instala directamente sobre el cachaco existente y se cobra por el tiempo que dura la construcción. Esto lo hace accesible para cualquier obra, grande o pequeña, y nos permite escalarrápidamente.

Nuestro modelo de negocio consiste en el alquiler por obra, donde cobramos un rango deS/. 300a S/. 500 mensuales por dispositivo, incluyendo en ese monto lo invertido, la mano de obra, el traslado, y el mantenimiento.
Buscaremos elrespaldo de CONADISpara abrir puertas con empresas constructoras.
El dispositivo se reutilizará en cada obra, haciendo el modelo sostenible y escalable.

# ESTRATEGIA

Empresas constructoras; Llegamos; empresa

SAFE WALK AI

¿Quiénes son nuestros clientes?

¿Cómo llegaríamos a ellos?

Presentamos SafeWalk AI a
CONADIS para obtener su aval
como herramienta de accesibilidad.

Municipalidades (a largo plazo)

constructora mediante una prueba
piloto gratuita en una obra real de
Lima a cambio de retroalimentación
y validando el sistema en el campo.

Empresas de señalización vial
(a largo plazo)

# TRACCIÓN

diseñada; montaje; para; entrenado; con; imágenes; Prototipo; funcional; del; sistema; detección; XIAO ESP32S3 y Roboflow.

SAFE WALK AI

¿Qué hemos logrado?

Carcasa en PLA
impresa en 3D
con sistema de
cachacos.

Modelo
con 2 clases de
detección
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

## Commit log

2026-03-17 Copiando los elementos al repositorio nuestro
    [WeatherStation_v2_Base_v2.stl, WeatherStation_v2_windmill_v4.stl]
2026-04-01 Update Nuevo Documento de texto.txt
2026-04-20 arreglo de la patente 3
2026-04-20 agregado de fotos para la patente 3
2026-04-28 cambio de nombre
2026-04-28 modificacion de nombre
2026-04-28 agregado de certificaciones
2026-04-28 creacion de carpetas
2026-04-28 Rename Captura de pantalla 2026-04-28 161642.png to Certificado_Alex.png
2026-04-28 Rename Captura de pantalla 2026-04-28 161541.png to Imagen del certificado01
2026-04-28 Rename Captura de pantalla 2026-04-28 161655.png to Certificado_Alex_Cad.png
2026-04-28 Rename Captura de pantalla 2026-04-28 161552.png to Imagen del certificado 02
2026-04-28 agregado de bocetos
2026-05-17 presentacion de onshape
2026-05-17 entrega de avance de onshape
2026-05-19 creacion de carpetas para el taller 10
2026-05-26 Rename Cad Basic.pdf to CAD Basic.pdf
2026-06-16 Rename FundDiseño/Talleres/Informe de desarrollo- Comunicación Bluetooth entre ESP32 y pantalla LCD I2C.pdf to FundDiseño/Talleres/Taller 14/Informe de desarrollo- Comunicación Bluetooth entre ESP32 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
2026-06-16 Rename Informe de desarrollo- Comunicación Bluetooth entre ESP32 y pantalla LCD I2C.pdf to Informe de desarrollo- Comunicación Bluetooth entre ESP32 y pantalla LCD I2C.md
2026-06-16 Rename # Control de ángulo con Bluetooth y WIFI con el MIT App Inventor.txt to # Control de ángulo con Bluetooth y WIFI con el MIT App Inventor.md
2026-06-16 Rename # Ploteo de mensaje en LCD 2x16 a través.txt to # Ploteo de mensaje en LCD 2x16 a través.md
2026-06-16 Update # Control de ángulo con Bluetooth y WIFI con el MIT App Inventor.md
2026-06-16 Rename # Ploteo de mensaje en LCD 2x16 a través.jpeg to # IMAGEN Ploteo de mensaje en LCD 2x16 a través.jpeg
2026-06-16 Create Link Video - Control de ángulo con Bluetooth y WIFI con el MIT App Inventor
2026-06-22 Create Descripcion de aporte de tesis.md
2026-06-22 Create Descripción y aportes de normas.md
2026-06-23 Create Descripcion y aportes de patentes.md
2026-06-23 Create Descripcion y aporte de productos.md
2026-06-23 Update and rename README.md to Descripción y aporte de artículos.md
2026-06-23 Update Descripcion de aporte de tesis.md
2026-06-23 Update Descripción y aportes de normas.md
2026-06-23 Update Descripcion y aportes de patentes.md
2026-06-29 Update Descripcion y aporte de productos.md
